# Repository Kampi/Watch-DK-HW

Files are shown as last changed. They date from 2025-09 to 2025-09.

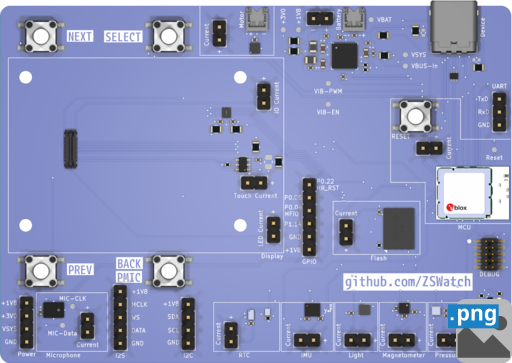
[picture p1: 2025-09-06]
production/watch-dk-RELEASED/HTML/images/cat_png_3d_viewer_top_ZSWatch-Watch-DevKit-top.png

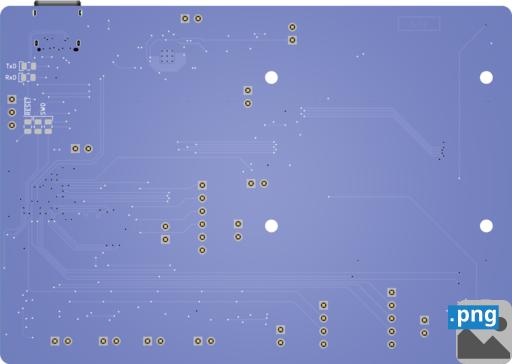
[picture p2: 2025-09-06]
production/watch-dk-RELEASED/HTML/images/cat_png_3d_viewer_bottom_ZSWatch-Watch-DevKit-bottom.png

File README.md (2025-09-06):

# ZSWatch-Watch-DevKit



## 📑 Table of Contents

- [ZSWatch-Watch-DevKit](#zswatch-watch-devkit)
  - [📑 Table of Contents](#-table-of-contents)
  - [📖 About](#-about)
  - [📂 Directory Breakdown](#-directory-breakdown)
  - [Purchasing](#purchasing)
  - [👨‍💻 Maintainer](#-maintainer)

## 📖 About

The **ZSWatch-Watch-DevKit** project provides the hardware design and production files for a smartwatch development board tailored to the ZSWatch ecosystem.
It is built with **KiCad** and integrates a full **CI/CD pipeline** using **KiBot**, ensuring reproducible outputs for documentation, manufacturing, and releases.

Key features:

- 🛠️ Open-source hardware design
- 📦 Automated generation of Gerber, BoM, and documentation via KiBot
- 🔄 Workflow stages (DRAFT → PRELIMINARY → CHECKED → RELEASED) for structured releases
- 📝 Clear documentation and changelog to track progress
- 🌍 Designed with collaboration and transparency in mind

Complete

Please check the [wiki](https://github.com/ZSWatch/ZSWatch/wiki) for more information about the project.

## 📂 Directory Breakdown

- **`.github`**: GitHub related files
- **`.gitignore`**: Ignored files list
- **`devkit`**: KiCad project for the devkit
- **`production/PCBWay`**: Manufacturing outputs (Gerbers, etc.) for PCBWay
- **`CHANGELOG.md`**: Version history
- **`LICENSE`**: Project license (GPL-3.0)
- **`README.md`**: Project overview

## Purchasing

TBD

## 👨‍💻 Maintainer

- [Daniel Kampert](mailto:danielkameprt@kampis-elektroecke.de)

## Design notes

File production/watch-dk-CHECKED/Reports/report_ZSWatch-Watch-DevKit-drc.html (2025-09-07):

Logo

| DRC report for ZSWatch-Watch-DevKit
| PCB: ZSWatch-Watch-DevKit Revision: 1.2.0+ (Unreleased) Date: 2025-09-07T20:00:18+0000 KiCad Version: 9.0.1 | Errors: 1 Warnings: 46 Total: 47

Violations

Type | Description | Details
clearance | Clearance violation (netclass 'Default' clearance 0.1250 mm; actual 0.0000 mm) | @(172.1 mm, 116.2 mm): Rectangle [] on B.Cu @(176.15 mm, 117.5 mm): PCB text '1.2.0+ (Unreleased)' on B.Cu
lib_footprint_issues | The current configuration does not include the footprint library 'Package_DFN_Kampi'. | @(253.9 mm, 171.4 mm): Footprint Q403
lib_footprint_mismatch | Footprint 'SOT-666' does not match copy in library 'Package_TO_SOT_SMD'. | @(246.8 mm, 127.7875 mm): Footprint IC602
lib_footprint_issues | The current configuration does not include the footprint library 'Wuerth'. | @(166.0 mm, 166.0 mm): Footprint S503
lib_footprint_issues | The current configuration does not include the footprint library 'Testpoints'. | @(222.2 mm, 129.2 mm): Footprint TP502
lib_footprint_issues | The current configuration does not include the footprint library 'Wuerth'. | @(166.0 mm, 120.0 mm): Footprint S504
lib_footprint_issues | The current configuration does not include the footprint library 'Samtec'. | @(253.75 mm, 162.677 mm): Footprint X601
lib_footprint_mismatch | Footprint 'QFN-32-1EP_5x5mm_P0.5mm_EP3.6x3.6mm_ThermalVias' does not match copy in library 'Package_DFN_QFN'. | @(225.38779 mm, 123.8304 mm): Footprint IC401
lib_footprint_issues | The current configuration does not include the footprint library 'Molex'. | @(208.25 mm, 116.7 mm): Footprint X509
lib_footprint_issues | The current configuration does not include the footprint library 'Broadcom'. | @(229.2925 mm, 173.55 mm): Footprint IC501
lib_footprint_issues | The current configuration does not include the footprint library 'Package_QFN'. | @(207.85 mm, 122.35 mm): Footprint IC505
lib_footprint_mismatch | Footprint 'WSON-8-1EP_8x6mm_P1.27mm_EP3.4x4.3mm' does not match copy in library 'Package_SON'. | @(235.995 mm, 157.65 mm): Footprint IC603
lib_footprint_issues | The current configuration does not include the footprint library 'Testpoints'. | @(216.4 mm, 118.7 mm): Footprint TP403
lib_footprint_issues | The current configuration does not include the footprint library 'Package_SON_Kampi'. | @(210.3 mm, 173.975 mm): Footprint IC506
lib_footprint_issues | The current configuration does not include the footprint library 'Testpoints'. | @(213.4 mm, 118.7 mm): Footprint TP404
lib_footprint_issues | The current configuration does not include the footprint library 'Knowles'. | @(168.485 mm, 173.575 mm): Footprint MK501
lib_footprint_issues | The current configuration does not include the footprint library 'Molex'. | @(227.2 mm, 116.7 mm): Footprint X402
lib_footprint_issues | The current configuration does not include the footprint library 'Micro Crystal'. | @(207.1 mm, 174.535 mm): Footprint IC507
lib_footprint_issues | The current configuration does not include the footprint library 'Package_LGA_Kampi'. | @(243.3 mm, 173.7575 mm): Footprint IC504
lib_footprint_issues | The current configuration does not include the footprint library 'Testpoints'. | @(222.2 mm, 133.3 mm): Footprint TP501
lib_footprint_mismatch | Footprint 'USB_C_Receptacle_Amphenol_12401610E4-2A' does not match copy in library 'Connector_USB'. | @(246.8 mm, 118.2 mm): Footprint X603
lib_footprint_issues | The current configuration does not include the footprint library 'Testpoints'. | @(254.7 mm, 142.2 mm): Footprint TP601
lib_footprint_issues | The current configuration does not include the footprint library 'Package_LGA_Kampi'. | @(219.1 mm, 173.55 mm): Footprint IC502
lib_footprint_issues | The current configuration does not include the footprint library 'Testpoints'. | @(172.2 mm, 172.9 mm): Footprint TP503
lib_footprint_issues | The current configuration does not include the footprint library 'Inductor_SMD_Kampi'. | @(218.73841 mm, 124.6594 mm): Footprint L401
lib_footprint_issues | The current configuration does not include the footprint library 'uBlox'. | @(251.0 mm, 150.75 mm): Footprint M601
lib_footprint_issues | The current configuration does not include the footprint library 'Package_LGA_Kampi'. | @(237.0625 mm, 173.225 mm): Footprint IC503
lib_footprint_issues | The current configuration does not include the footprint library 'Inductor_SMD_Kampi'. | @(219.24641 mm, 122.1194 mm): Footprint L402
lib_footprint_issues | The current configuration does not include the footprint library 'Wuerth'. | @(191.0 mm, 166.0 mm): Footprint S502
lib_footprint_issues | The current configuration does not include the footprint library 'Package_DFN_Kampi'. | @(252.0 mm, 177.0 mm): Footprint Q401
lib_footprint_issues | The current configuration does not include the footprint library 'Testpoints'. | @(170.2 mm, 176.6 mm): Footprint TP504
lib_footprint_issues | The current configuration does not include the footprint library 'Wuerth'. | @(191.0 mm, 120.0 mm): Footprint S501
lib_footprint_issues | The current configuration does not include the footprint library 'Testpoints'. | @(230.6 mm, 116.725 mm): Footprint TP402
lib_footprint_issues | The current configuration does not include the footprint library 'EastRising'. | @(171.7 mm, 142.1 mm): Footprint X608
lib_footprint_issues | The current configuration does not include the footprint library 'Package_QFN'. | @(202.295 mm, 134.95 mm): Footprint IC604
lib_footprint_issues | The current configuration does not include the footprint library 'Testpoints'. | @(237.3 mm, 125.8 mm): Footprint TP401
lib_footprint_issues | The current configuration does not include the footprint library 'Package_DFN_Kampi'. | @(252.0 mm, 178.2 mm): Footprint Q404
lib_footprint_issues | The current configuration does not include the footprint library 'Testpoints'. | @(237.3 mm, 123.6 mm): Footprint TP405
lib_footprint_issues | The current configuration does not include the footprint library 'Package_DFN_Kampi'. | @(253.9 mm, 174.9 mm): Footprint Q402
lib_footprint_issues | The current configuration does not include the footprint library 'Wuerth'. | @(239.3 mm, 135.7 mm): Footprint S601

Schematic parity

Type | Description | Details
duplicate_footprints | Duplicate footprints | @(163.0 mm, 157.0 mm): Footprint REF** @(205.0 mm, 157.0 mm): Footprint REF**
duplicate_footprints | Duplicate footprints | @(205.0 mm, 128.0 mm): Footprint REF** @(205.0 mm, 157.0 mm): Footprint REF**
duplicate_footprints | Duplicate footprints | @(163.0 mm, 128.0 mm): Footprint REF** @(205.0 mm, 157.0 mm): Footprint REF**
extra_footprint | Extra footprint | @(205.0 mm, 157.0 mm): Footprint REF**
extra_footprint | Extra footprint | @(163.0 mm, 157.0 mm): Footprint REF**
extra_footprint | Extra footprint | @(205.0 mm, 128.0 mm): Footprint REF**
extra_footprint | Extra footprint | @(163.0 mm, 128.0 mm): Footprint REF**

Generated by KiBot (https://github.com/INTI-CMNB/KiBot/) v1.8.4

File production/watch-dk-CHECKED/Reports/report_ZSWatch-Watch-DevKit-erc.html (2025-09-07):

Logo

| ERC report for ZSWatch-Watch-DevKit
| Schematic: ZSWatch-Watch-DevKit Revision: 1.2.0+ (Unreleased) Date: 2025-09-07T20:00:15+0000 KiCad Version: 9.0.1 | Errors: 0 Warnings: 77 Total: 77

Sheet / (ZSWatch-Watch-DevKit.kicad_sch)

Type | Description | Details
lib_symbol_issues | The current configuration does not include the symbol library 'Misc' | @(0.5207 mm, 0.3175 mm): Symbol J501 [Jumper]
footprint_link_issues | The current configuration does not include the footprint library 'Broadcom'. | @(0.3048 mm, 0.5461 mm): Symbol IC501 [APDS-9306-065]
footprint_link_issues | The current configuration does not include the footprint library 'Wuerth'. | @(0.254 mm, 1.0033 mm): Symbol S501 [SW_Push]
footprint_link_issues | The current configuration does not include the footprint library 'Wuerth'. | @(0.254 mm, 1.1176 mm): Symbol S502 [SW_Push]
footprint_link_issues | The current configuration does not include the footprint library 'Wuerth'. | @(0.254 mm, 1.2319 mm): Symbol S503 [SW_Push]
footprint_link_issues | The current configuration does not include the footprint library 'Wuerth'. | @(0.254 mm, 1.3462 mm): Symbol S504 [SW_Push]
lib_symbol_issues | The current configuration does not include the symbol library 'Misc' | @(1.0541 mm, 0.9525 mm): Symbol J502 [Jumper]
footprint_link_issues | The current configuration does not include the footprint library 'Knowles'. | @(0.8636 mm, 1.27 mm): Symbol MK501 [SPK0641HT4H-1]
lib_symbol_issues | The current configuration does not include the symbol library 'Knowles' | @(0.8636 mm, 1.27 mm): Symbol MK501 [SPK0641HT4H-1]
footprint_link_issues | The current configuration does not include the footprint library 'Testpoints'. | @(1.0541 mm, 1.2446 mm): Symbol TP503 [TestPoint]
footprint_link_issues | The current configuration does not include the footprint library 'Testpoints'. | @(1.0541 mm, 1.2954 mm): Symbol TP504 [TestPoint]
footprint_link_issues | The current configuration does not include the footprint library 'Package_LGA_Kampi'. | @(1.9558 mm, 0.7747 mm): Symbol IC502 [BMI270]
lib_symbol_issues | The current configuration does not include the symbol library 'Bosch_Kampi' | @(1.9558 mm, 0.7747 mm): Symbol IC502 [BMI270]
lib_symbol_issues | The current configuration does not include the symbol library 'Misc' | @(2.2352 mm, 0.4191 mm): Symbol J503 [Jumper]
footprint_link_issues | The current configuration does not include the footprint library 'Package_LGA_Kampi'. | @(2.7051 mm, 0.762 mm): Symbol IC504 [BMP581]
lib_symbol_issues | The current configuration does not include the symbol library 'Bosch_Kampi' | @(2.7051 mm, 0.762 mm): Symbol IC504 [BMP581]
lib_symbol_issues | The current configuration does not include the symbol library 'Misc' | @(2.9337 mm, 0.3937 mm): Symbol J505 [Jumper]
footprint_link_issues | The current configuration does not include the footprint library 'Package_LGA_Kampi'. | @(2.6162 mm, 1.5875 mm): Symbol IC503 [LIS2MDLTR]
lib_symbol_issues | The current configuration does not include the symbol library 'ST' | @(2.6162 mm, 1.5875 mm): Symbol IC503 [LIS2MDLTR]
lib_symbol_issues | The current configuration does not include the symbol library 'Misc' | @(2.9083 mm, 1.2827 mm): Symbol J504 [Jumper]
footprint_link_issues | The current configuration does not include the footprint library 'Testpoints'. | @(3.1623 mm, 0.4826 mm): Symbol TP501 [TestPoint]
footprint_link_issues | The current configuration does not include the footprint library 'Testpoints'. | @(3.1877 mm, 0.4826 mm): Symbol TP502 [TestPoint]
footprint_link_issues | The current configuration does not include the footprint library 'Package_QFN'. | @(3.3782 mm, 0.6096 mm): Symbol IC505 [DRV2603RUNT]
lib_symbol_issues | The current configuration does not include the symbol library 'Texas Instruments' | @(3.3782 mm, 0.6096 mm): Symbol IC505 [DRV2603RUNT]
lib_symbol_issues | The current configuration does not include the symbol library 'Misc' | @(3.5687 mm, 0.3429 mm): Symbol J506 [Jumper]
footprint_link_issues | The current configuration does not include the footprint library 'Molex'. | @(3.6068 mm, 0.6223 mm): Symbol X509 [Conn_01x02]
footprint_link_issues | The current configuration does not include the footprint library 'Package_SON_Kampi'. | @(3.4544 mm, 1.3081 mm): Symbol IC506 [PCA9306JK]
lib_symbol_issues | The current configuration does not include the symbol library 'NXP' | @(3.4544 mm, 1.3081 mm): Symbol IC506 [PCA9306JK]
footprint_link_issues | The current configuration does not include the footprint library 'Micro Crystal'. | @(3.81 mm, 1.3843 mm): Symbol IC507 [RV-8263-C8]
lib_symbol_issues | The current configuration does not include the symbol library 'Micro Crystal' | @(3.81 mm, 1.3843 mm): Symbol IC507 [RV-8263-C8]
lib_symbol_issues | The current configuration does not include the symbol library 'Misc' | @(4.0005 mm, 1.0668 mm): Symbol J507 [Jumper]
footprint_link_issues | The current configuration does not include the footprint library 'Testpoints'. | @(0.4191 mm, 1.1811 mm): Symbol TP601 [TestPoint]
footprint_link_issues | The current configuration does not include the footprint library 'Wuerth'. | @(0.4191 mm, 1.3081 mm): Symbol S601 [SW_Push]
footprint_link_issues | The current configuration does not include the footprint library 'uBlox'. | @(0.8636 mm, 1.1049 mm): Symbol M601 [NORA-B106]
lib_symbol_issues | The current configuration does not include the symbol library 'uBlox' | @(0.8636 mm, 1.1049 mm): Symbol M601 [NORA-B106]
footprint_link_issues | The current configuration does not include the footprint library 'uBlox'. | @(1.397 mm, 1.0287 mm): Symbol M601 [NORA-B106]
lib_symbol_issues | The current configuration does not include the symbol library 'uBlox' | @(1.397 mm, 1.0287 mm): Symbol M601 [NORA-B106]
lib_symbol_issues | The current configuration does not include the symbol library 'ON Semiconductor' | @(0.5334 mm, 1.9685 mm): Symbol IC601 [FAN5622]
footprint_link_issues | The current configuration does not include the footprint library 'uBlox'. | @(2.159 mm, 1.2319 mm): Symbol M601 [NORA-B106]
lib_symbol_issues | The current configuration does not include the symbol library 'uBlox' | @(2.159 mm, 1.2319 mm): Symbol M601 [NORA-B106]
footprint_link_issues | The current configuration does not include the footprint library 'Samtec'. | @(0.4191 mm, 2.5527 mm): Symbol X601 [Conn_ARM_JTAG_SWD_10]
lib_symbol_issues | The current configuration does not include the symbol library 'Misc' | @(2.2733 mm, 1.7145 mm): Symbol J601 [Jumper]
lib_symbol_issues | The current configuration does not include the symbol library 'Infineon' | @(2.3749 mm, 1.9939 mm): Symbol IC603 [S25FS512SAGNFI010]
lib_symbol_issues | The current configuration does not include the symbol library 'Misc' | @(3.2766 mm, 1.1684 mm): Symbol J602 [Jumper]
footprint_link_issues | The current configuration does not include the footprint library 'Package_QFN'. | @(3.5179 mm, 0.762 mm): Symbol IC604 [NTS0104GU12 (XQFN12)]
lib_symbol_issues | The current configuration does not include the symbol library 'NXP' | @(3.5179 mm, 0.762 mm): Symbol IC604 [NTS0104GU12 (XQFN12)]
footprint_link_issues | The current configuration does not include the footprint library 'EastRising'. | @(3.5433 mm, 1.4605 mm): Symbol X608 [GC9A01A_CST816S]
lib_symbol_issues | The current configuration does not include the symbol library 'Display' | @(3.5433 mm, 1.4605 mm): Symbol X608 [GC9A01A_CST816S]
lib_symbol_issues | The current configuration does not include the symbol library 'Misc' | @(3.8227 mm, 1.1684 mm): Symbol J604 [Jumper]
lib_symbol_issues | The current configuration does not include the symbol library 'Misc' | @(3.7338 mm, 1.6891 mm): Symbol J603 [Jumper]
footprint_link_issues | The current configuration does not include the footprint library 'Package_DFN_Kampi'. | @(0.2794 mm, 0.7493 mm): Symbol Q401 [PMZ550UNE]
lib_symbol_issues | The current configuration does not include the symbol library 'Nexperia' | @(0.2794 mm, 0.7493 mm): Symbol Q401 [PMZ550UNE]
footprint_link_issues | The current configuration does not include the footprint library 'Package_DFN_Kampi'. | @(0.4953 mm, 0.635 mm): Symbol Q404 [PMZB320UPE]
lib_symbol_issues | The current configuration does not include the symbol library 'Nexperia' | @(0.4953 mm, 0.635 mm): Symbol Q404 [PMZB320UPE]
footprint_link_issues | The current configuration does not include the footprint library 'Package_DFN_Kampi'. | @(0.3937 mm, 1.27 mm): Symbol Q402 [PMZ550UNE]
lib_symbol_issues | The current configuration does not include the symbol library 'Nexperia' | @(0.3937 mm, 1.27 mm): Symbol Q402 [PMZ550UNE]
footprint_link_issues | The current configuration does not include the footprint library 'Testpoints'. | @(1.4351 mm, 0.4191 mm): Symbol TP401 [TestPoint]
footprint_link_issues | The current configuration does not include the footprint library 'Package_DFN_Kampi'. | @(0.3937 mm, 1.7145 mm): Symbol Q403 [PMZ550UNE]
lib_symbol_issues | The current configuration does not include the symbol library 'Nexperia' | @(0.3937 mm, 1.7145 mm): Symbol Q403 [PMZ550UNE]
footprint_link_issues | The current configuration does not include the footprint library 'Testpoints'. | @(1.7907 mm, 0.3556 mm): Symbol TP402 [TestPoint]
lib_symbol_issues | The current configuration does not include the symbol library 'Nordic' | @(1.7018 mm, 1.0414 mm): Symbol IC401 [nPM1300-QEXX]
footprint_link_issues | The current configuration does not include the footprint library 'Molex'. | @(1.9812 mm, 0.3683 mm): Symbol X402 [Conn_01x02]
footprint_link_issues | The current configuration does not include the footprint library 'Inductor_SMD_Kampi'. | @(2.1209 mm, 1.0287 mm): Symbol L401 [L]
footprint_link_issues | The current configuration does not include the footprint library 'Inductor_SMD_Kampi'. | @(2.2098 mm, 0.8509 mm): Symbol L402 [L]
footprint_link_issues | The current configuration does not include the footprint library 'Testpoints'. | @(2.4638 mm, 0.2794 mm): Symbol TP405 [TestPoint]
footprint_link_issues | The current configuration does not include the footprint library 'Testpoints'. | @(2.5146 mm, 0.8509 mm): Symbol TP403 [TestPoint]
footprint_link_issues | The current configuration does not include the footprint library 'Testpoints'. | @(2.5146 mm, 1.0287 mm): Symbol TP404 [TestPoint]
unresolved_variable | Unresolved text variable | @(0.8636 mm, 0.3175 mm): Text Box
unresolved_variable | Unresolved text variable | @(0.889 mm, 0.3556 mm): Text Box
unresolved_variable | Unresolved text variable | @(1.524 mm, 0.3175 mm): Text Box
unresolved_variable | Unresolved text variable | @(1.5494 mm, 0.3556 mm): Text Box
unresolved_variable | Unresolved text variable | @(2.1844 mm, 0.3175 mm): Text Box
unresolved_variable | Unresolved text variable | @(2.2098 mm, 0.3556 mm): Text Box

Sheet /Project Architecture/Power Management/ (Power.kicad_sch)

Type | Description | Details
pin_to_pin | Pins of type Bidirectional and Power output are connected | @(2.032 mm, 1.2065 mm): Symbol IC401 Pin 28 [LSIN1/VINLDO1, Bidirectional, Line] @(2.032 mm, 0.7366 mm): Symbol IC401 Pin 20 [V_{SYS}, Power output, Line]
pin_to_pin | Pins of type Bidirectional and Power output are connected | @(2.032 mm, 1.2319 mm): Symbol IC401 Pin 29 [LSOUT1/VOUTLDO1, Bidirectional, Line] @(2.1463 mm, 1.2192 mm): Symbol #FLG0402 Pin 1 [Power output, Line]

Sheet /Project Architecture/Peripherals/ (Peripherals.kicad_sch)

Type | Description | Details
pin_to_pin | Pins of type Bidirectional and Power output are connected | @(1.8288 mm, 0.7239 mm): Symbol IC502 Pin 1 [SDO, Bidirectional, Line] @(2.2352 mm, 1.4351 mm): Symbol #FLG0405 Pin 1 [Power output, Line]
pin_to_pin | Pins of type Bidirectional and Power output are connected | @(2.5781 mm, 0.7366 mm): Symbol IC504 Pin 5 [SDO, Bidirectional, Line] @(2.4765 mm, 0.7747 mm): Symbol #FLG0404 Pin 1 [Power output, Line]

Generated by KiBot (https://github.com/INTI-CMNB/KiBot/) v1.8.4

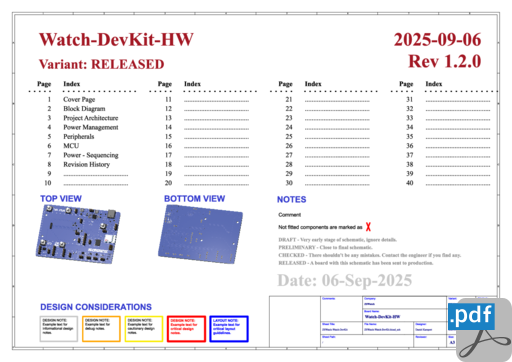
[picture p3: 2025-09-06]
production/watch-dk-RELEASED/HTML/images/cat_pdf_schematic_ZSWatch-Watch-DevKit-schematic.png

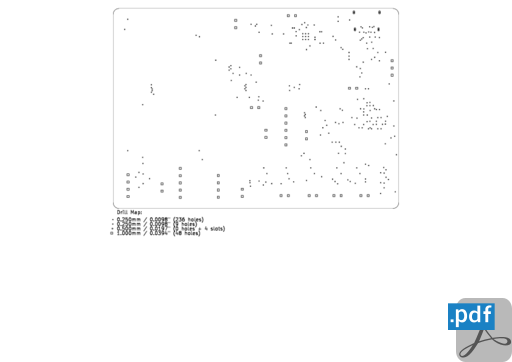
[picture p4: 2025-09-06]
production/watch-dk-RELEASED/HTML/images/cat_pdf_drill_map_ZSWatch-Watch-DevKit-PTH_drill_map.png

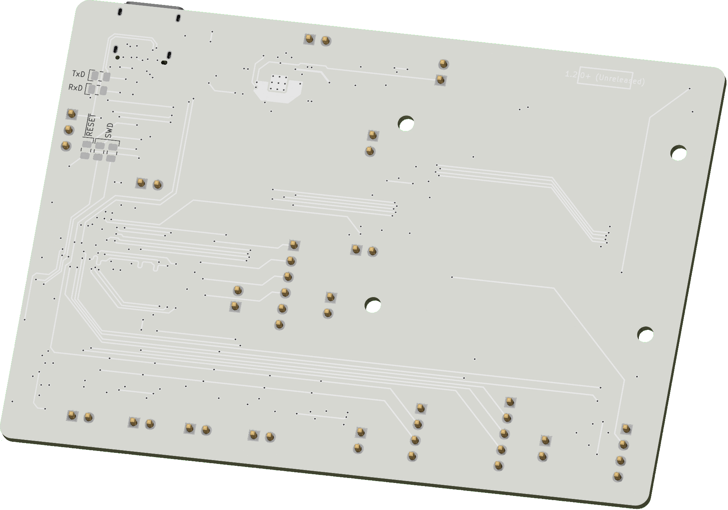
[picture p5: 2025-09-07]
production/watch-dk-CHECKED/Images/ZSWatch-Watch-DevKit-angled_bottom.png

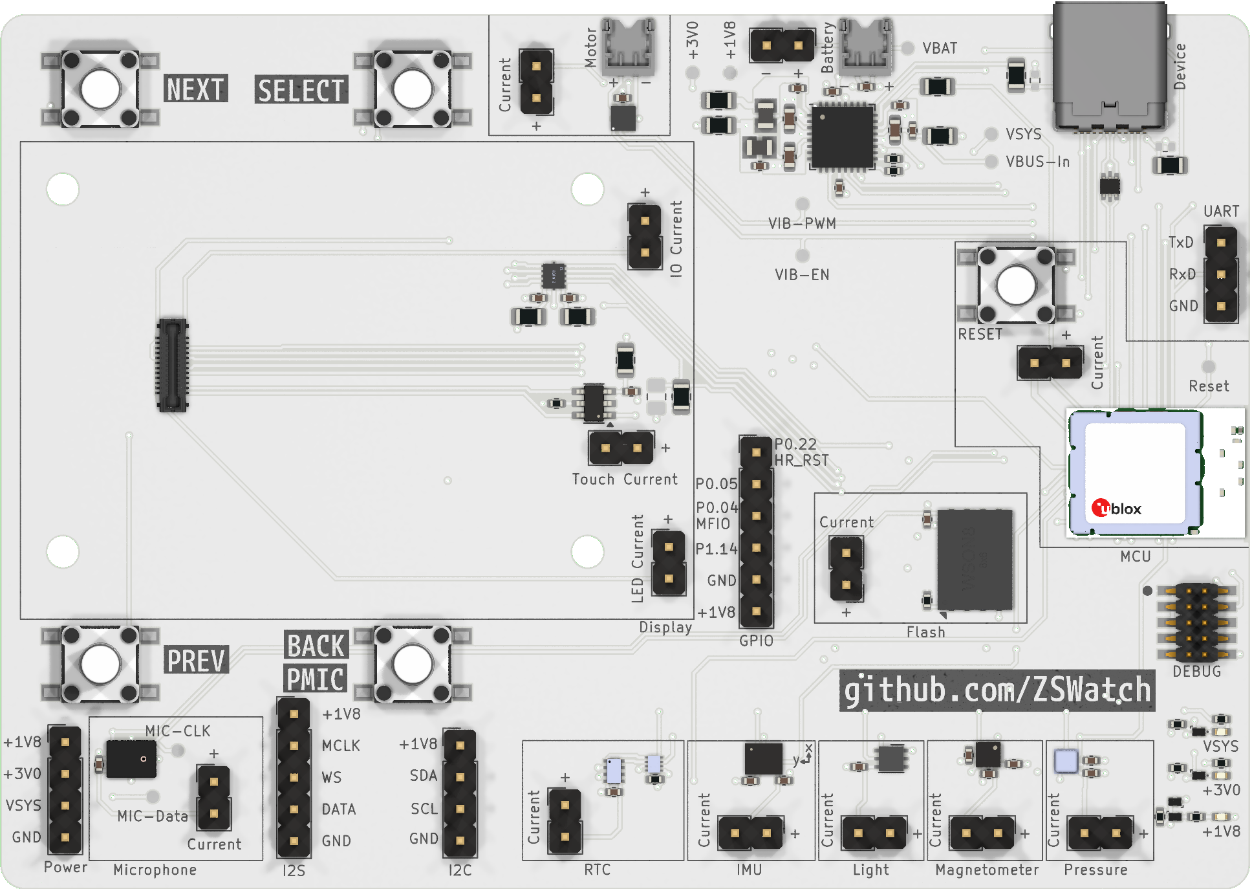
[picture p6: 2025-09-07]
production/watch-dk-CHECKED/Images/ZSWatch-Watch-DevKit-top.png

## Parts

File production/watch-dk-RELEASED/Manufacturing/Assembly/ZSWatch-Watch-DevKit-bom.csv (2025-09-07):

Row | Quantity Per PCB | References | Value | Datasheet | Footprint | Description | manf | manf# | mouser#
1 | 13 | C402 C501 C502 C503 C504 C507 C508 C509 C510 C511 C602 C603 C604 | 100n | https://datasheets.kyocera-avx.com/KGM_X7R.pdf | C_0402_1005Metric | Unpolarized capacitor, small symbol | KYOCERA AVX | 0402ZC104KAT4A | 581-0402ZC104KAT4A
2 | 1 | C505 | 220n | https://datasheets.kyocera-avx.com/KGM_X7R.pdf | C_0402_1005Metric | Unpolarized capacitor, small symbol | KYOCERA AVX | 04023C224KAT2A | 581-04023C224KAT2A
3 | 3 | C401 C404 C601 | 1u | https://datasheets.kyocera-avx.com/cx5r.pdf | C_0402_1005Metric | Unpolarized capacitor, small symbol | KYOCERA AVX | 04023D105KAT2A | 581-04023D105KAT2A
4 | 1 | C403 | 2u2 | https://datasheets.kyocera-avx.com/cx5r.pdf | C_0402_1005Metric | Unpolarized capacitor, small symbol | KYOCERA AVX | 0402ZD225MAT2A | 581-0402ZD225MAT2A
5 | 4 | C405 C407 C410 C506 | 10u | https://search.murata.co.jp/Ceramy/image/img/A01X/G101/ENG/GRJ155R60J106ME11-02A.pdf | C_0402_1005Metric | Unpolarized capacitor, small symbol | Murata Electronics | GRJ155R60J106ME11D | 81-GRJ155R60J106ME11D
6 | 3 | C406 C408 C409 | 10u | https://datasheets.kyocera-avx.com/cx5r-KGM.pdf | C_0603_1608Metric | Unpolarized capacitor, small symbol | KYOCERA AVX | KGM15CR50J106MT | 581-KGM15CR50J106MT
7 | 1 | D403 | +1V8 | https://www.mouser.de/datasheet/3/389/1/SSF-LXH100GD-RP.pdf | LED_0402_1005Metric | Light emitting diode | SML-LX0402SUGC-TR | Lumex | 696-SML-LX0402SUGCTR
8 | 1 | D401 | +3V0 | https://www.mouser.de/datasheet/3/389/1/SSF-LXH100GD-RP.pdf | LED_0402_1005Metric | Light emitting diode | SML-LX0402SUGC-TR | Lumex | 696-SML-LX0402SUGCTR
9 | 1 | D402 | VSYS | https://www.mouser.de/datasheet/3/389/1/SSF-LXH100GD-RP.pdf | LED_0402_1005Metric | Light emitting diode | SML-LX0402SUGC-TR | Lumex | 696-SML-LX0402SUGCTR
10 | 1 | IC501 | APDS-9306-065 | https://docs.broadcom.com/docs/AV02-4755EN | Broadcom_DFN-6_2x2mm_P0.65mm | Ambient Light Sensor, I2C interface, 1.7-3.6V, DFN-6 | Broadcom / Avago | APDS-9306-065 | 630-APDS-9306-065
11 | 1 | IC502 | BMI270 | https://www.bosch-sensortec.com/media/boschsensortec/downloads/datasheets/bst-bmi270-ds000.pdf | Bosch_LGA-14_3x2.5mm_P0.5mm_LayoutBorder3x4y |  | Bosch | BMI270 | 262-BMI270
12 | 1 | IC504 | BMP581 | https://www.bosch-sensortec.com/media/boschsensortec/downloads/datasheets/bst-bmp581-ds004.pdf | Bosch_LGA-10_2x2mm_P0.5mm_ClockwisePinNumbering |  | Bosch | BMP581 | 262-BMP581
13 | 1 | IC505 | DRV2603RUNT | https://www.ti.com/lit/ds/symlink/drv2603.pdf?HQS=dis-mous-null-mousermode-dsf-pf-null-wwe&ts=1692200896697 | WQFN-10_2x2mm_P0.5mm |  | Texas Instruments | DRV2603RUNT | 595-DRV2603RUNT
14 | 1 | IC601 | FAN5622SX | https://www.onsemi.com/download/data-sheet/pdf/fan5626-d.pdf | TSOT-23-6 |  | onsemi / Fairchild | FAN5622SX | 512-FAN5622SX
15 | 1 | IC503 | LIS2MDLTR | http://www.st.com/content/ccc/resource/technical/document/datasheet/group3/29/13/d1/e0/9a/4d/4f/30/DM00395193/files/DM00395193.pdf/jcr:content/translations/en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 | LGA-12_2x2mm_P0.5mm |  | STMicroelectronics | LIS2MDLTR | 511-LIS2MDLTR
16 | 1 | IC603 | MX25U51245GZ4I00 | https://www.mouser.de/datasheet/2/819/MX25U51245G_2c_1_8V_2c_512Mb_2c_v1_4-3371129.pdf | WSON-8-1EP_8x6mm_P1.27mm_EP3.4x4.3mm |  | Macronix | MX25U51245GZ4I00 | 95-25U51245GZ4I00T
17 | 1 | IC604 | NTS0104GU12 | https://www.nxp.com/docs/en/data-sheet/NTS0104.pdf | XQFN-12-1.7x2mm_P0.4mm |  | NXP Semiconductors | NTS0104GU12,115 | 771-NTS0104GU12115
18 | 1 | IC506 | PCA9306JK | https://www.nxp.com/docs/en/data-sheet/PCA9306.pdf | XSON-8_0.65x0.17mm_P0.35mm | Dual bidirectional I2C Bus and SMBus voltage level translator | NXP Semiconductors | PCA9306JKZ | 771-PCA9306JKZ
19 | 1 | IC507 | RV-8263-C8 | https://www.microcrystal.com/fileadmin/Media/Products/RTC/Datasheet/RV-8263-C8.pdf | RV-8263-C8 |  | Micro Crystal | RV-8263-C8 32.768kHz-20PPM-TA-QA | 428-204291-MC01
20 | 1 | IC602 | USBLC6-2P6 | https://www.st.com/resource/en/datasheet/usblc6-2.pdf | SOT-666 | Very low capacitance ESD protection diode, 2 data-line, SOT-666 | STMicroelectronics | USBLC6-2P6 | 511-USBLC6-2P6
21 | 1 | IC401 | nPM1300-QEXX | https://infocenter.nordicsemi.com/index.jsp?topic=%2Fstruct_pmic%2Fstruct%2Fnpm1300.html | QFN-32-1EP_5x5mm_P0.5mm_EP3.6x3.6mm_ThermalVias |  | Nordic Semiconductor | nPM1300-QEAA-R7 | 949-NPM1300-QEAA-R7
22 | 11 | J501 J502 J503 J504 J505 J506 J507 J601 J602 J603 J604 | Jumper | https://www.we-online.com/katalog/datasheet/60900213421.pdf |  | Generic jumper cap | Würth Elektronik | 60900213421 | 710-60900213421
23 | 2 | L401 L402 | 2u2 | https://www.mouser.de/datasheet/3/184/1/ASMPH-0806.pdf | L_0806_2016 | Inductor | ABRACON | ASMPH-0806-2R2M-T | 815-ASMPH-0806-2R2M-T
24 | 1 | M601 | NORA-B106 | https://www.u-blox.com/docs/UBX-20027119 | NORA-B106 |  | u-blox | NORA-B106-00B | 377-NORA-B106-00B
25 | 1 | MK501 | SPK0641HT4H-1 | https://www.knowles.com/docs/default-source/default-document-library/sph0645lm4h-1-datasheet.pdf | SPK0641HT4H-1 | Digital MEMS Microphone | Knowles | SPK0641HT4H-1 | 721-SPK0641HT4H-1
26 | 3 | Q401 Q402 Q403 | PMZ550UNEYL | https://assets.nexperia.com/documents/data-sheet/PMZ550UNE.pdf | DFN-1006-3 | 0.59A Id, 30V Vds, N-Channel MOSFET, DFN-1006-3 | Nexperia | PMZ550UNEYL | 771-PMZ550UNEYL
27 | 1 | Q404 | PMZB320UPEYL | https://assets.nexperia.com/documents/data-sheet/PMZB320UPE.pdf | DFN-1006-3 | 1A Id, 30V Vds | ROHM Semiconductor | PMZB320UPEYL | 771-PMZB320UPEYL
28 | 9 | R409 R410 R411 R412 R602 R605 R606 R615 R616 | 0R | https://www.mouser.de/datasheet/3/40/1/cr.pdf | R_0805_2012Metric | Resistor, small symbol | Bourns | CR0805-J/-000ELF | 652-CR0805-J/-000ELF
29 | 3 | R404 R405 R406 | 560R | https://www.mouser.com/catalog/specsheets/YAGEO_PYu_RC_Group_51_RoHS_L_12.pdf | R_0402_1005Metric | Resistor, small symbol | YAGEO | RC0402FR-07560RL | 603-RC0402FR-07560RL
30 | 1 | R601 | 12k | https://www.mouser.com/catalog/specsheets/YAGEO_PYu_RC_Group_51_RoHS_L_12.pdf | R_0402_1005Metric | Resistor, small symbol | YAGEO | RC0402FR-0712KL | 603-RC0402FR-0712KL
31 | 1 | R407 | 47k | https://www.mouser.com/catalog/specsheets/YAGEO_PYu_RC_Group_51_RoHS_L_12.pdf | R_0402_1005Metric | Resistor, small symbol | YAGEO | RC0402FR-0747KL | 603-RC0402FR-0747KL
32 | 6 | R401 R402 R403 R408 R502 R612 | 100k | https://www.mouser.com/catalog/specsheets/YAGEO_PYu_RC_Group_51_RoHS_L_12.pdf | R_0402_1005Metric | Resistor, small symbol | YAGEO | RC0404FR-07100KL | 603-RC0404FR-07100KL
33 | 1 | R613 | 100k | https://www.mouser.de/datasheet/3/40/1/cr.pdf | R_0805_2012Metric | Resistor, small symbol | Bourns | CR0805-J/-000ELF | 652-CR0805-J/-000ELF
34 | 1 | S601 | RESET | https://www.we-online.com/components/products/datasheet/430182050816.pdf | WS-TASV-6x6 | Push button switch, generic, two pins | Wurth Elektronik | 430182050816 | 710-430182050816
35 | 1 | S501 | SW1 | https://www.we-online.com/components/products/datasheet/430182050816.pdf | WS-TASV-6x6 | Push button switch, generic, two pins | Wurth Elektronik | 430182050816 | 710-430182050816
36 | 1 | S502 | SW2 | https://www.we-online.com/components/products/datasheet/430182050816.pdf | WS-TASV-6x6 | Push button switch, generic, two pins | Wurth Elektronik | 430182050816 | 710-430182050816
37 | 1 | S503 | SW3 | https://www.we-online.com/components/products/datasheet/430182050816.pdf | WS-TASV-6x6 | Push button switch, generic, two pins | Wurth Elektronik | 430182050816 | 710-430182050816
38 | 1 | S504 | SW4 | https://www.we-online.com/components/products/datasheet/430182050816.pdf | WS-TASV-6x6 | Push button switch, generic, two pins | Wurth Elektronik | 430182050816 | 710-430182050816
39 | 15 | X401 X403 X501 X503 X504 X505 X506 X507 X508 X510 X602 X606 X607 X609 X610 | Battery | https://cdn.amphenol-cs.com/media/wysiwyg/files/documentation/datasheet/boardwiretoboard/bwb_bergstik.pdf | PinHeader_1x02_P2.54mm_Vertical | Generic connector, single row, 01x02, script generated (kicad-library-utils/schlib/autogen/connector/) Generic connector, single row, 01x04, script generated (kicad-library-utils/schlib/autogen/connector/) | Amphenol FCI | 77311-818-02LF | 649-77311-818-02LF
40 | 2 | X402 X509 | Battery | https://www.molex.com/en-us/products/part-detail-pdf/781710002?display=pdf | 78171-0002 | Generic connector, single row, 01x02, script generated (kicad-library-utils/schlib/autogen/connector/) | Molex | 78171-0002 | 538-78171-0002
41 | 1 | X601 | DEBUG | http://infocenter.arm.com/help/topic/com.arm.doc.ddi0314h/DDI0314H_coresight_components_trm.pdf | SHF-105-01-L-D-SM-TR | Cortex Debug Connector, standard ARM Cortex-M SWD and JTAG interface | Wurth Elektronik | 62101021021 | 710-62101021021
42 | 1 | X603 | Device | https://www.usb.org/sites/default/files/documents/usb_type-c.zip | USB_C_Receptacle_Amphenol_12401610E4-2A | USB Full-Featured Type-C Receptacle connector | Amphenol Commercial Products | 12401610E4#2A | 523-12401610E4#2A
43 | 1 | X608 | Display | https://www.buydisplay.com/download/manual/ER-TFT1.28-2_Datasheet.pdf | ER-CON0.4-24P |  | EastRising | OK-24F024-04
44 | 1 | X605 | GPIO | ~https://cdn.amphenol-cs.com/media/wysiwyg/files/documentation/datasheet/boardwiretoboard/bwb_bergstik.pdf | PinHeader_1x06_P2.54mm_Vertical | Generic connector, single row, 01x06, script generated (kicad-library-utils/schlib/autogen/connector/) | Amphenol FCI | 77311-802-06LF | 649-77311-802-06LF
45 | 1 | X502 | I2S | https://cdn.amphenol-cs.com/media/wysiwyg/files/documentation/datasheet/boardwiretoboard/bwb_bergstik.pdf | PinHeader_1x05_P2.54mm_Vertical | Generic connector, single row, 01x05, script generated (kicad-library-utils/schlib/autogen/connector/) | Amphenol FCI | 77311-818-05LF | 649-77311-818-05LF
46 | 1 | X604 | UART | https://cdn.amphenol-cs.com/media/wysiwyg/files/documentation/datasheet/boardwiretoboard/bwb_bergstik.pdf | PinHeader_1x03_P2.54mm_Vertical | Generic connector, single row, 01x03, script generated (kicad-library-utils/schlib/autogen/connector/) | Amphenol FCI | 77311-818-03LF | 649-77311-818-03LF

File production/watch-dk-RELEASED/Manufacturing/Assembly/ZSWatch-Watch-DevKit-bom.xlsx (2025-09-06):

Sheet: BoM
Bill of Materials
Schematic: | ZSWatch-Watch-DevKit | Component Groups: | 47
Variant: | RELEASED | Component Count: | 108 (79 SMD/ 18 THT)
Revision: |  | Fitted Components: | 108 (79 SMD/ 18 THT)
Date: | 2025-07-13 | Number of PCBs: | 1
KiCad Version: | 9.0.1+1 | Total Components: | 108
Row | Quantity Per PCB | References | Value | Datasheet | Footprint | Description | manf | manf#
1 | 13 | C402 C501 C502 C503 C504 C507 C508 C509 C510 C511 C602 C603 C604 | 100n | https://datasheets.kyocera-avx.com/KGM_X7R.pdf | C_0402_1005Metric | Unpolarized capacitor, small symbol | KYOCERA AVX | 0402ZC104KAT4A
2 | 1 | C505 | 220n | https://datasheets.kyocera-avx.com/KGM_X7R.pdf | C_0402_1005Metric | Unpolarized capacitor, small symbol | KYOCERA AVX | 04023C224KAT2A
3 | 3 | C401 C404 C601 | 1u | https://datasheets.kyocera-avx.com/cx5r.pdf | C_0402_1005Metric | Unpolarized capacitor, small symbol | KYOCERA AVX | 04023D105KAT2A
4 | 1 | C403 | 2u2 | https://datasheets.kyocera-avx.com/cx5r.pdf | C_0402_1005Metric | Unpolarized capacitor, small symbol | KYOCERA AVX | 0402ZD225MAT2A
5 | 4 | C405 C407 C410 C506 | 10u | https://search.murata.co.jp/Ceramy/image/img/A01X/G101/ENG/GRJ155R60J106ME11-02A.pdf | C_0402_1005Metric | Unpolarized capacitor, small symbol | Murata Electronics | GRJ155R60J106ME11D
6 | 3 | C406 C408 C409 | 10u | https://datasheets.kyocera-avx.com/cx5r-KGM.pdf | C_0603_1608Metric | Unpolarized capacitor, small symbol | KYOCERA AVX | KGM15CR50J106MT
7 | 1 | D403 | +1V8 | https://www.mouser.de/datasheet/3/389/1/SSF-LXH100GD-RP.pdf | LED_0402_1005Metric | Light emitting diode | SML-LX0402SUGC-TR | Lumex
8 | 1 | D401 | +3V0 | https://www.mouser.de/datasheet/3/389/1/SSF-LXH100GD-RP.pdf | LED_0402_1005Metric | Light emitting diode | SML-LX0402SUGC-TR | Lumex
9 | 1 | D402 | VSYS | https://www.mouser.de/datasheet/3/389/1/SSF-LXH100GD-RP.pdf | LED_0402_1005Metric | Light emitting diode | SML-LX0402SUGC-TR | Lumex
10 | 1 | IC501 | APDS-9306-065 | https://docs.broadcom.com/docs/AV02-4755EN | Broadcom_DFN-6_2x2mm_P0.65mm | Ambient Light Sensor, I2C interface, 1.7-3.6V, DFN-6 | Broadcom / Avago | APDS-9306-065
11 | 1 | IC502 | BMI270 | https://www.bosch-sensortec.com/media/boschsensortec/downloads/datasheets/bst-bmi270-ds000.pdf | Bosch_LGA-14_3x2.5mm_P0.5mm_LayoutBorder3x4y |  | Bosch | BMI270
12 | 1 | IC504 | BMP581 | https://www.bosch-sensortec.com/media/boschsensortec/downloads/datasheets/bst-bmp581-ds004.pdf | Bosch_LGA-10_2x2mm_P0.5mm_ClockwisePinNumbering |  | Bosch | BMP581
13 | 1 | IC505 | DRV2603RUNT | https://www.ti.com/lit/ds/symlink/drv2603.pdf?HQS=dis-mous-null-mousermode-dsf-pf-null-wwe&ts=1692200896697 | WQFN-10_2x2mm_P0.5mm |  | Texas Instruments | DRV2603RUNT
14 | 1 | IC601 | FAN5622SX | https://www.onsemi.com/download/data-sheet/pdf/fan5626-d.pdf | TSOT-23-6 |  | onsemi / Fairchild | FAN5622SX
15 | 1 | IC503 | LIS2MDLTR | http://www.st.com/content/ccc/resource/technical/document/datasheet/group3/29/13/d1/e0/9a/4d/4f/30/DM00395193/files/DM00395193.pdf/jcr:content/translations/en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 | LGA-12_2x2mm_P0.5mm |  | STMicroelectronics | LIS2MDLTR
16 | 1 | IC603 | MX25U51245GZ4I00 | https://www.mouser.de/datasheet/2/819/MX25U51245G_2c_1_8V_2c_512Mb_2c_v1_4-3371129.pdf | WSON-8-1EP_8x6mm_P1.27mm_EP3.4x4.3mm |  | Macronix | MX25U51245GZ4I00
17 | 1 | IC604 | NTS0104GU12 | https://www.nxp.com/docs/en/data-sheet/NTS0104.pdf | XQFN-12-1.7x2mm_P0.4mm |  | NXP Semiconductors | NTS0104GU12,115
18 | 1 | IC506 | PCA9306JK | https://www.nxp.com/docs/en/data-sheet/PCA9306.pdf | XSON-8_0.65x0.17mm_P0.35mm | Dual bidirectional I2C Bus and SMBus voltage level translator | NXP Semiconductors | PCA9306JKZ
19 | 1 | IC507 | RV-8263-C8 | https://www.microcrystal.com/fileadmin/Media/Products/RTC/Datasheet/RV-8263-C8.pdf | RV-8263-C8 |  | Micro Crystal | RV-8263-C8 32.768kHz-20PPM-TA-QA
20 | 1 | IC602 | USBLC6-2P6 | https://www.st.com/resource/en/datasheet/usblc6-2.pdf | SOT-666 | Very low capacitance ESD protection diode, 2 data-line, SOT-666 | STMicroelectronics | USBLC6-2P6
21 | 1 | IC401 | nPM1300-QEXX | https://infocenter.nordicsemi.com/index.jsp?topic=%2Fstruct_pmic%2Fstruct%2Fnpm1300.html | QFN-32-1EP_5x5mm_P0.5mm_EP3.6x3.6mm_ThermalVias |  | Nordic Semiconductor | nPM1300-QEAA-R7
22 | 11 | J501 J502 J503 J504 J505 J506 J507 J601 J602 J603 J604 | Jumper | https://www.we-online.com/katalog/datasheet/60900213421.pdf |  | Generic jumper cap | Würth Elektronik | 60900213421
23 | 2 | L401 L402 | 2u2 | https://www.mouser.de/datasheet/3/184/1/ASMPH-0806.pdf | L_0806_2016 | Inductor | ABRACON | ASMPH-0806-2R2M-T
24 | 1 | M601 | NORA-B106 | https://www.u-blox.com/docs/UBX-20027119 | NORA-B106 |  | u-blox | NORA-B106-00B
25 | 1 | MK501 | SPK0641HT4H-1 | https://www.knowles.com/docs/default-source/default-document-library/sph0645lm4h-1-datasheet.pdf | SPK0641HT4H-1 | Digital MEMS Microphone | Knowles | SPK0641HT4H-1
26 | 3 | Q401 Q402 Q403 | PMZ550UNEYL | https://assets.nexperia.com/documents/data-sheet/PMZ550UNE.pdf | DFN-1006-3 | 0.59A Id, 30V Vds, N-Channel MOSFET, DFN-1006-3 | Nexperia | PMZ550UNEYL
27 | 1 | Q404 | PMZB320UPEYL | https://assets.nexperia.com/documents/data-sheet/PMZB320UPE.pdf | DFN-1006-3 | 1A Id, 30V Vds | ROHM Semiconductor | PMZB320UPEYL
28 | 9 | R409 R410 R411 R412 R602 R605 R606 R615 R616 | 0R | https://www.mouser.de/datasheet/3/40/1/cr.pdf | R_0805_2012Metric | Resistor, small symbol | Bourns | CR0805-J/-000ELF
29 | 3 | R404 R405 R406 | 560R | https://www.mouser.com/catalog/specsheets/YAGEO_PYu_RC_Group_51_RoHS_L_12.pdf | R_0402_1005Metric | Resistor, small symbol | YAGEO | RC0402FR-07560RL
30 | 1 | R601 | 12k | https://www.mouser.com/catalog/specsheets/YAGEO_PYu_RC_Group_51_RoHS_L_12.pdf | R_0402_1005Metric | Resistor, small symbol | YAGEO | RC0402FR-0712KL
31 | 1 | R407 | 47k | https://www.mouser.com/catalog/specsheets/YAGEO_PYu_RC_Group_51_RoHS_L_12.pdf | R_0402_1005Metric | Resistor, small symbol | YAGEO | RC0402FR-0747KL
32 | 6 | R401 R402 R403 R408 R502 R612 | 100k | https://www.mouser.com/catalog/specsheets/YAGEO_PYu_RC_Group_51_RoHS_L_12.pdf | R_0402_1005Metric | Resistor, small symbol | YAGEO | RC0404FR-07100KL
33 | 1 | R613 | 100k | https://www.mouser.de/datasheet/3/40/1/cr.pdf | R_0805_2012Metric | Resistor, small symbol | Bourns | CR0805-J/-000ELF
34 | 1 | S601 | RESET | https://www.we-online.com/components/products/datasheet/430182050816.pdf | WS-TASV-6x6 | Push button switch, generic, two pins | Wurth Elektronik | 430182050816
35 | 1 | S501 | SW1 | https://www.we-online.com/components/products/datasheet/430182050816.pdf | WS-TASV-6x6 | Push button switch, generic, two pins | Wurth Elektronik | 430182050816
36 | 1 | S502 | SW2 | https://www.we-online.com/components/products/datasheet/430182050816.pdf | WS-TASV-6x6 | Push button switch, generic, two pins | Wurth Elektronik | 430182050816
37 | 1 | S503 | SW3 | https://www.we-online.com/components/products/datasheet/430182050816.pdf | WS-TASV-6x6 | Push button switch, generic, two pins | Wurth Elektronik | 430182050816
38 | 1 | S504 | SW4 | https://www.we-online.com/components/products/datasheet/430182050816.pdf | WS-TASV-6x6 | Push button switch, generic, two pins | Wurth Elektronik | 430182050816
39 | 13 | X401 X501 X503 X505 X506 X507 X508 X510 X602 X606 X607 X609 X610 | Battery | https://cdn.amphenol-cs.com/media/wysiwyg/files/documentation/datasheet/boardwiretoboard/bwb_bergstik.pdf | PinHeader_1x02_P2.54mm_Vertical | Generic connector, single row, 01x02, script generated (kicad-library-utils/schlib/autogen/connector/) | Amphenol FCI | 77311-818-02LF
40 | 2 | X402 X509 | Battery | https://www.molex.com/en-us/products/part-detail-pdf/781710002?display=pdf | 78171-0002 | Generic connector, single row, 01x02, script generated (kicad-library-utils/schlib/autogen/connector/) | Molex | 78171-0002
41 | 1 | X601 | DEBUG | http://infocenter.arm.com/help/topic/com.arm.doc.ddi0314h/DDI0314H_coresight_components_trm.pdf | SHF-105-01-L-D-SM-TR | Cortex Debug Connector, standard ARM Cortex-M SWD and JTAG interface | Wurth Elektronik | 62101021021
42 | 1 | X603 | Device | https://www.usb.org/sites/default/files/documents/usb_type-c.zip | USB_C_Receptacle_Amphenol_12401610E4-2A | USB Full-Featured Type-C Receptacle connector | Amphenol Commercial Products | 12401610E4#2A
43 | 1 | X608 | Display | https://www.buydisplay.com/download/manual/ER-TFT1.28-2_Datasheet.pdf | ER-CON0.4-24P |  | EastRising | OK-24F024-04
44 | 1 | X605 | GPIO | ~https://cdn.amphenol-cs.com/media/wysiwyg/files/documentation/datasheet/boardwiretoboard/bwb_bergstik.pdf | PinHeader_1x06_P2.54mm_Vertical | Generic connector, single row, 01x06, script generated (kicad-library-utils/schlib/autogen/connector/) | Amphenol FCI | 77311-802-06LF
45 | 1 | X502 | I2S | https://cdn.amphenol-cs.com/media/wysiwyg/files/documentation/datasheet/boardwiretoboard/bwb_bergstik.pdf | PinHeader_1x05_P2.54mm_Vertical | Generic connector, single row, 01x05, script generated (kicad-library-utils/schlib/autogen/connector/) | Amphenol FCI | 77311-818-05LF
46 | 2 | X403 X504 | Power | https://cdn.amphenol-cs.com/media/wysiwyg/files/documentation/datasheet/boardwiretoboard/bwb_bergstik.pdf | PinHeader_1x04_P2.54mm_Vertical | Generic connector, single row, 01x04, script generated (kicad-library-utils/schlib/autogen/connector/) | Amphenol FCI | 77311-818-02LF
47 | 1 | X604 | UART | https://cdn.amphenol-cs.com/media/wysiwyg/files/documentation/datasheet/boardwiretoboard/bwb_bergstik.pdf | PinHeader_1x03_P2.54mm_Vertical | Generic connector, single row, 01x03, script generated (kicad-library-utils/schlib/autogen/connector/) | Amphenol FCI | 77311-818-03LF

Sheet: Costs
Bill of Materials
Schematic: | ZSWatch-Watch-DevKit |  |  |  |  | Board Qty: | 1
Variant: | RELEASED |  |  |  |  | Unit Cost: | $41.61
Revision: |  |  |  |  |  | Total Cost: | $41.61 |  |  |  |  | $41.61 | 31 of 47 parts found
Date: | 2025-07-13
KiCad Version: | 9.0.1+1
Global Part Info |  |  |  |  |  |  |  | Mouser
References | Value | Footprint | Manf | Manf# | Build Quantity | Unit$ | Ext$ | Avail | Purch | Unit$ | MOQ | Ext$ | Cat#
C402 C501 C502 C503 C504 C507 C508 C509 C510 C511 C602 C603 C604 | 100n | C_0402_1005Metric | KYOCERA AVX | 0402ZC104KAT4A (https://datasheets.kyocera-avx.com/KGM_X7R.pdf) | 13 | $0.033 | $0.43 | 40920 |  | $0.033 | 1 | $0.43 | 581-0402ZC104KAT4A (https://www.mouser.de/ProductDetail/KYOCERA-AVX/0402ZC104KAT4A?qs=U0WCSYU1dIfUbdc9rwYMdg%3D%3D)
C505 | 220n | C_0402_1005Metric | KYOCERA AVX | 04023C224KAT2A (https://datasheets.kyocera-avx.com/KGM_X7R.pdf) | 1 | $0.372 | $0.37 | 14780 |  | $0.372 | 1 | $0.37 | 581-04023C224KAT2A (https://www.mouser.de/ProductDetail/KYOCERA-AVX/04023C224KAT2A?qs=5aG0NVq1C4xPiFAUpyWZQQ%3D%3D)
C401 C404 C601 | 1u | C_0402_1005Metric | KYOCERA AVX | 04023D105KAT2A (https://datasheets.kyocera-avx.com/cx5r.pdf) | 3 | $0.111 | $0.33 | 174880 |  | $0.111 | 1 | $0.33 | 581-04023D105KAT2A (https://www.mouser.de/ProductDetail/KYOCERA-AVX/04023D105KAT2A?qs=%252BdQmOuGyFcETexelcKkD5g%3D%3D)
C403 | 2u2 | C_0402_1005Metric | KYOCERA AVX | 0402ZD225MAT2A (https://datasheets.kyocera-avx.com/cx5r.pdf) | 1 | $0.120 | $0.12 | 8352 |  | $0.120 | 1 | $0.12 | 581-0402ZD225MAT2A (https://www.mouser.de/ProductDetail/KYOCERA-AVX/0402ZD225MAT2A?qs=ZBeOGGPQgEESIGO3bvTmzg%3D%3D)
C405 C407 C410 C506 | 10u | C_0402_1005Metric | Murata Electronics | GRJ155R60J106ME11D (https://search.murata.co.jp/Ceramy/image/img/A01X/G101/ENG/GRJ155R60J106ME11-02A.pdf) | 4
C406 C408 C409 | 10u | C_0603_1608Metric | KYOCERA AVX | KGM15CR50J106MT (https://datasheets.kyocera-avx.com/cx5r-KGM.pdf) | 3 | $0.191 | $0.57 | 5230 |  | $0.191 | 1 | $0.57 | 581-KGM15CR50J106MT (https://www.mouser.de/ProductDetail/KYOCERA-AVX/KGM15CR50J106MT?qs=Jm2GQyTW%2Fbif%2Fz3WIqU0uQ%3D%3D)
D403 | +1V8 | LED_0402_1005Metric | SML-LX0402SUGC-TR | Lumex (https://www.mouser.de/datasheet/3/389/1/SSF-LXH100GD-RP.pdf) | 1 | $0.523 | $0.52 | 24493 |  | $0.523 | 1 | $0.52 | 696-SML-LX0402SUGCTR (https://www.mouser.de/ProductDetail/Lumex/SML-LX0402SUGC-TR?qs=CpNDN%2FcFIdcI%252BZNfbfZN3g%3D%3D)
D401 | +3V0 | LED_0402_1005Metric | SML-LX0402SUGC-TR | Lumex (https://www.mouser.de/datasheet/3/389/1/SSF-LXH100GD-RP.pdf) | 1 | $0.523 | $0.52 | 24493 |  | $0.523 | 1 | $0.52 | 696-SML-LX0402SUGCTR (https://www.mouser.de/ProductDetail/Lumex/SML-LX0402SUGC-TR?qs=CpNDN%2FcFIdcI%252BZNfbfZN3g%3D%3D)
D402 | VSYS | LED_0402_1005Metric | SML-LX0402SUGC-TR | Lumex (https://www.mouser.de/datasheet/3/389/1/SSF-LXH100GD-RP.pdf) | 1 | $0.523 | $0.52 | 24493 |  | $0.523 | 1 | $0.52 | 696-SML-LX0402SUGCTR (https://www.mouser.de/ProductDetail/Lumex/SML-LX0402SUGC-TR?qs=CpNDN%2FcFIdcI%252BZNfbfZN3g%3D%3D)
IC501 | APDS-9306-065 | Broadcom_DFN-6_2x2mm_P0.65mm | Broadcom / Avago | APDS-9306-065 (https://docs.broadcom.com/docs/AV02-4755EN) | 1 | $0.986 | $0.99 | 15026 |  | $0.986 | 1 | $0.99 | 630-APDS-9306-065 (https://www.mouser.de/ProductDetail/Broadcom-Avago/APDS-9306-065?qs=JUmsgfbaopRTut8Cx4p19A%3D%3D)
IC502 | BMI270 | Bosch_LGA-14_3x2.5mm_P0.5mm_LayoutBorder3x4y | Bosch | BMI270 (https://www.bosch-sensortec.com/media/boschsensortec/downloads/datasheets/bst-bmi270-ds000.pdf) | 1 | $3.766 | $3.77 | 18213 |  | $3.766 | 1 | $3.77 | 262-BMI270 (https://www.mouser.de/ProductDetail/Bosch-Sensortec/BMI270?qs=u16ybLDytRYIj%252BjQEee88A%3D%3D)
IC504 | BMP581 | Bosch_LGA-10_2x2mm_P0.5mm_ClockwisePinNumbering | Bosch | BMP581 (https://www.bosch-sensortec.com/media/boschsensortec/downloads/datasheets/bst-bmp581-ds004.pdf) | 1 | $2.994 | $2.99 | 19739 |  | $2.994 | 1 | $2.99 | 262-BMP581 (https://www.mouser.de/ProductDetail/Bosch-Sensortec/BMP581?qs=Li%252BoUPsLEntPL9tlFmcgXg%3D%3D)
IC505 | DRV2603RUNT | WQFN-10_2x2mm_P0.5mm | Texas Instruments | DRV2603RUNT (https://www.ti.com/lit/ds/symlink/drv2603.pdf?HQS=dis-mous-null-mousermode-dsf-pf-null-wwe&ts=1692200896697) | 1 | $1.626 | $1.63 | 1042 |  | $1.626 | 1 | $1.63 | 595-DRV2603RUNT (https://www.mouser.de/ProductDetail/Texas-Instruments/DRV2603RUNT?qs=y0LsnOHuQQ66fXxKAgGo4A%3D%3D)
IC601 | FAN5622SX | TSOT-23-6 | onsemi / Fairchild | FAN5622SX (https://www.onsemi.com/download/data-sheet/pdf/fan5626-d.pdf) | 1 | $1.193 | $1.19 | 13658 |  | $1.193 | 1 | $1.19 | 512-FAN5622SX (https://www.mouser.de/ProductDetail/onsemi-Fairchild/FAN5622SX?qs=kDD%2FdQe9TTcQ2FOj0Q0xJA%3D%3D)
IC503 | LIS2MDLTR | LGA-12_2x2mm_P0.5mm | STMicroelectronics | LIS2MDLTR (http://www.st.com/content/ccc/resource/technical/document/datasheet/group3/29/13/d1/e0/9a/4d/4f/30/DM00395193/files/DM00395193.pdf/jcr:content/translations/en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) | 1 | $2.152 | $2.15 | 6317 |  | $2.152 | 1 | $2.15 | 511-LIS2MDLTR (https://www.mouser.de/ProductDetail/STMicroelectronics/LIS2MDLTR?qs=5aG0NVq1C4wS0n6b5NiBNQ%3D%3D)
IC603 | MX25U51245GZ4I00 | WSON-8-1EP_8x6mm_P1.27mm_EP3.4x4.3mm | Macronix | MX25U51245GZ4I00 (https://www.mouser.de/datasheet/2/819/MX25U51245G_2c_1_8V_2c_512Mb_2c_v1_4-3371129.pdf) | 1 |  |  | NonStk |  |  | 4800 |  | 95-25U51245GZ4I00T (https://www.mouser.de/ProductDetail/Macronix/MX25U51245GZ4I00-T?qs=mELouGlnn3eDhn5HUfyQFw%3D%3D)
IC604 | NTS0104GU12 | XQFN-12-1.7x2mm_P0.4mm | NXP Semiconductors | NTS0104GU12,115 (https://www.nxp.com/docs/en/data-sheet/NTS0104.pdf) | 1 | $1.036 | $1.04 | 11301 |  | $1.036 | 1 | $1.04 | 771-NTS0104GU12115 (https://www.mouser.de/ProductDetail/NXP-Semiconductors/NTS0104GU12115?qs=A1cBxND5mHLxKBBpk2Em8w%3D%3D)
IC506 | PCA9306JK | XSON-8_0.65x0.17mm_P0.35mm | NXP Semiconductors | PCA9306JKZ (https://www.nxp.com/docs/en/data-sheet/PCA9306.pdf) | 1 | $0.664 | $0.66 | 8349 |  | $0.664 | 1 | $0.66 | 771-PCA9306JKZ (https://www.mouser.de/ProductDetail/NXP-Semiconductors/PCA9306JKZ?qs=2SLPxufLcgDRMLW40GZIdg%3D%3D)
IC507 | RV-8263-C8 | RV-8263-C8 | Micro Crystal | RV-8263-C8 32.768kHz-20PPM-TA-QA (https://www.microcrystal.com/fileadmin/Media/Products/RTC/Datasheet/RV-8263-C8.pdf) | 1 | $2.105 | $2.11 | 1693 |  | $2.105 | 1 | $2.11 | 428-204291-MC01 (https://www.mouser.de/ProductDetail/Micro-Crystal/RV-8263-C8-32.768kHz-20PPM-TA-QA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)
IC602 | USBLC6-2P6 | SOT-666 | STMicroelectronics | USBLC6-2P6 (https://www.st.com/resource/en/datasheet/usblc6-2.pdf) | 1 | $0.442 | $0.44 | NonStk |  | $0.442 | 1 | $0.44 | 511-USBLC6-2P6 (https://www.mouser.de/ProductDetail/STMicroelectronics/USBLC6-2P6?qs=6ARB0lp6jlViGcbUSvj1Mw%3D%3D)
IC401 | nPM1300-QEXX | QFN-32-1EP_5x5mm_P0.5mm_EP3.6x3.6mm_ThermalVias | Nordic Semiconductor | nPM1300-QEAA-R7 (https://infocenter.nordicsemi.com/index.jsp?topic=%2Fstruct_pmic%2Fstruct%2Fnpm1300.html) | 1 | $4.152 | $4.15 | 2511 |  | $4.152 | 1 | $4.15 | 949-NPM1300-QEAA-R7 (https://www.mouser.de/ProductDetail/Nordic-Semiconductor/nPM1300-QEAA-R7?qs=3pZoU%2F6IRTj0hxAp51B2zA%3D%3D)
J501 J502 J503 J504 J505 J506 J507 J601 J602 J603 J604 | Jumper |  | Würth Elektronik | 60900213421 (https://www.we-online.com/katalog/datasheet/60900213421.pdf) | 11 | $0.281 | $3.09 | 58985 |  | $0.281 | 1 | $3.09 | 710-60900213421 (https://www.mouser.de/ProductDetail/Wurth-Elektronik/60900213421?qs=W%252B2sBeLta1bsO5t19%2FBN7Q%3D%3D)
L401 L402 | 2u2 | L_0806_2016 | ABRACON | ASMPH-0806-2R2M-T (https://www.mouser.de/datasheet/3/184/1/ASMPH-0806.pdf) | 2 | $0.302 | $0.60 | 4740 |  | $0.302 | 1 | $0.60 | 815-ASMPH-0806-2R2MT (https://www.mouser.de/ProductDetail/ABRACON/ASMPH-0806-2R2M-T?qs=73bO73rho2gUhCeImyNTuw%3D%3D)
M601 | NORA-B106 | NORA-B106 | u-blox | NORA-B106-00B (https://www.u-blox.com/docs/UBX-20027119) | 1 | $9.159 | $9.16 | 115 |  | $9.159 | 1 | $9.16 | 377-NORA-B106-00B (https://www.mouser.de/ProductDetail/u-blox/NORA-B106-00B?qs=T94vaHKWudSCPE72v3os%252Bg%3D%3D)
MK501 | SPK0641HT4H-1 | SPK0641HT4H-1 | Knowles | SPK0641HT4H-1 (https://www.knowles.com/docs/default-source/default-document-library/sph0645lm4h-1-datasheet.pdf) | 1 | $1.404 | $1.40 | 26681 |  | $1.404 | 1 | $1.40 | 721-SPK0641HT4H-1 (https://www.mouser.de/ProductDetail/Syntiant/SPK0641HT4H-1?qs=fAHHVMwC%252BbgQkuKPcedJGQ%3D%3D)
Q401 Q402 Q403 | PMZ550UNEYL | DFN-1006-3 | Nexperia | PMZ550UNEYL (https://assets.nexperia.com/documents/data-sheet/PMZ550UNE.pdf) | 3 | $0.342 | $1.02 | 162826 |  | $0.342 | 1 | $1.02 | 771-PMZ550UNEYL (https://www.mouser.de/ProductDetail/Nexperia/PMZ550UNEYL?qs=d7b8vw%252BBfo0cI9ZzM5Blzg%3D%3D)
Q404 | PMZB320UPEYL | DFN-1006-3 | ROHM Semiconductor | PMZB320UPEYL (https://assets.nexperia.com/documents/data-sheet/PMZB320UPE.pdf) | 1 | $0.312 | $0.31 | 32837 |  | $0.312 | 1 | $0.31 | 771-PMZB320UPEYL (https://www.mouser.de/ProductDetail/Nexperia/PMZB320UPEYL?qs=d7b8vw%252BBfo3qFKLhpfjnHw%3D%3D)
R409 R410 R411 R412 R602 R605 R606 R615 R616 | 0R | R_0805_2012Metric | Bourns | CR0805-J/-000ELF (https://www.mouser.de/datasheet/3/40/1/cr.pdf) | 9 | $0.101 | $0.91 | 129804 |  | $0.101 | 1 | $0.91 | 652-CR0805-J/-000ELF (https://www.mouser.de/ProductDetail/Bourns/CR0805-J-000ELF?qs=wKk%252BLl0qPROQEEzWY8Q13A%3D%3D)
R404 R405 R406 | 560R | R_0402_1005Metric | YAGEO | RC0402FR-07560RL (https://www.mouser.com/catalog/specsheets/YAGEO_PYu_RC_Group_51_RoHS_L_12.pdf) | 3 | $0.101 | $0.30 | NonStk |  | $0.101 | 1 | $0.30 | 603-RC0402FR-07560RL (https://www.mouser.de/ProductDetail/YAGEO/RC0402FR-07560RL?qs=Is6ZsIPfHkaar5c8drXNXg%3D%3D)
R601 | 12k | R_0402_1005Metric | YAGEO | RC0402FR-0712KL (https://www.mouser.com/catalog/specsheets/YAGEO_PYu_RC_Group_51_RoHS_L_12.pdf) | 1 | $0.101 | $0.10 | 137945 |  | $0.101 | 1 | $0.10 | 603-RC0402FR-0712KL (https://www.mouser.de/ProductDetail/YAGEO/RC0402FR-0712KL?qs=sxZXDnvRBEiY5XbuK7n6Dw%3D%3D)
R407 | 47k | R_0402_1005Metric | YAGEO | RC0402FR-0747KL (https://www.mouser.com/catalog/specsheets/YAGEO_PYu_RC_Group_51_RoHS_L_12.pdf) | 1 | $0.101 | $0.10 | 205238 |  | $0.101 | 1 | $0.10 | 603-RC0402FR-0747KL (https://www.mouser.de/ProductDetail/YAGEO/RC0402FR-0747KL?qs=V1yeUXFNrklslMUO6Zhx5g%3D%3D)
R401 R402 R403 R408 R502 R612 | 100k | R_0402_1005Metric | YAGEO | RC0404FR-07100KL (https://www.mouser.com/catalog/specsheets/YAGEO_PYu_RC_Group_51_RoHS_L_12.pdf) | 6
R613 | 100k | R_0805_2012Metric | Bourns | CR0805-J/-000ELF (https://www.mouser.de/datasheet/3/40/1/cr.pdf) | 1 | $0.101 | $0.10 | 129804 |  | $0.101 | 1 | $0.10 | 652-CR0805-J/-000ELF (https://www.mouser.de/ProductDetail/Bourns/CR0805-J-000ELF?qs=wKk%252BLl0qPROQEEzWY8Q13A%3D%3D)
S601 | RESET | WS-TASV-6x6 | Wurth Elektronik | 430182050816 (https://www.we-online.com/components/products/datasheet/430182050816.pdf) | 1
S501 | SW1 | WS-TASV-6x6 | Wurth Elektronik | 430182050816 (https://www.we-online.com/components/products/datasheet/430182050816.pdf) | 1
S502 | SW2 | WS-TASV-6x6 | Wurth Elektronik | 430182050816 (https://www.we-online.com/components/products/datasheet/430182050816.pdf) | 1
S503 | SW3 | WS-TASV-6x6 | Wurth Elektronik | 430182050816 (https://www.we-online.com/components/products/datasheet/430182050816.pdf) | 1
S504 | SW4 | WS-TASV-6x6 | Wurth Elektronik | 430182050816 (https://www.we-online.com/components/products/datasheet/430182050816.pdf) | 1
X401 X501 X503 X505 X506 X507 X508 X510 X602 X606 X607 X609 X610 | Battery | PinHeader_1x02_P2.54mm_Vertical | Amphenol FCI | 77311-818-02LF (https://cdn.amphenol-cs.com/media/wysiwyg/files/documentation/datasheet/boardwiretoboard/bwb_bergstik.pdf) | 13
X402 X509 | Battery | 78171-0002 | Molex | 78171-0002 (https://www.molex.com/en-us/products/part-detail-pdf/781710002?display=pdf) | 2
X601 | DEBUG | SHF-105-01-L-D-SM-TR | Wurth Elektronik | 62101021021 (http://infocenter.arm.com/help/topic/com.arm.doc.ddi0314h/DDI0314H_coresight_components_trm.pdf) | 1
X603 | Device | USB_C_Receptacle_Amphenol_12401610E4-2A | Amphenol Commercial Products | 12401610E4#2A (https://www.usb.org/sites/default/files/documents/usb_type-c.zip) | 1
X608 | Display | ER-CON0.4-24P | EastRising | OK-24F024-04 (https://www.buydisplay.com/download/manual/ER-TFT1.28-2_Datasheet.pdf) | 1
X605 | GPIO | PinHeader_1x06_P2.54mm_Vertical | Amphenol FCI | 77311-802-06LF | 1
X502 | I2S | PinHeader_1x05_P2.54mm_Vertical | Amphenol FCI | 77311-818-05LF (https://cdn.amphenol-cs.com/media/wysiwyg/files/documentation/datasheet/boardwiretoboard/bwb_bergstik.pdf) | 1
X403 X504 | Power | PinHeader_1x04_P2.54mm_Vertical | Amphenol FCI | 77311-818-02LF (https://cdn.amphenol-cs.com/media/wysiwyg/files/documentation/datasheet/boardwiretoboard/bwb_bergstik.pdf) | 2
X604 | UART | PinHeader_1x03_P2.54mm_Vertical | Amphenol FCI | 77311-818-03LF (https://cdn.amphenol-cs.com/media/wysiwyg/files/documentation/datasheet/boardwiretoboard/bwb_bergstik.pdf) | 1
 | USD($)/EUR(€): | 1.1697 |  |  |  | Total Purchase: | $0.00 | Buy here (https://mouser.com/bom/) |  |  |  | $0.00
 |  |  |  |  |  | Purchase description:
Created: | 2025-09-06 19:19:56
KiCost® v1.1.20 + KiBot v1.8.4

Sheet: Colors
Columns colors
KiCad Fields (default)
Generated Fields
User Fields
Empty Fields
Costs sheet colors
Best price
No manufacturer or distributor code
Not available
Purchase quantity is more than what is available
Minimum order quantity not respected
Total available part quantity is less than needed
Total purchased part quantity is less than needed
This part is obsolete
This part is listed but is not normally stocked

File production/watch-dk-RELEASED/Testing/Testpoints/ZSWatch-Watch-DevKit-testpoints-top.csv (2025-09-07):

Ref. | Net | X [mm] | Y [mm]
TP401 | VBUS-In | 237.30 | -125.80
TP402 | VBAT | 230.60 | -116.72
TP403 | +1V8 | 216.40 | -118.70
TP404 | +3V0 | 213.40 | -118.70
TP405 | VSYS | 237.30 | -123.60
TP501 | VIB-EN | 222.20 | -133.30
TP502 | VIB-PWM | 222.20 | -129.20
TP503 | MIC-CLK | 172.20 | -172.90
TP504 | MIC-DATA | 170.20 | -176.60
TP601 | RESETn | 254.70 | -142.20

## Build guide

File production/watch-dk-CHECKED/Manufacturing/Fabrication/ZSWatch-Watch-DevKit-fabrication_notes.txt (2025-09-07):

FABRICATION NOTES (UNLESS OTHERWISE SPECIFIED)

1)	FABRICATE PER IPC-6012A CLASS 2.

2)	OUTLINE DEFINED IN SEPARATE GERBER FILE WITH
	"Edge_Cuts.GBR" SUFFIX.

	DIMENSIONS OF CIRCUMSIZED RECTANGLE SHOWN ON THIS
	DRAWING FOR REFERENCE ONLY.

3)	SEE SEPARATE DRILL FILES WITH ".DRL" SUFFIX 
	FOR HOLE LOCATIONS.

	SELECTED HOLE LOCATIONS SHOWN ON THIS DRAWING 
	FOR REFERENCE ONLY.

4)	SURFACE FINISH: HAL SNPB

5)	SOLDERMASK ON BOTH SIDES OF THE BOARD SHALL 
	BE LPI, COLOR WHITE.

6)	SILK SCREEN LEGEND TO BE APPLIED PER LAYER 
	STACKUP USING BLACK NON-CONDUCTIVE EPOXY INK.

7)	ALL VIAS ARE TENTED ON BOTH SIDES UNLESS 
	SOLDERMASK OPENED IN GERBER.

8)	VENDOR SHOULD FOLLOW ROHS COMPLIANT PROCESS 
	AND Pb FREE FOR MANUFACTURING

9)	PCB MATERIAL REQUIREMENTS:

	A.	FLAMMABILITY RATING MUST MEET OR EXCEED 
		UL94V-0 REQUIREMENTS.
	B.	Tg 150 C OR EQUIVALENT.
	C.	EQUIVALENT MATERIAL SHALL BE RoHS COMPLIANT, 
		HALOGEN FREE AND APPROVED BY ZSWATCH.

10)	DESIGN GEOMETRY MINIMUM FEATURE SIZES:

	BOARD SIZE				100.000 × 70.000 mm
	BOARD THICKNESS		1.561 mm
	TRACE WIDTH			0.127 mm
	TRACE TO TRACE		0.125 mm
	MIN. HOLE (PTH)			0.250 mm
	MIN. HOLE (NPTH)		0.650 mm
	ANNULAR RING			0.100 mm
	COPPER TO HOLE		0.125 mm
	COPPER TO EDGE		0.125 mm
	HOLE TO HOLE			0.250 mm

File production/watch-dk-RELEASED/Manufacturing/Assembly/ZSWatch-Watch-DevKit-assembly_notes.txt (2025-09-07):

ASSEMBLY NOTES (UNLESS OTHERWISE SPECIFIED)

1)	DO NOT POPULATE PARTS ARE MARKED WITH A RED CROSS.

2)	DO NOT POPULATE PARTS ARE NOT PRESENT IN THE BOM.

3)	IF CONFLICTING INFORMATION IS FOUND BETWEEN THE ASSEMBLY
	FILE AND BOM, BOM SHOULD BE USED AS THE MAIN SOURCE.

4)	CONFORMAL COATING IS NOT REQUIRED.

5)	DOT IDENTIFIES PIN #1 LOCATION AND DEVICE ORIENTATION
	WHEN VIEWED FROM THE TOP.

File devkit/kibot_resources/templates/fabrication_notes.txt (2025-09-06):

FABRICATION NOTES (UNLESS OTHERWISE SPECIFIED)

1)	FABRICATE PER IPC-6012A CLASS 2.

2)	OUTLINE DEFINED IN SEPARATE GERBER FILE WITH
	"Edge_Cuts.GBR" SUFFIX.

	DIMENSIONS OF CIRCUMSIZED RECTANGLE SHOWN ON THIS
	DRAWING FOR REFERENCE ONLY.

3)	SEE SEPARATE DRILL FILES WITH ".DRL" SUFFIX 
	FOR HOLE LOCATIONS.

	SELECTED HOLE LOCATIONS SHOWN ON THIS DRAWING 
	FOR REFERENCE ONLY.

4)	SURFACE FINISH: ${pcb_finish_cap}

5)	SOLDERMASK ON BOTH SIDES OF THE BOARD SHALL 
	BE LPI, COLOR ${solder_mask_color_text_cap}.

6)	SILK SCREEN LEGEND TO BE APPLIED PER LAYER 
	STACKUP USING ${silk_screen_color_text_cap} NON-CONDUCTIVE EPOXY INK.

7)	ALL VIAS ARE TENTED ON BOTH SIDES UNLESS 
	SOLDERMASK OPENED IN GERBER.

8)	VENDOR SHOULD FOLLOW ROHS COMPLIANT PROCESS 
	AND Pb FREE FOR MANUFACTURING

9)	PCB MATERIAL REQUIREMENTS:

	A.	FLAMMABILITY RATING MUST MEET OR EXCEED 
		UL94V-0 REQUIREMENTS.
	B.	Tg 150 C OR EQUIVALENT.
	C.	EQUIVALENT MATERIAL SHALL BE RoHS COMPLIANT, 
		HALOGEN FREE AND APPROVED BY ${COMPANY_cap}.

10)	DESIGN GEOMETRY MINIMUM FEATURE SIZES:

	BOARD SIZE				${bb_w_mm} × ${bb_h_mm} mm
	BOARD THICKNESS		${thickness_mm} mm
	TRACE WIDTH			${track_mm} mm
	TRACE TO TRACE		${clearance_mm} mm
	MIN. HOLE (PTH)			${drill_pth_real_mm} mm
	MIN. HOLE (NPTH)		${drill_npth_real_mm} mm
	ANNULAR RING			${oar_mm} mm
	COPPER TO HOLE		${c2h_mm} mm
	COPPER TO EDGE		${c2e_mm} mm
	HOLE TO HOLE			${h2h_mm} mm
#?stackup and impedance_controlled

#?stackup and impedance_controlled
11)	REFER TO IMPEDANCE TABLE FOR IMPEDANCE CONTROL REQUIREMENTS.
#?stackup and impedance_controlled

#?stackup and impedance_controlled
12)	CONFIRM SPACE WIDTHS AND SPACINGS.

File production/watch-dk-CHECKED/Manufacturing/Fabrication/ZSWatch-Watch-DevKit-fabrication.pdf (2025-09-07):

# Top Fabrication (Scale 1:1)

# Watch-DevKit-HW Fabrication Document

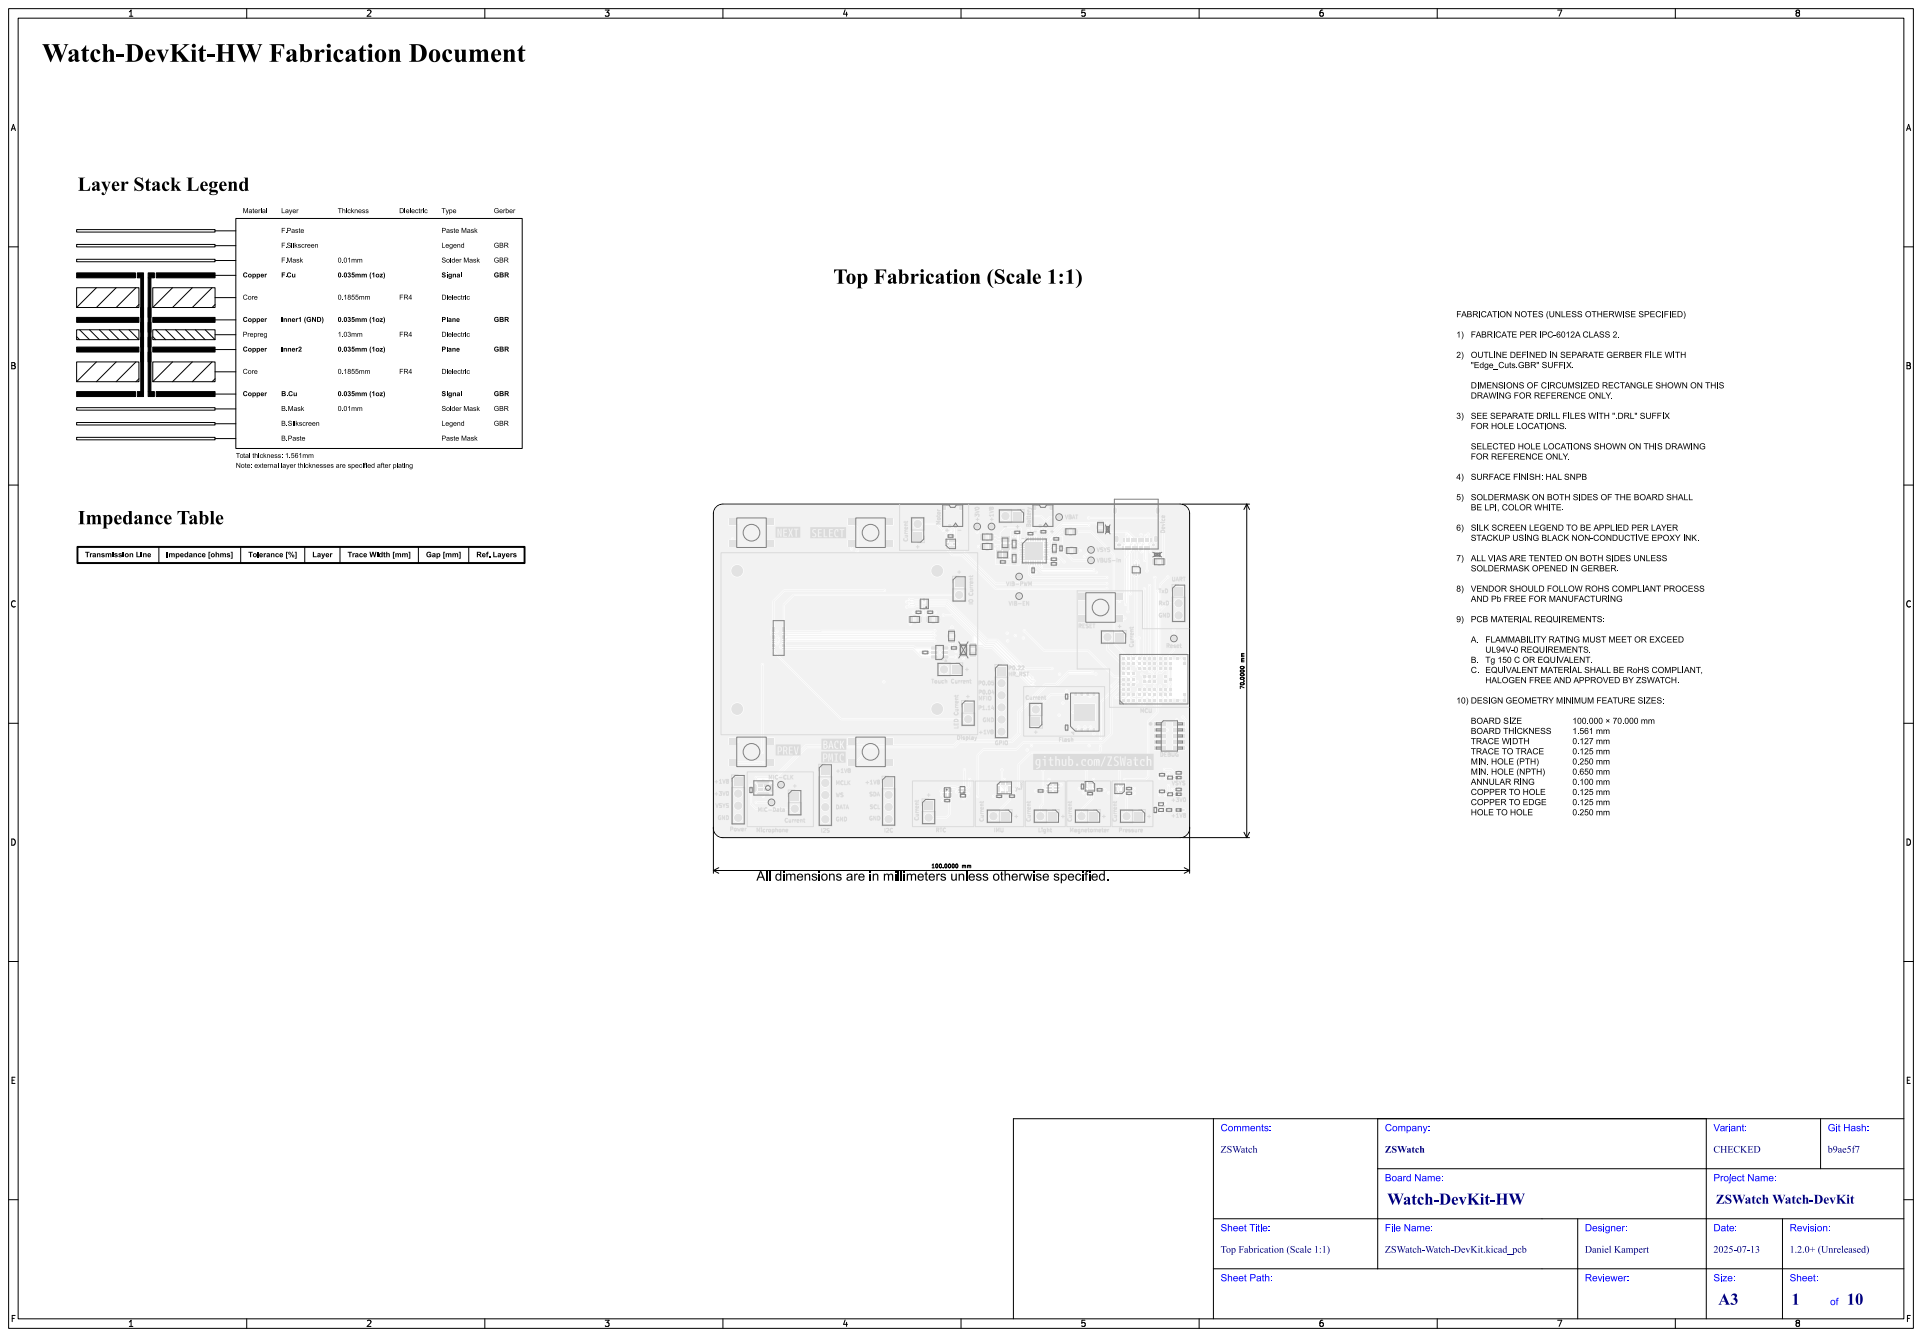
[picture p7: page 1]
Git Hash:; ZSWatch; Comments:; Sheet Path:; Sheet Title:; File Name:; Watch-DevKit-HW; ZSWatch Watch-DevKit; Company:; CHECKED; Variant:; Board Name:; ZSWatch-Watch-DevKit.kicad_pcb; Daniel Kampert; Designer:; Reviewer:; Project Name:; Date:; 1.2.0+ (Unreleased); Revision:; Size:; Sheet:; Current; RESET; VSYS; VBUS-In; VBAT; GPIO; MIC-Data; Touch Current; MIC-CLK; Reset; Device; VIB-EN; Battery; UART; IO Current; Power; LED Current; Motor; DEBUG; VIB-PWM; HR_RST; DATA; Pressure; GND; Flash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

Top Fabrication (Scale 1:1)

# Bottom Fabrication (Scale 1:1)

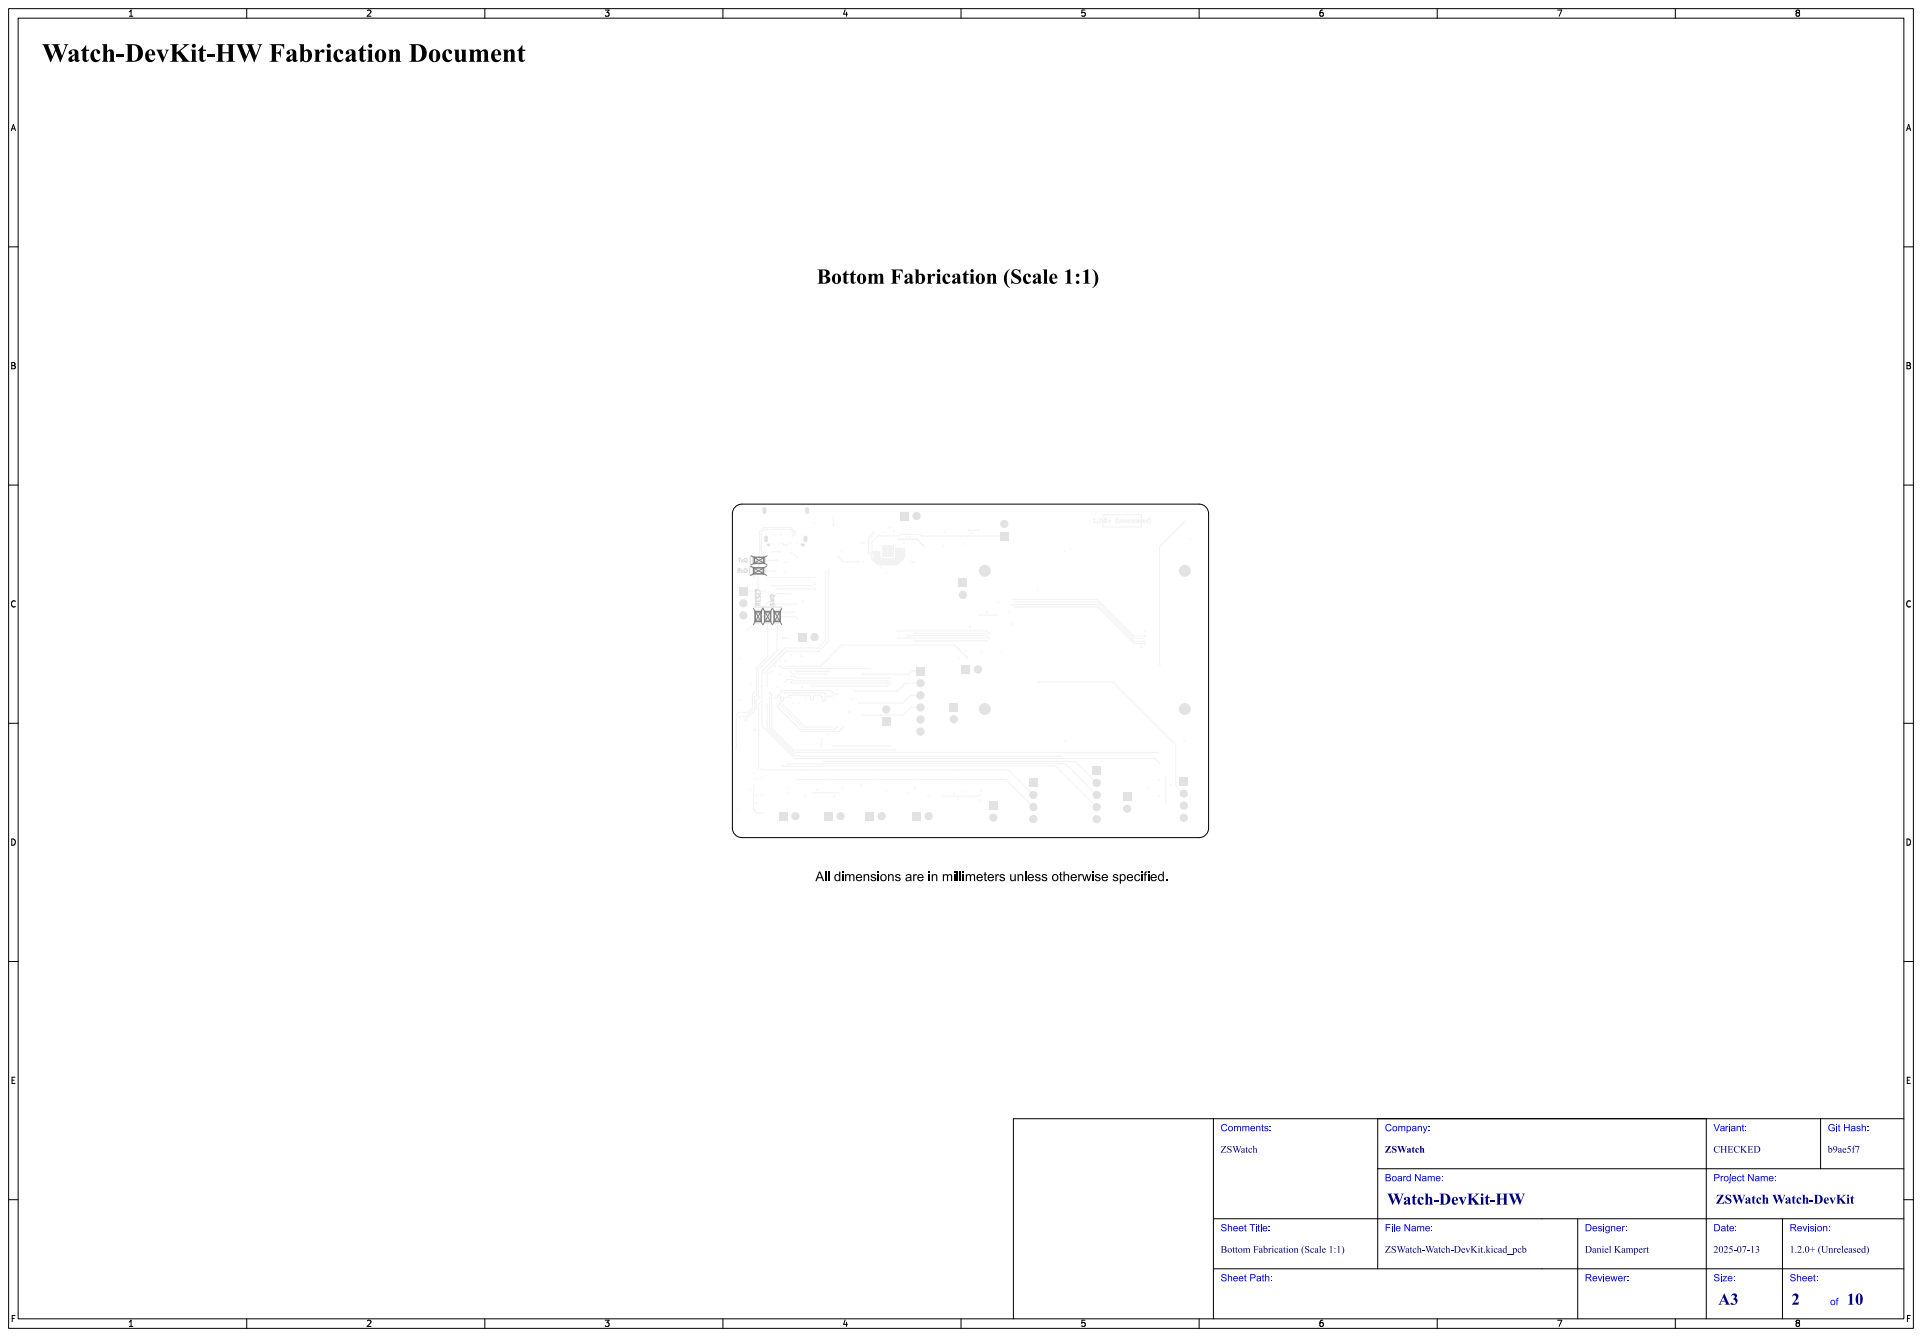
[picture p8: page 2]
Git; Hash:; ZSWatch; Comments:; Sheet Title:; File Name:; Watch-DevKit-HW; ZSWatch Watch-DevKit; Company:; CHECKED; Variant:; Board Name:; ZSWatch-Watch-DevKit.kicad_pcb; Daniel Kampert; Designer:; Project Name:; Date:; 1.2.0+ (Unreleased); Revision:; RxD; TxD; ~{RESET}; SWD

Bottom Fabrication (Scale 1:1)

# Drill Drawing L1 - L4 (Scale 1:1)

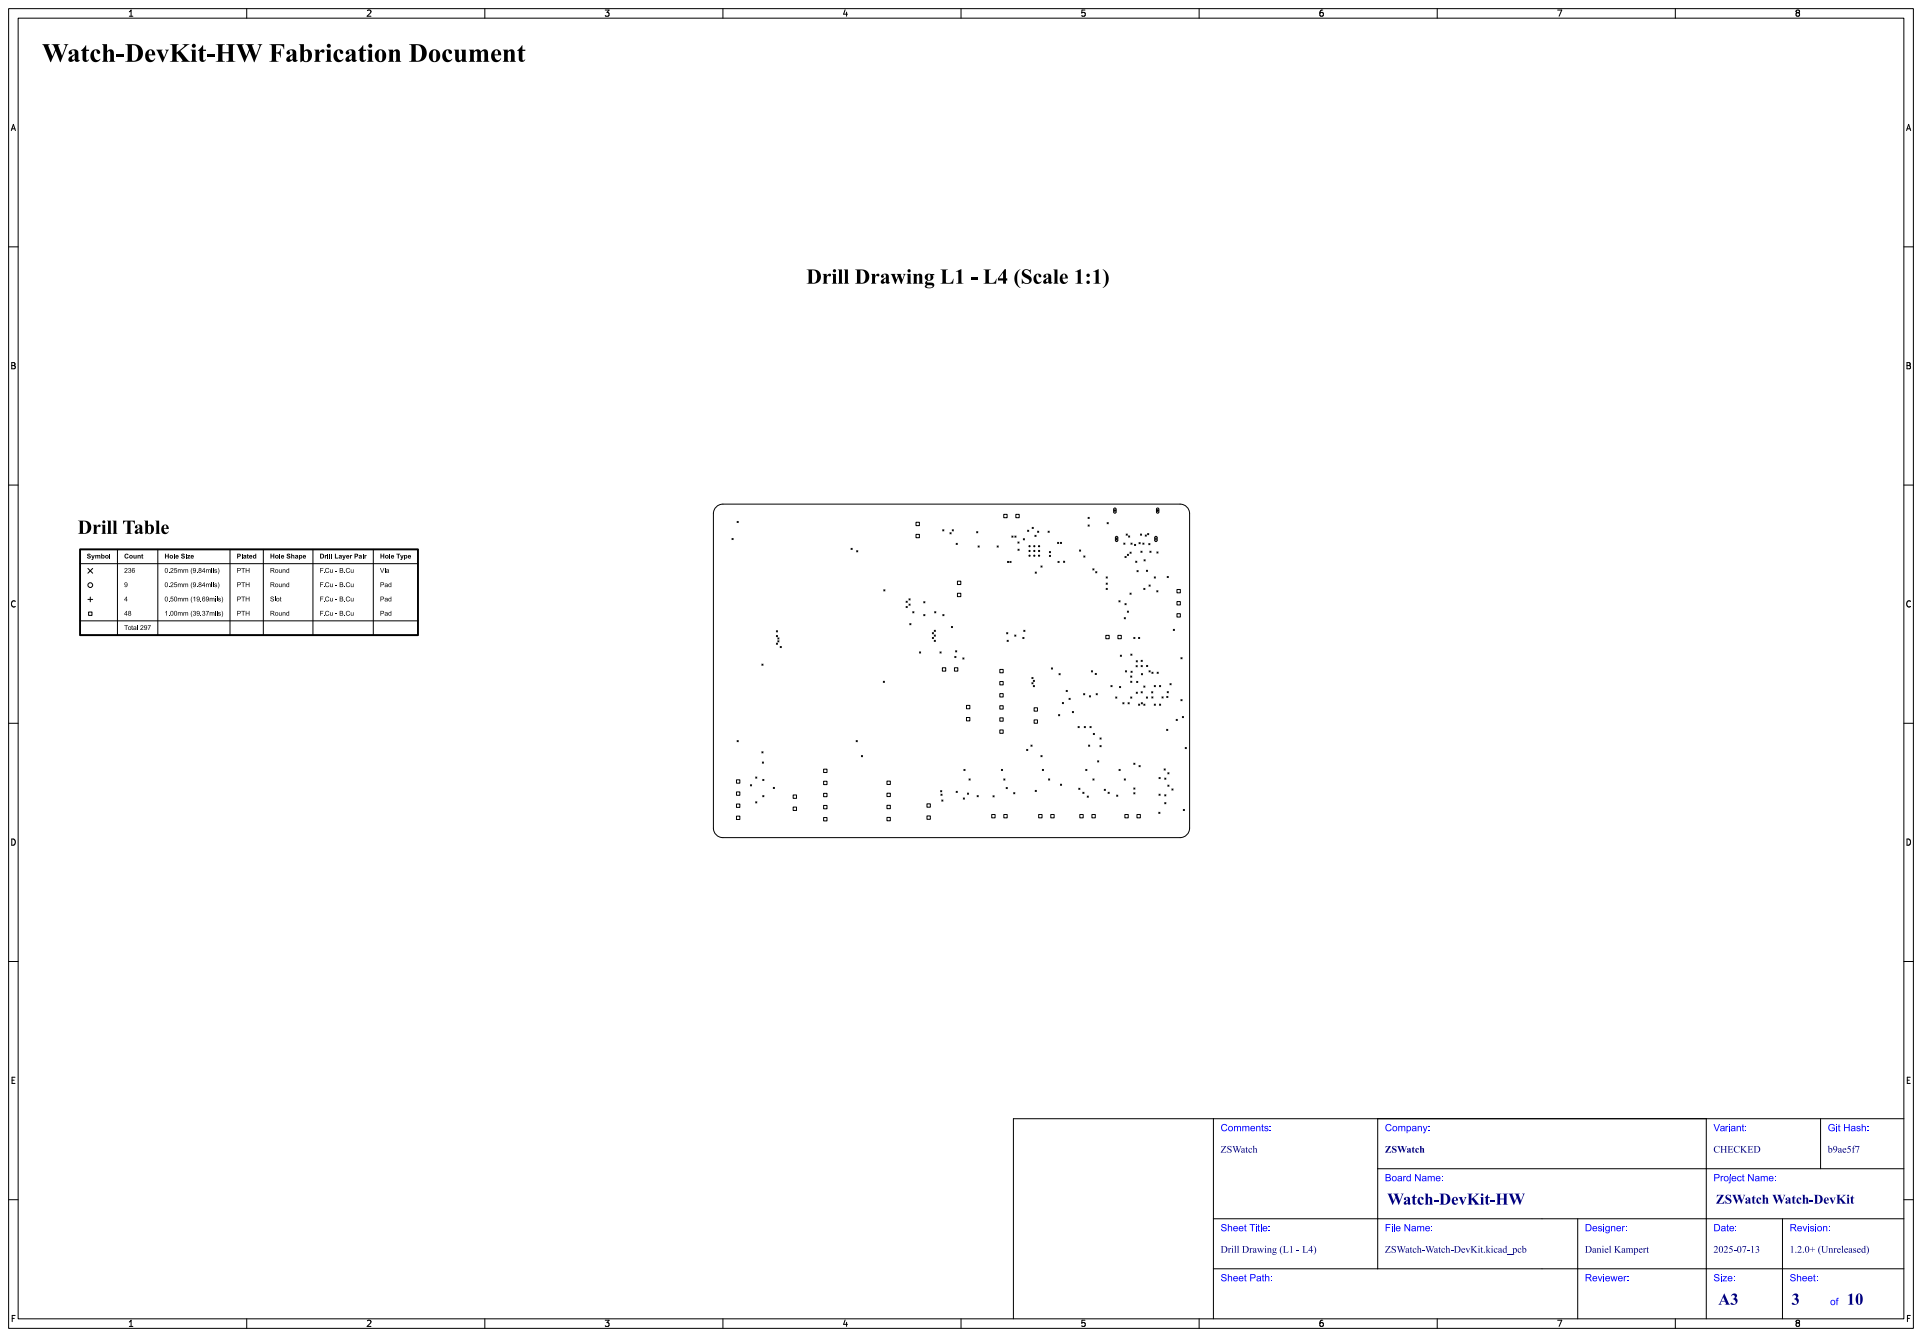
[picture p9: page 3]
Git; Hash:; ZSWatch; Comments:; Drill Drawing (L1 - L4); Sheet Title:; File Name:; Watch-DevKit-HW; ZSWatch Watch-DevKit; Company:; CHECKED; Variant:; Board Name:; ZSWatch-Watch-DevKit.kicad_pcb; Daniel Kampert; Designer:; Project Name:; Date:; 1.2.0+ (Unreleased); Revision:

# Drill Drawing L1 - L4 (Scale 1:1)

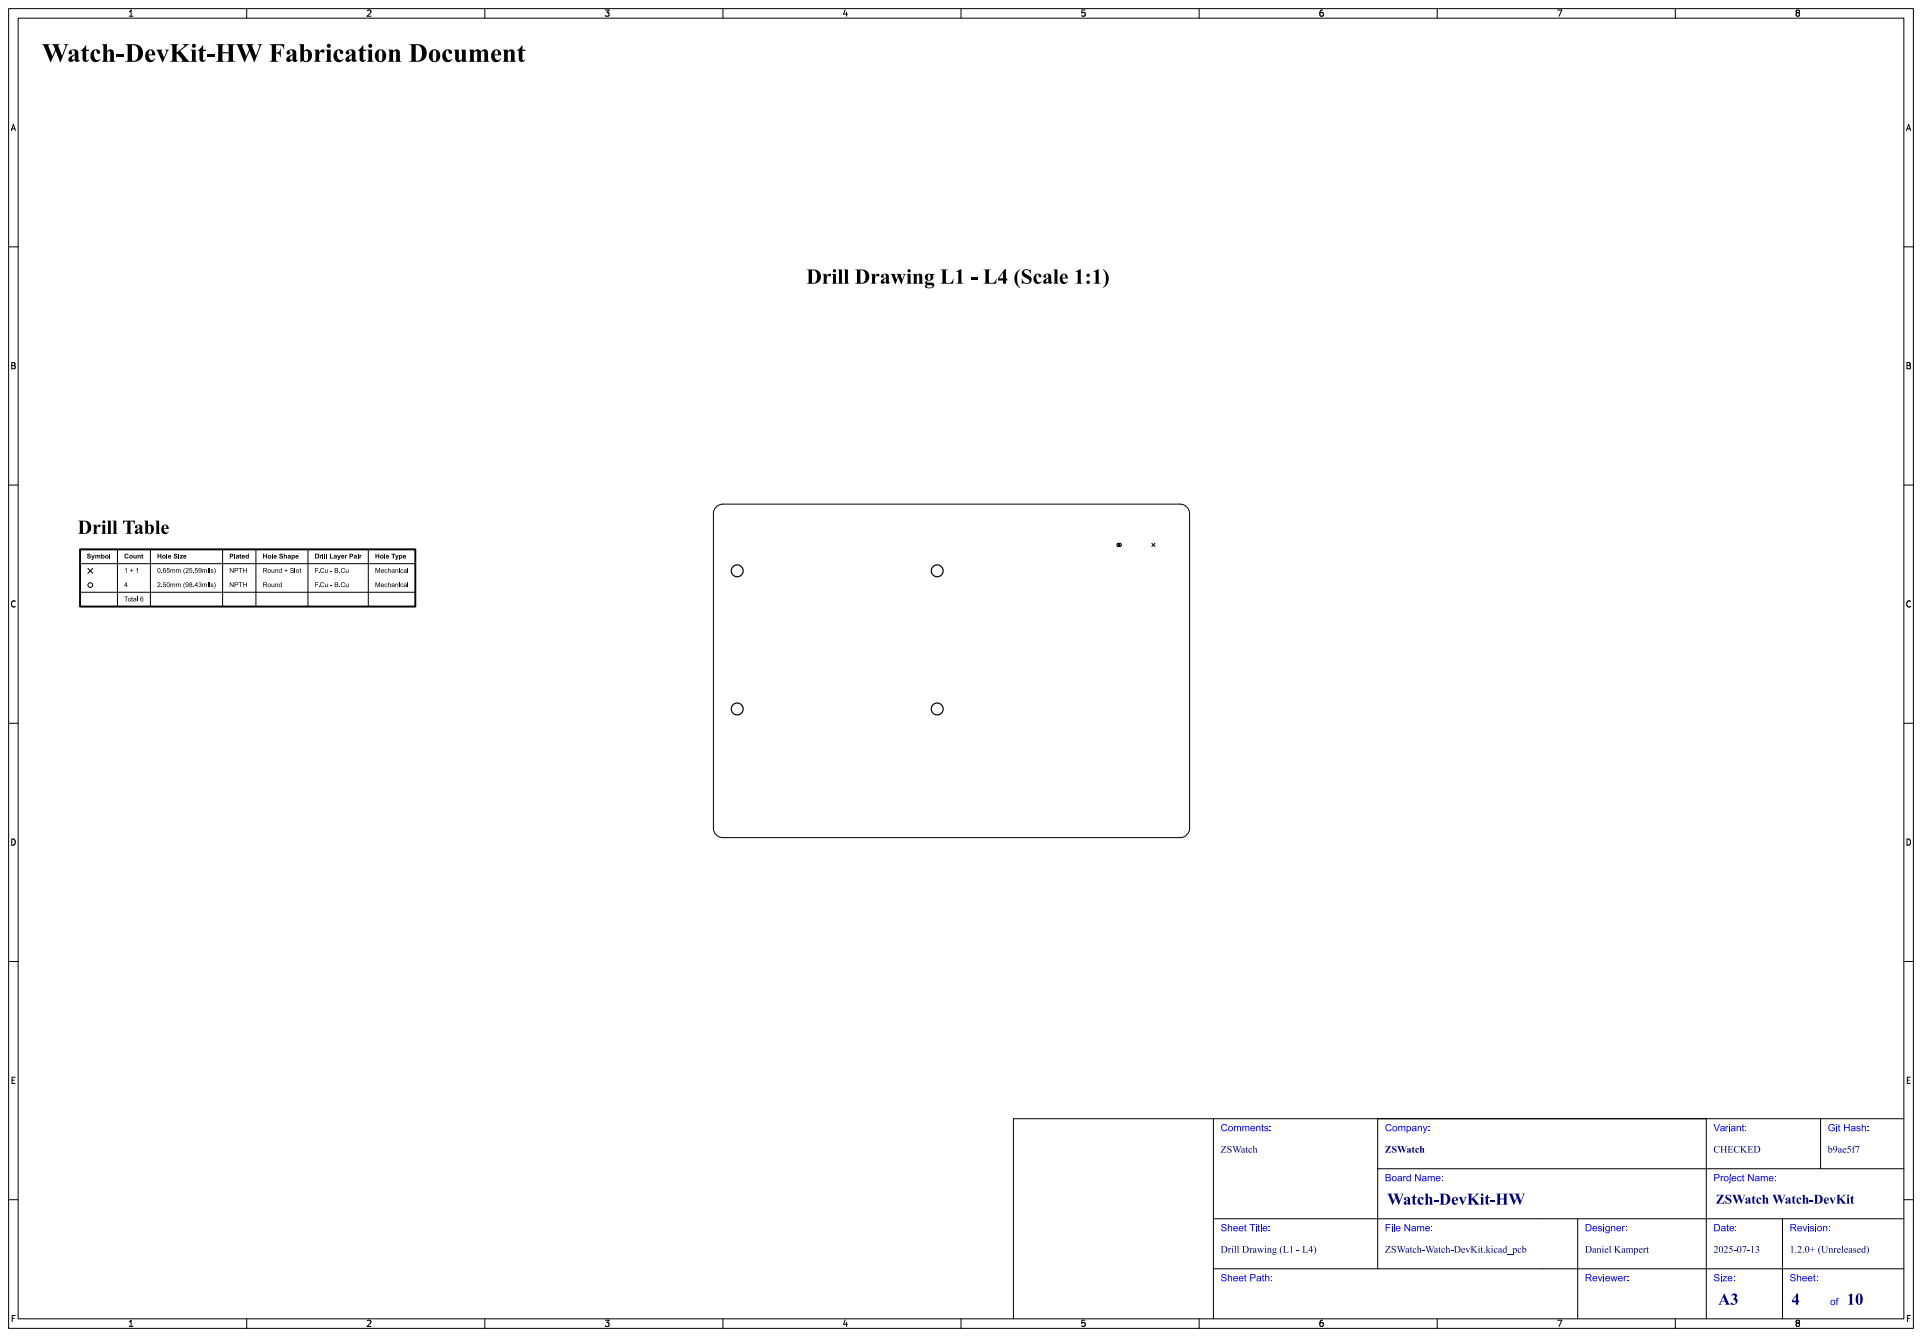
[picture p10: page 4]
Git; Hash:; ZSWatch; Comments:; Drill Drawing (L1 - L4); Sheet Title:; File Name:; Watch-DevKit-HW; ZSWatch Watch-DevKit; Company:; CHECKED; Variant:; Board Name:; ZSWatch-Watch-DevKit.kicad_pcb; Daniel Kampert; Designer:; Project Name:; Date:; 1.2.0+ (Unreleased); Revision:

# Top Test Points (Scale 1:1)

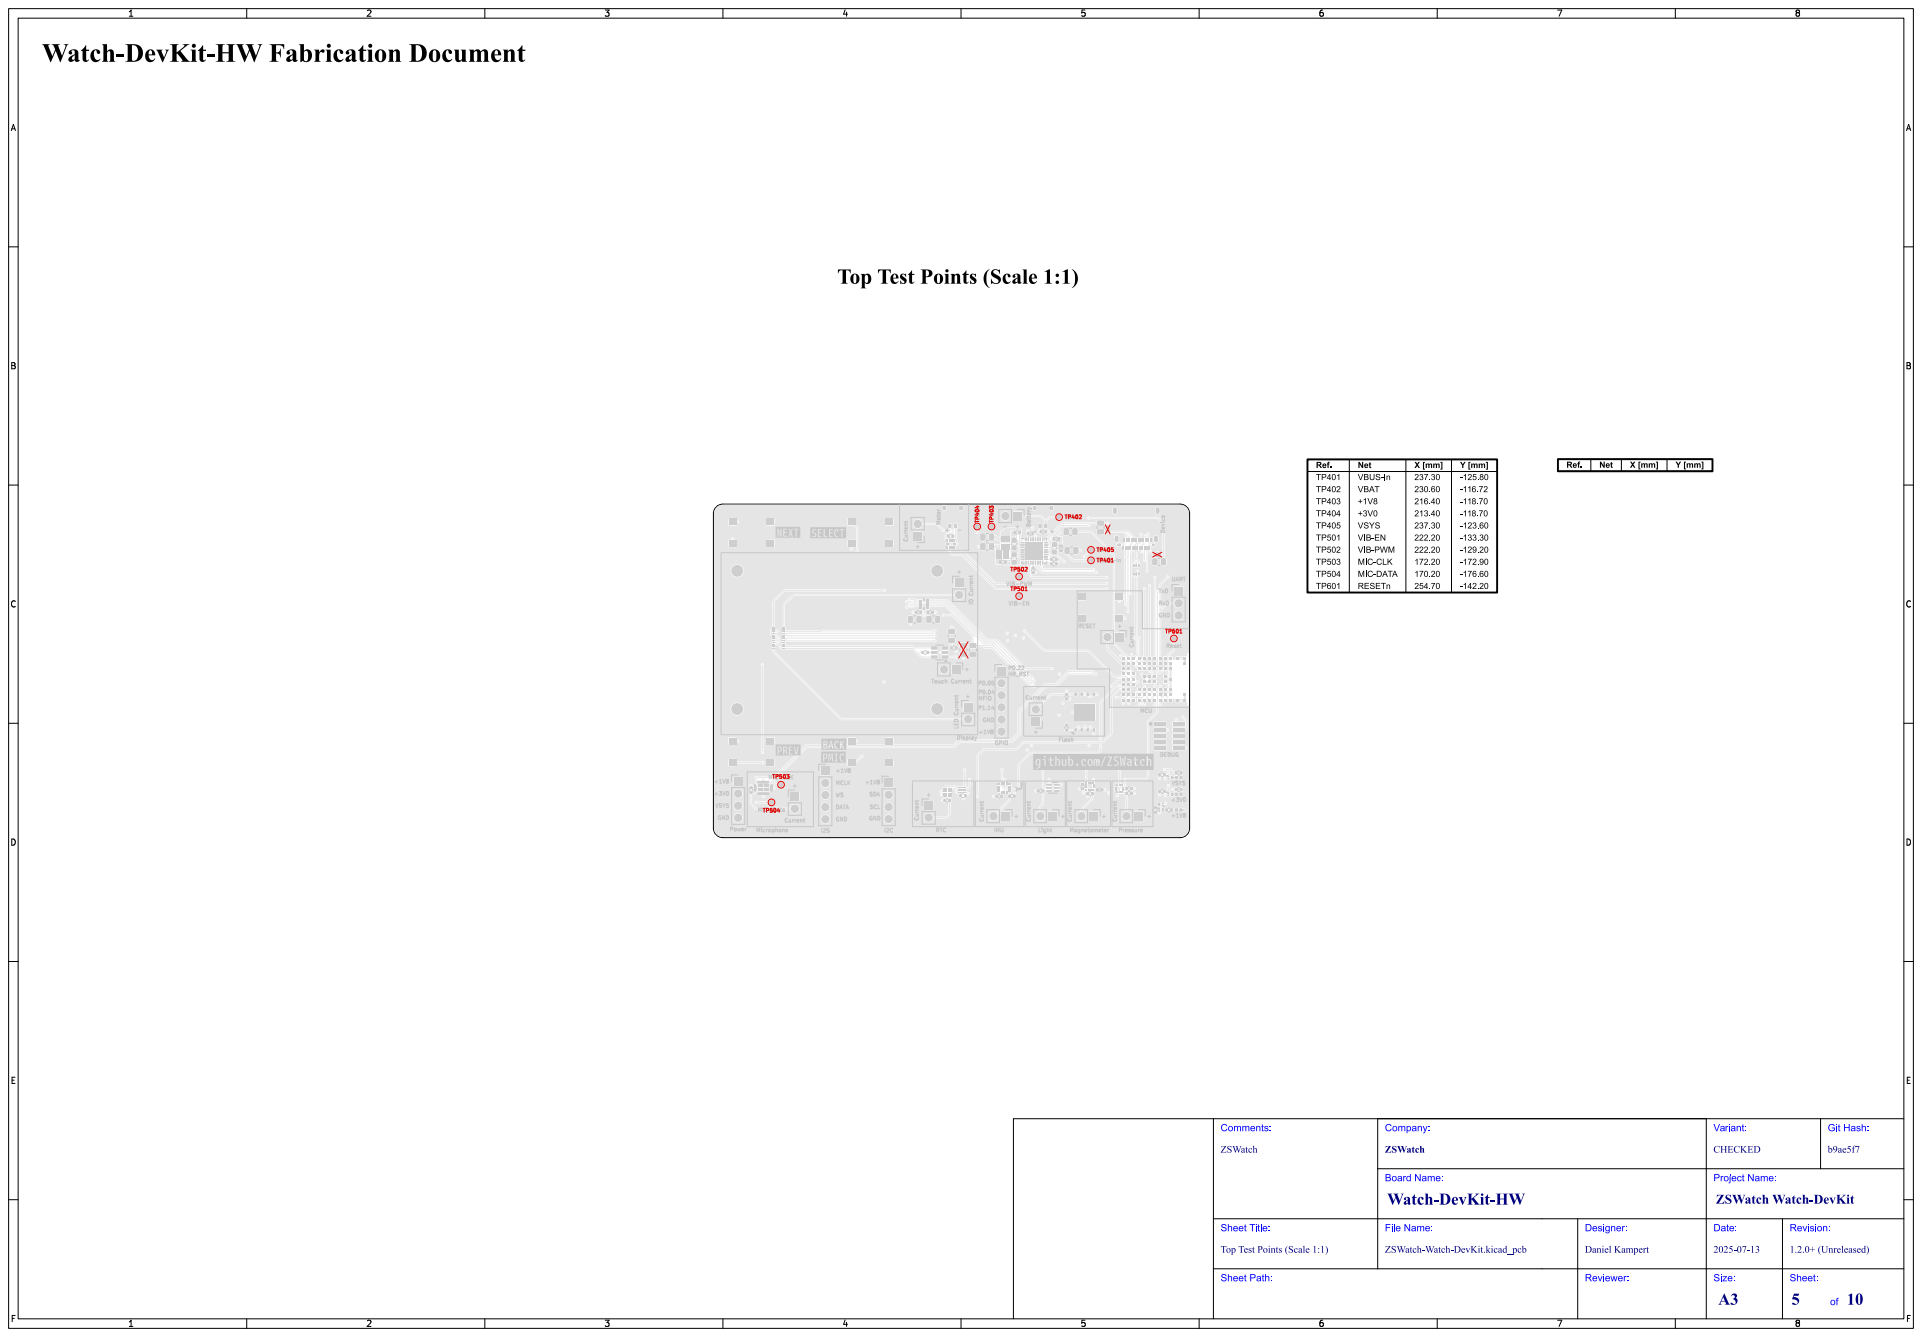
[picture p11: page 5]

Top Test Points (Scale 1:1)

# Bottom Test Points (Scale 1:1)

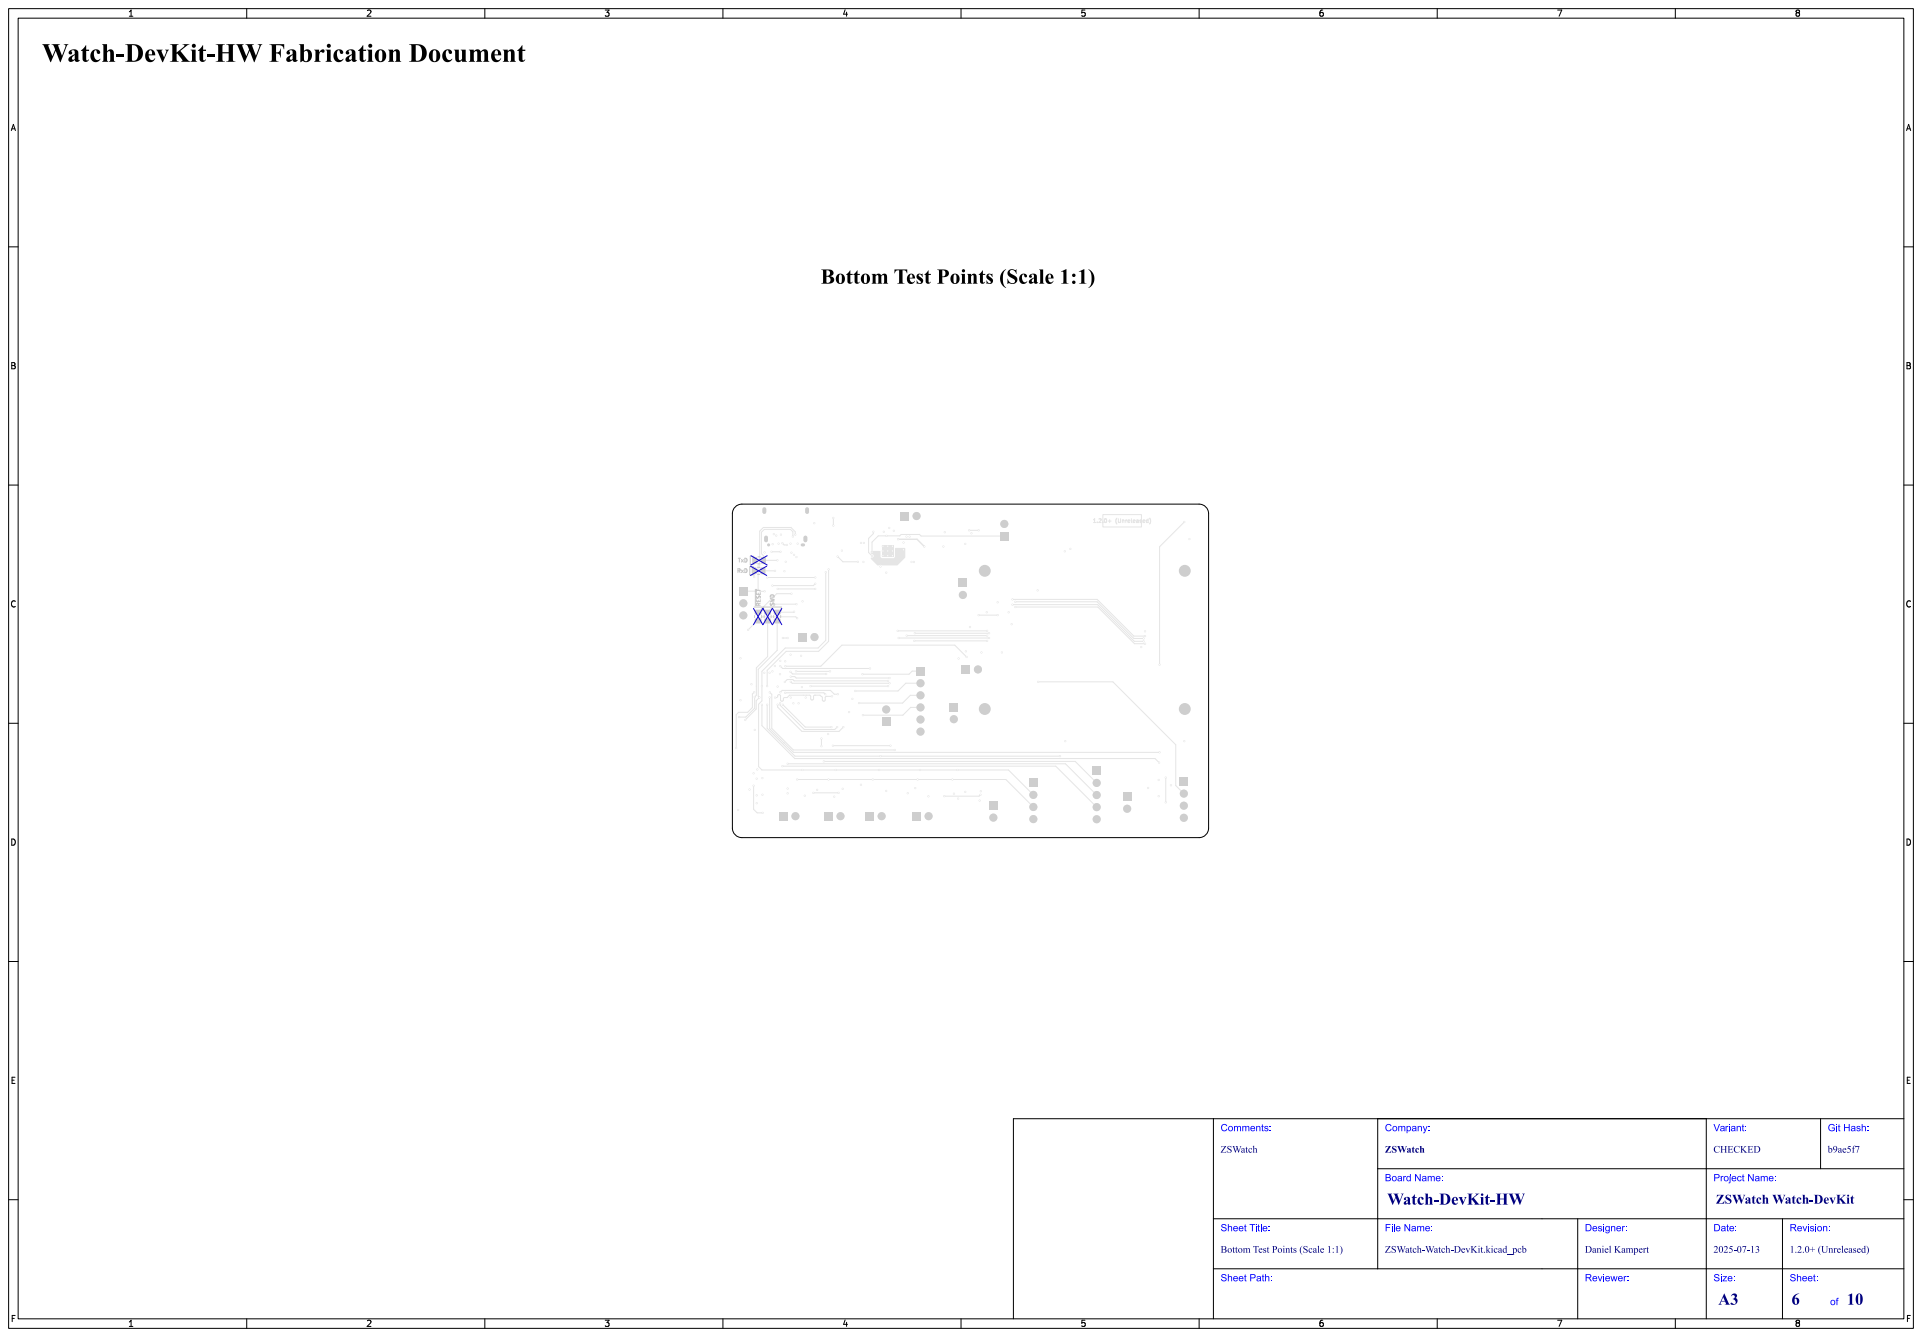
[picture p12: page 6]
Git; Hash:; ZSWatch; Comments:; Sheet Title:; File Name:; Watch-DevKit-HW; ZSWatch Watch-DevKit; Company:; CHECKED; Variant:; Board Name:; ZSWatch-Watch-DevKit.kicad_pcb; Daniel Kampert; Designer:; Project Name:; Date:; 1.2.0+ (Unreleased); Revision:; RxD; TxD; ~{RESET}; SWD

Bottom Test Points (Scale 1:1)

# F.Cu (Scale 1:1)

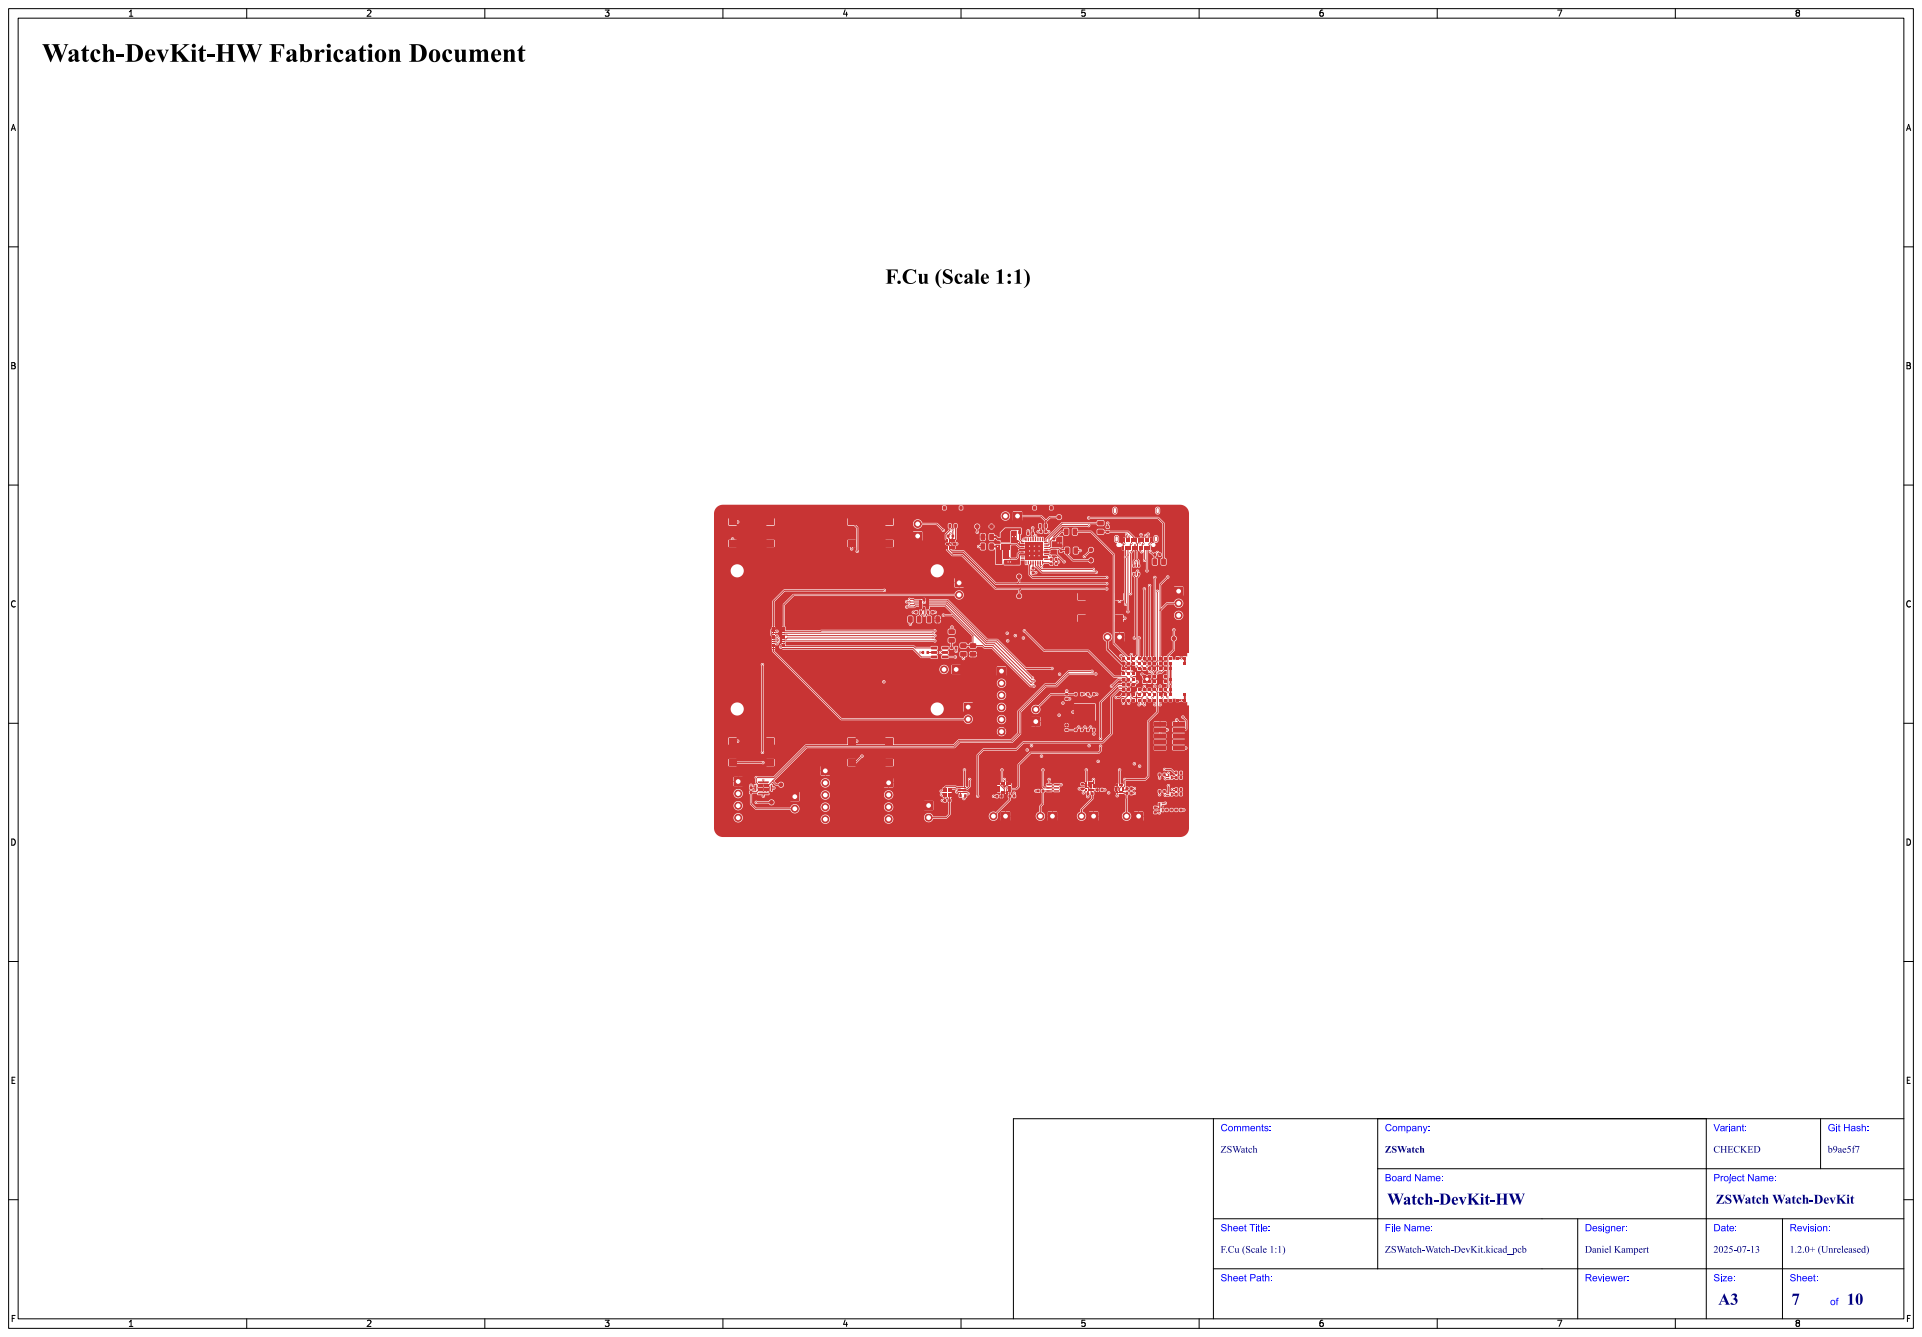
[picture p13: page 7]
Git; Hash:; ZSWatch; Comments:; F.Cu (Scale 1:1); Sheet Title:; File Name:; Watch-DevKit-HW; ZSWatch Watch-DevKit; Company:; CHECKED; Variant:; Board Name:; ZSWatch-Watch-DevKit.kicad_pcb; Daniel Kampert; Designer:; Project Name:; Date:; 1.2.0+ (Unreleased); Revision:

# Inner1 (GND) (Scale 1:1)

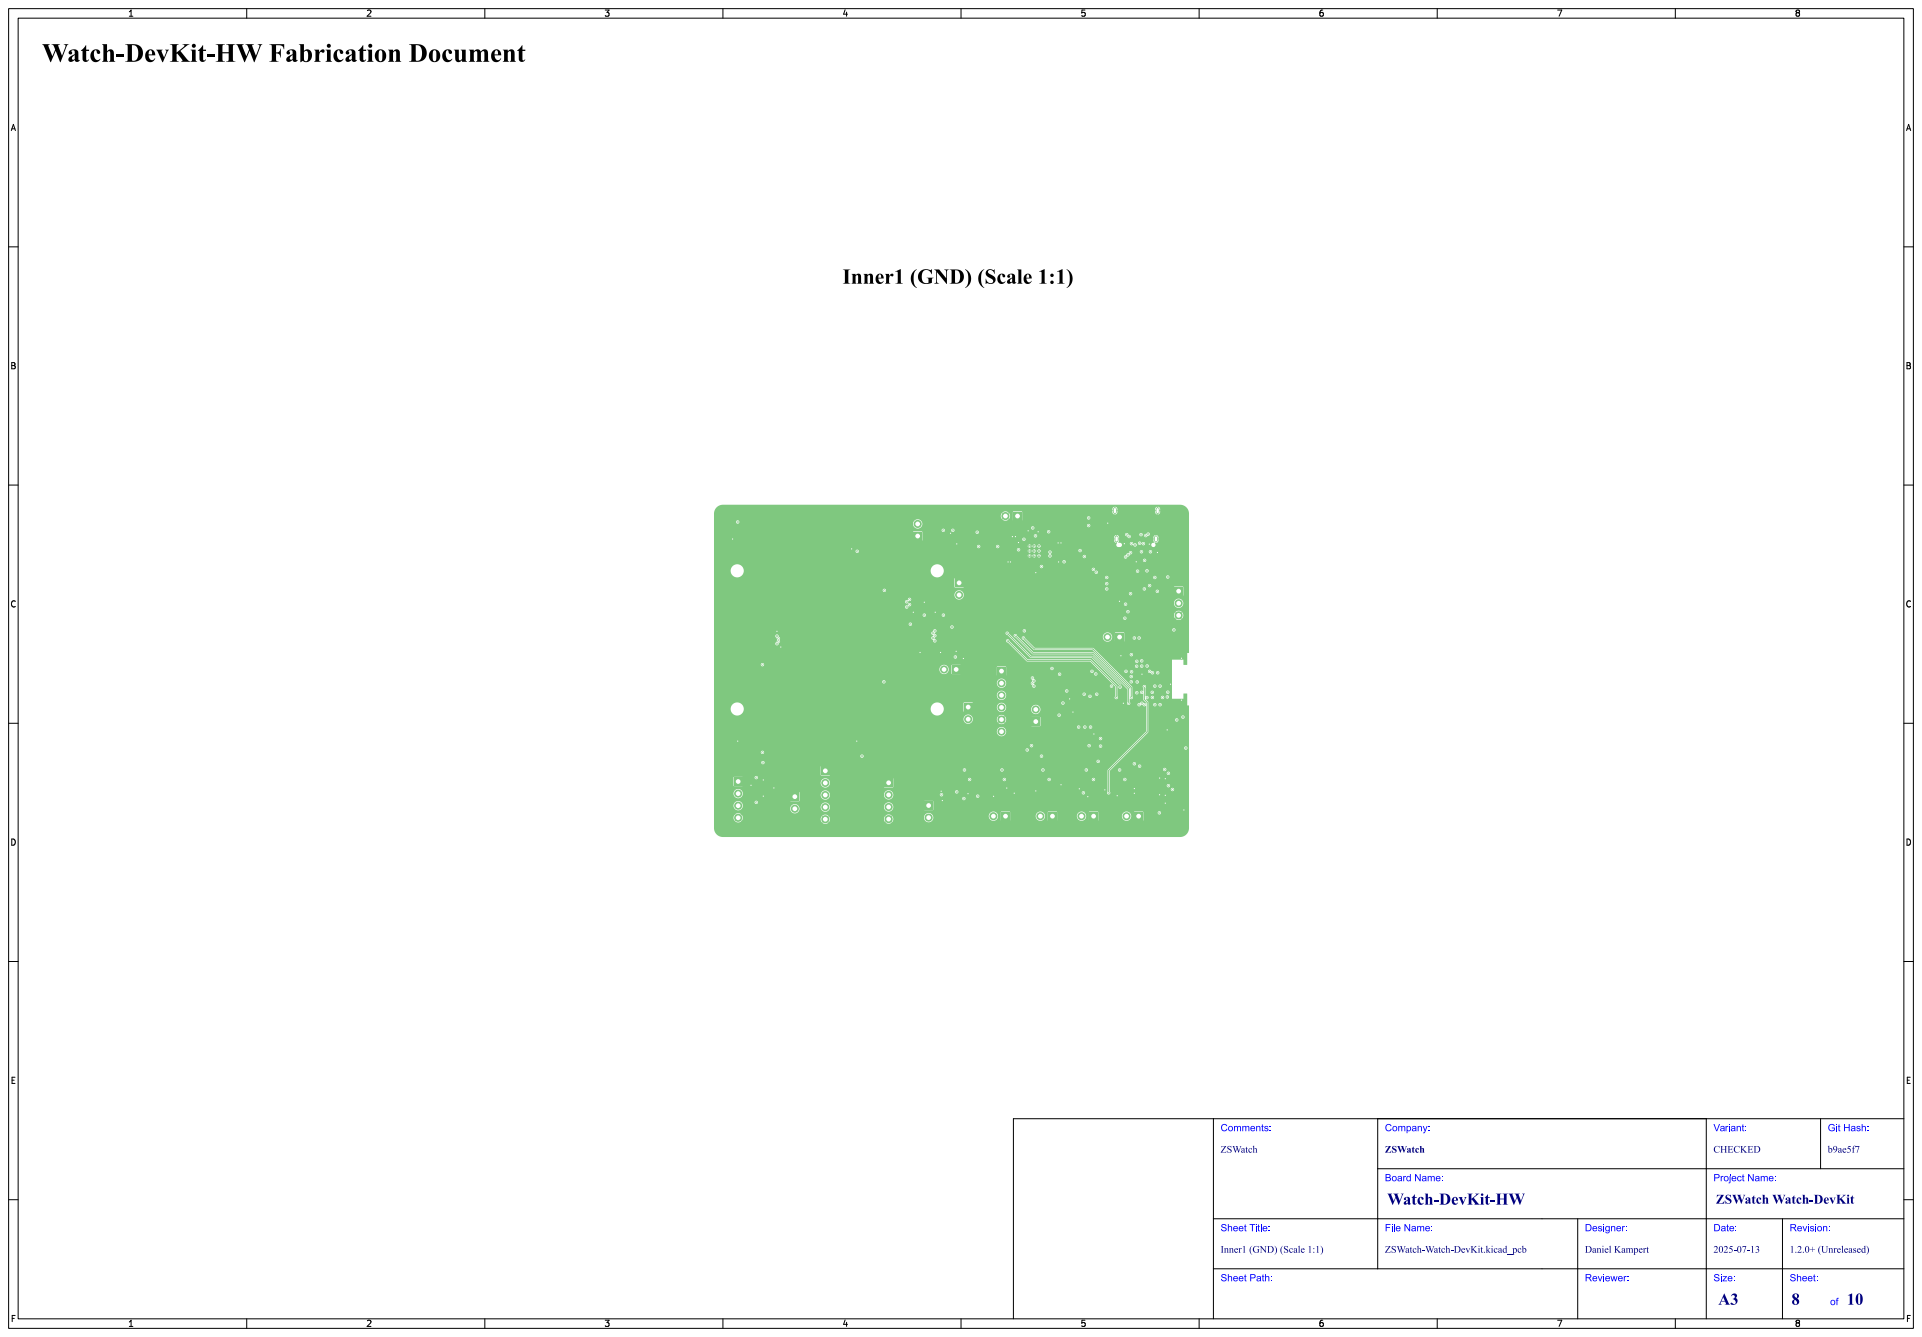
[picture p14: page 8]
Git; Hash:; ZSWatch; Comments:; Inner1 (GND) (Scale 1:1); Sheet Title:; File Name:; Watch-DevKit-HW; ZSWatch Watch-DevKit; Company:; CHECKED; Variant:; Board Name:; ZSWatch-Watch-DevKit.kicad_pcb; Daniel Kampert; Designer:; Project Name:; Date:; 1.2.0+ (Unreleased); Revision:

# Inner2 (Scale 1:1)

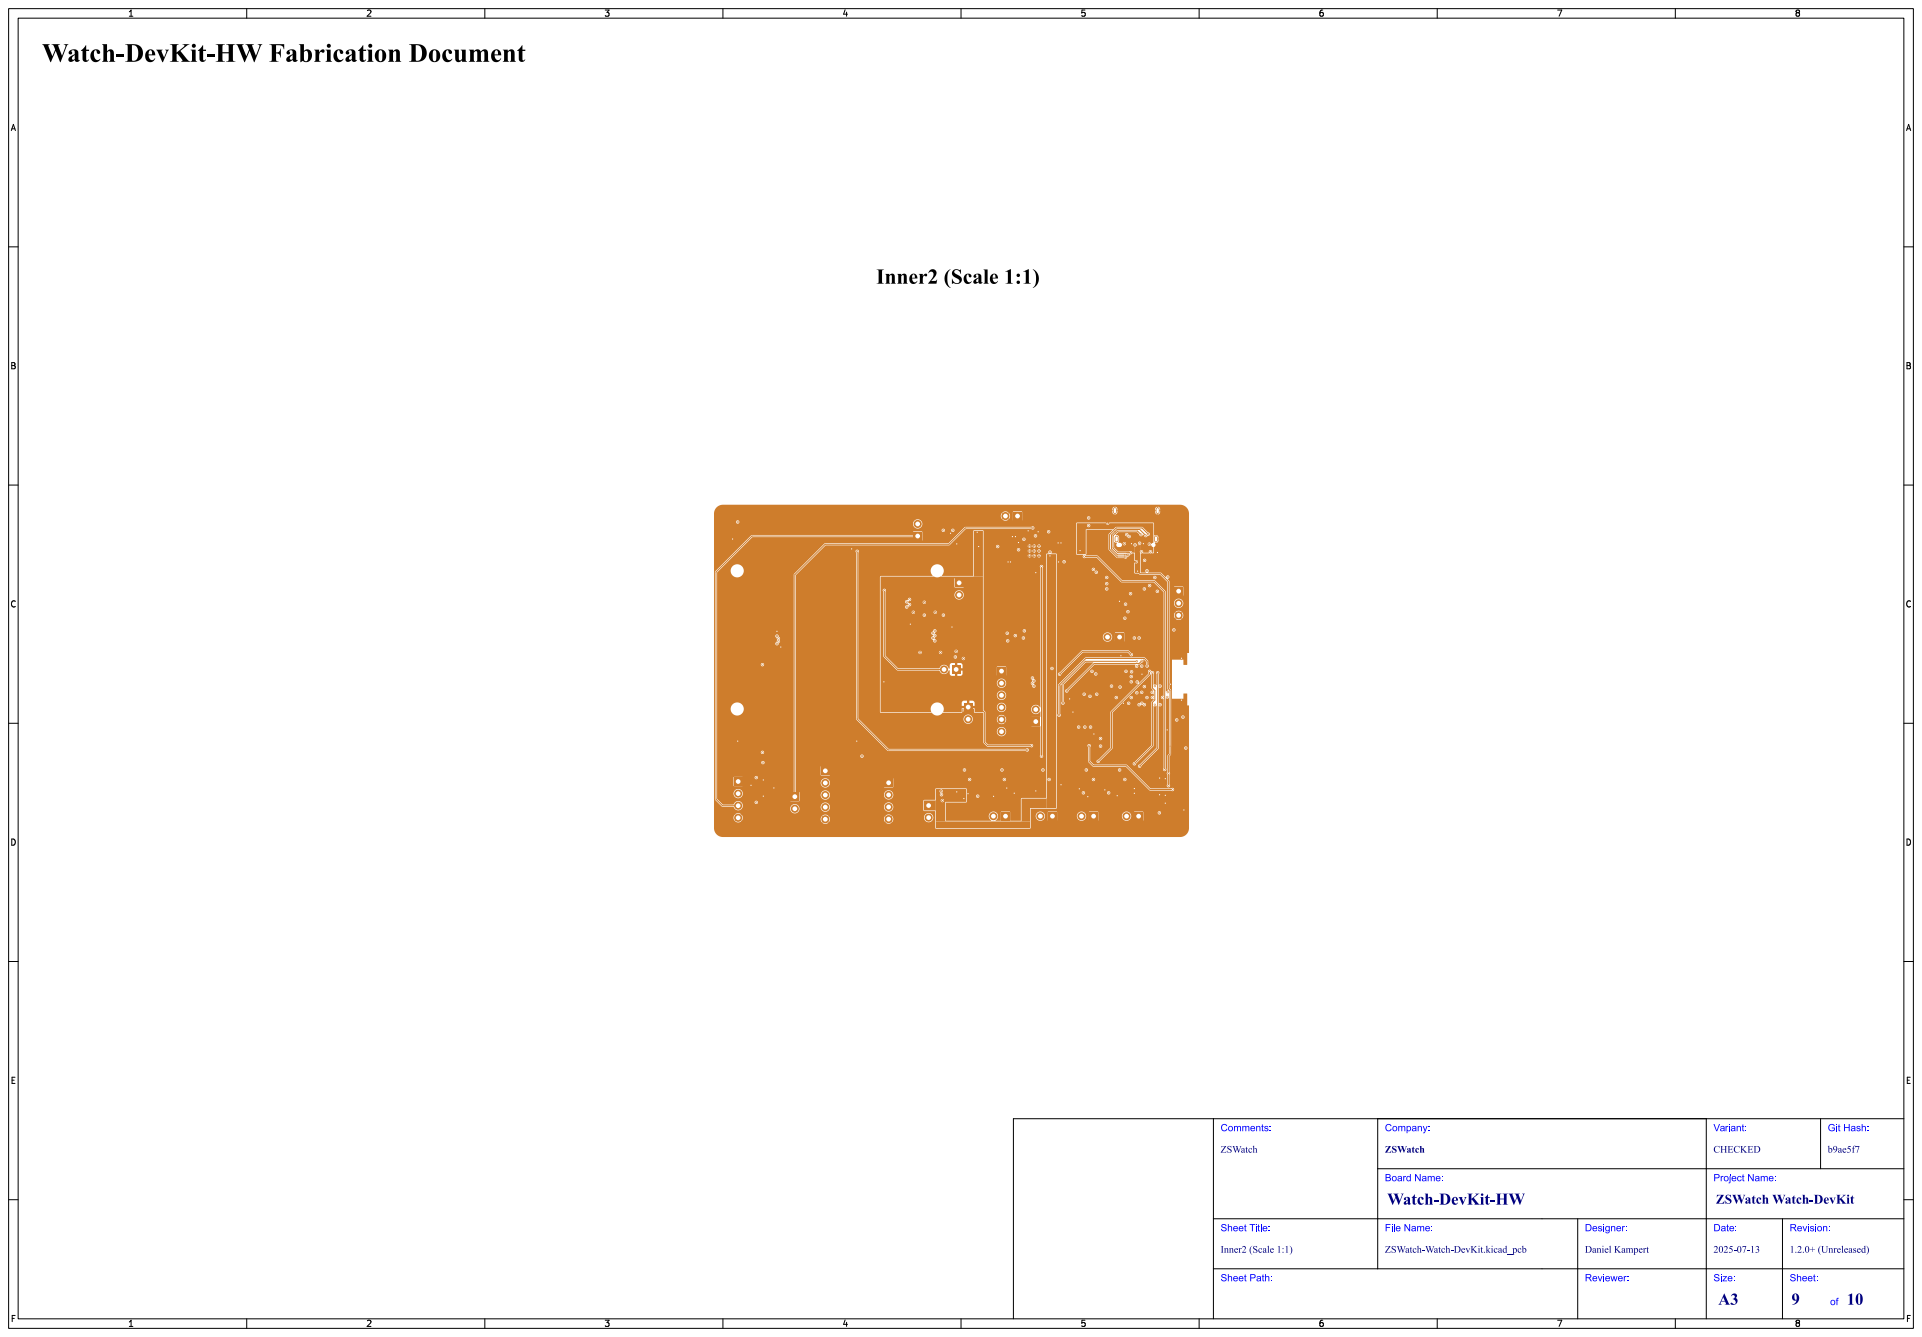
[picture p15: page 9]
Git; Hash:; ZSWatch; Comments:; Inner2 (Scale 1:1); Sheet Title:; File Name:; Watch-DevKit-HW; ZSWatch Watch-DevKit; Company:; CHECKED; Variant:; Board Name:; ZSWatch-Watch-DevKit.kicad_pcb; Daniel Kampert; Designer:; Project Name:; Date:; 1.2.0+ (Unreleased); Revision:

# B.Cu (Scale 1:1)

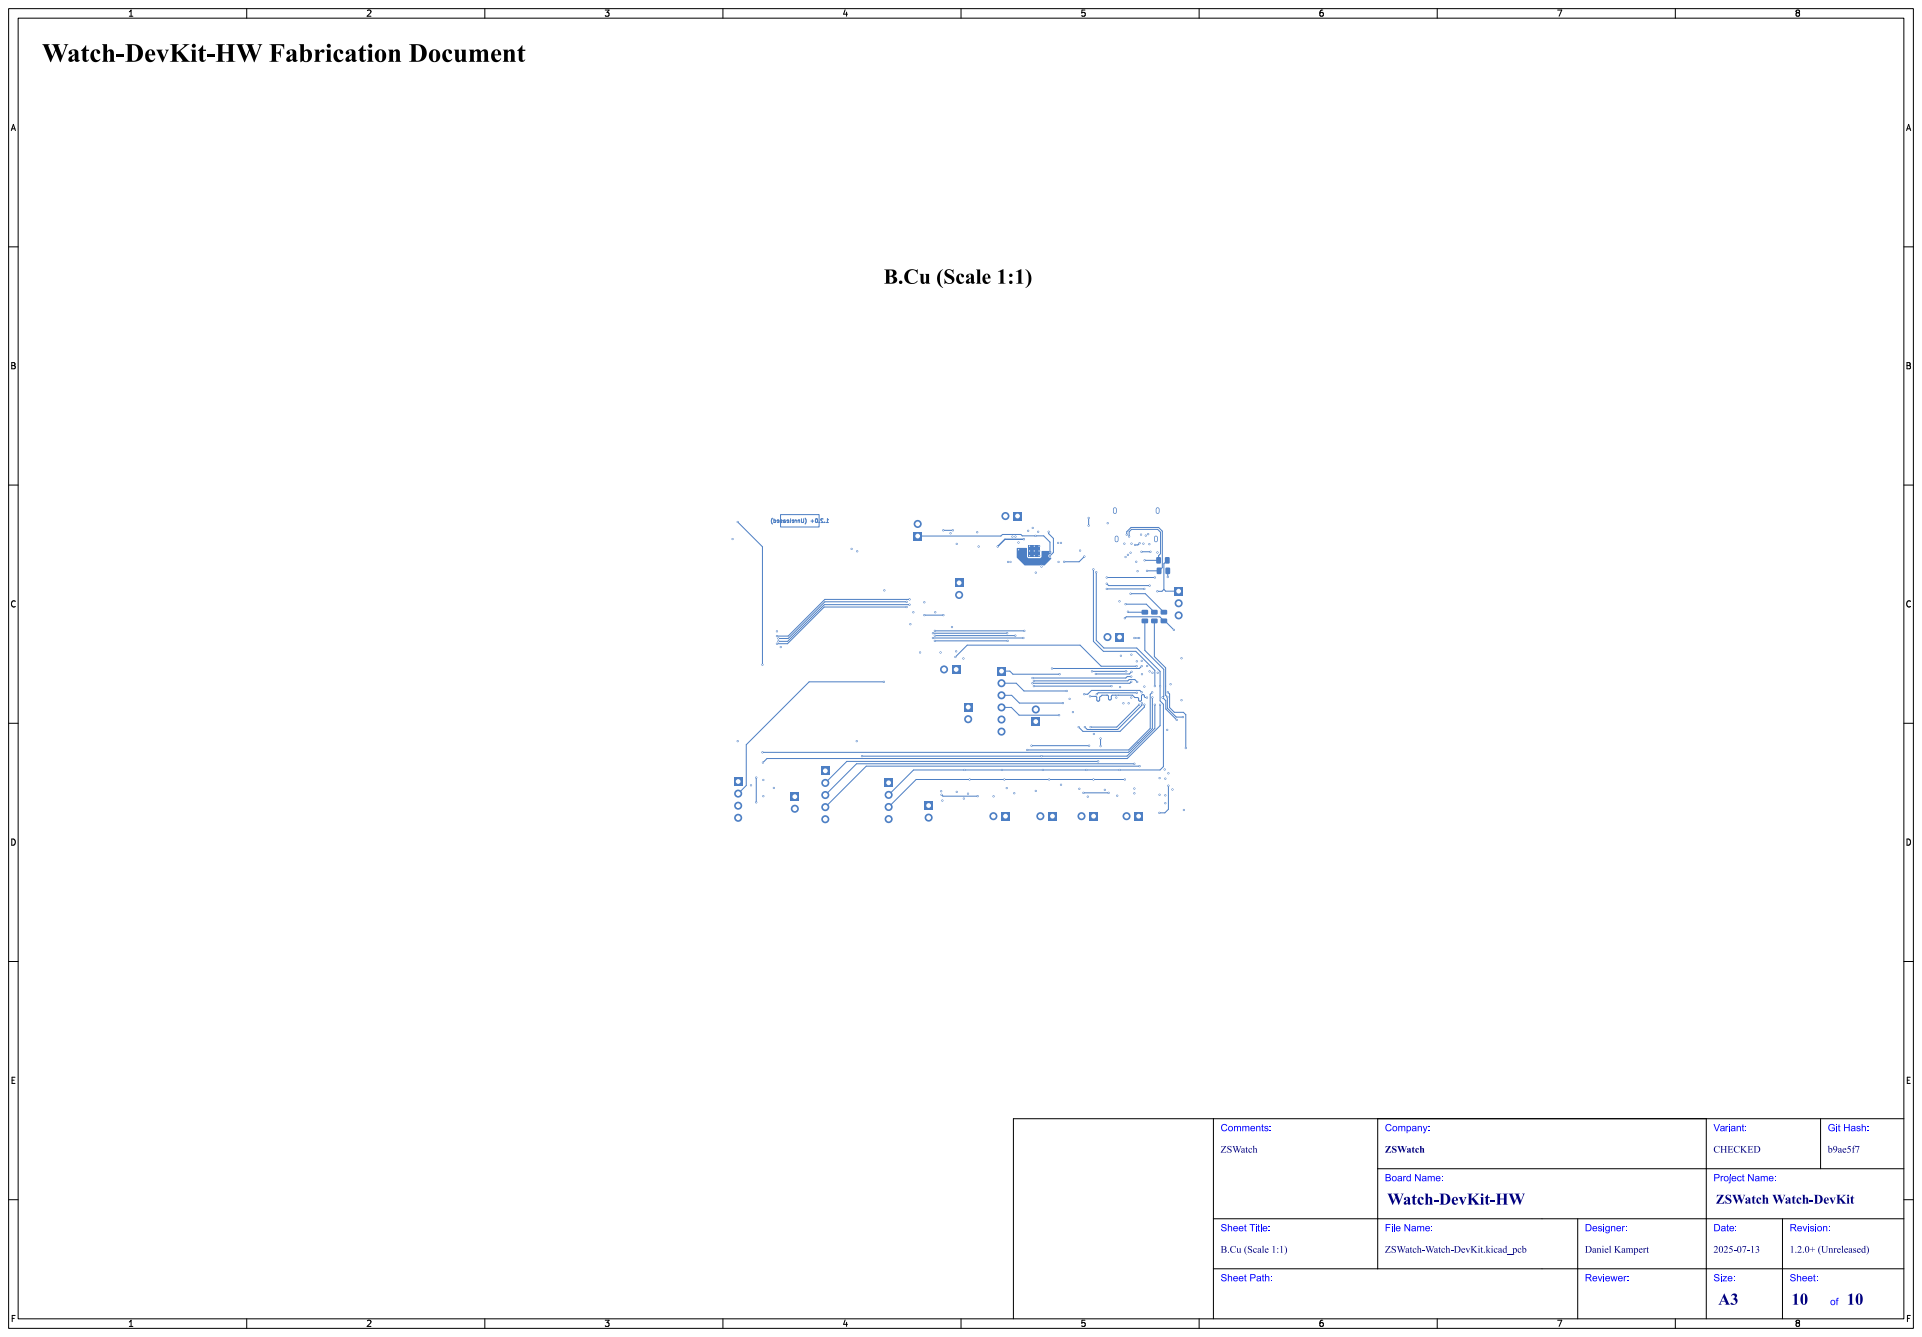
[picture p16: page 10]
Git; Hash:; ZSWatch; Comments:; B.Cu (Scale 1:1); Sheet Title:; File Name:; Watch-DevKit-HW; ZSWatch Watch-DevKit; Company:; CHECKED; Variant:; Board Name:; ZSWatch-Watch-DevKit.kicad_pcb; Daniel Kampert; Designer:; Project Name:; Date:; 1.2.0+ (Unreleased); Revision:

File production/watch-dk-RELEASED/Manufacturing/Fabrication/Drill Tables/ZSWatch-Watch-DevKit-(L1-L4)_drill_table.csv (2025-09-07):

Count | Hole Size | Plated | Hole Shape | Drill Layer Pair | Hole Type
236 | 0.25mm (9.84mils) | PTH | Round | F.Cu - B.Cu | Via
9 | 0.25mm (9.84mils) | PTH | Round | F.Cu - B.Cu | Pad
4 | 0.50mm (19.69mils) | PTH | Slot | F.Cu - B.Cu | Pad
48 | 1.00mm (39.37mils) | PTH | Round | F.Cu - B.Cu | Pad
Total 297

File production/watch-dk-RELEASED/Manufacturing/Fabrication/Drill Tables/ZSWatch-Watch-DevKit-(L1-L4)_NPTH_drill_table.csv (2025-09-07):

Count | Hole Size | Plated | Hole Shape | Drill Layer Pair | Hole Type
1 + 1 | 0.65mm (25.59mils) | NPTH | Round + Slot | F.Cu - B.Cu | Mechanical
4 | 2.50mm (98.43mils) | NPTH | Round | F.Cu - B.Cu | Mechanical
Total 6

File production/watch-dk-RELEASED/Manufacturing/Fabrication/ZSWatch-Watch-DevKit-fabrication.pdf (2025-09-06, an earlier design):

# Top Fabrication (Scale 1:1)

# Watch-DevKit-HW Fabrication Document

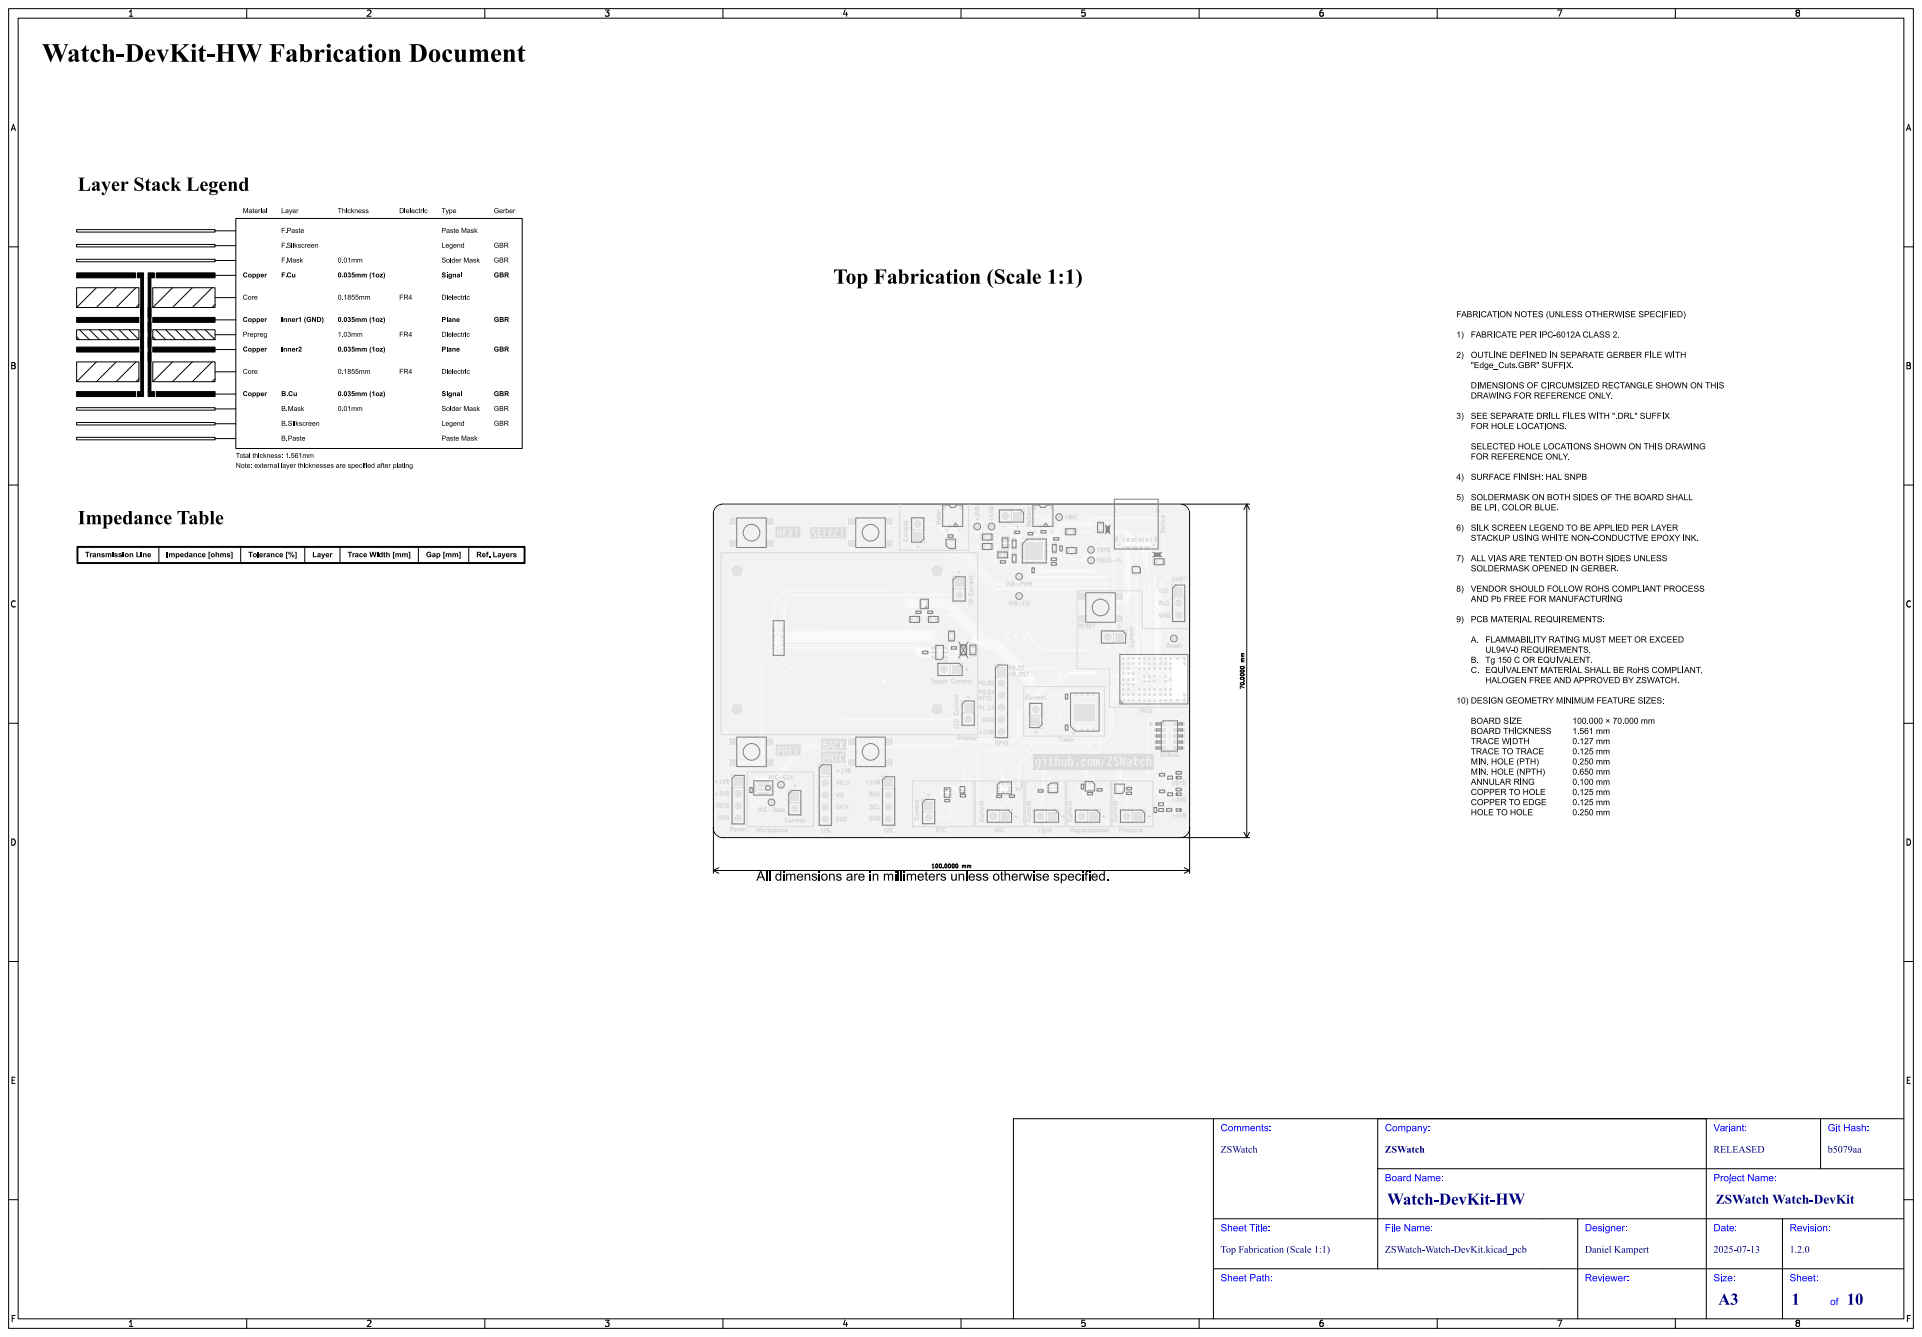
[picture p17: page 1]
Git Hash:; ZSWatch; Comments:; Sheet Path:; Sheet Title:; File Name:; Watch-DevKit-HW; ZSWatch Watch-DevKit; Company:; RELEASED; Variant:; Board Name:; ZSWatch-Watch-DevKit.kicad_pcb; Daniel Kampert; Designer:; Reviewer:; Project Name:; Date:; Revision:; Size:; Sheet:; Current; RESET; VSYS; VBUS-In; VBAT; GPIO; MIC-Data; Touch Current; MIC-CLK; Reset; Device; VIB-EN; Battery; UART; IO Current; Power; LED Current; Motor; DEBUG; VIB-PWM; HR_RST; DATA; Pressure; GND; Flash; RxD; Light; Microphone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

Top Fabrication (Scale 1:1)

# Bottom Fabrication (Scale 1:1)

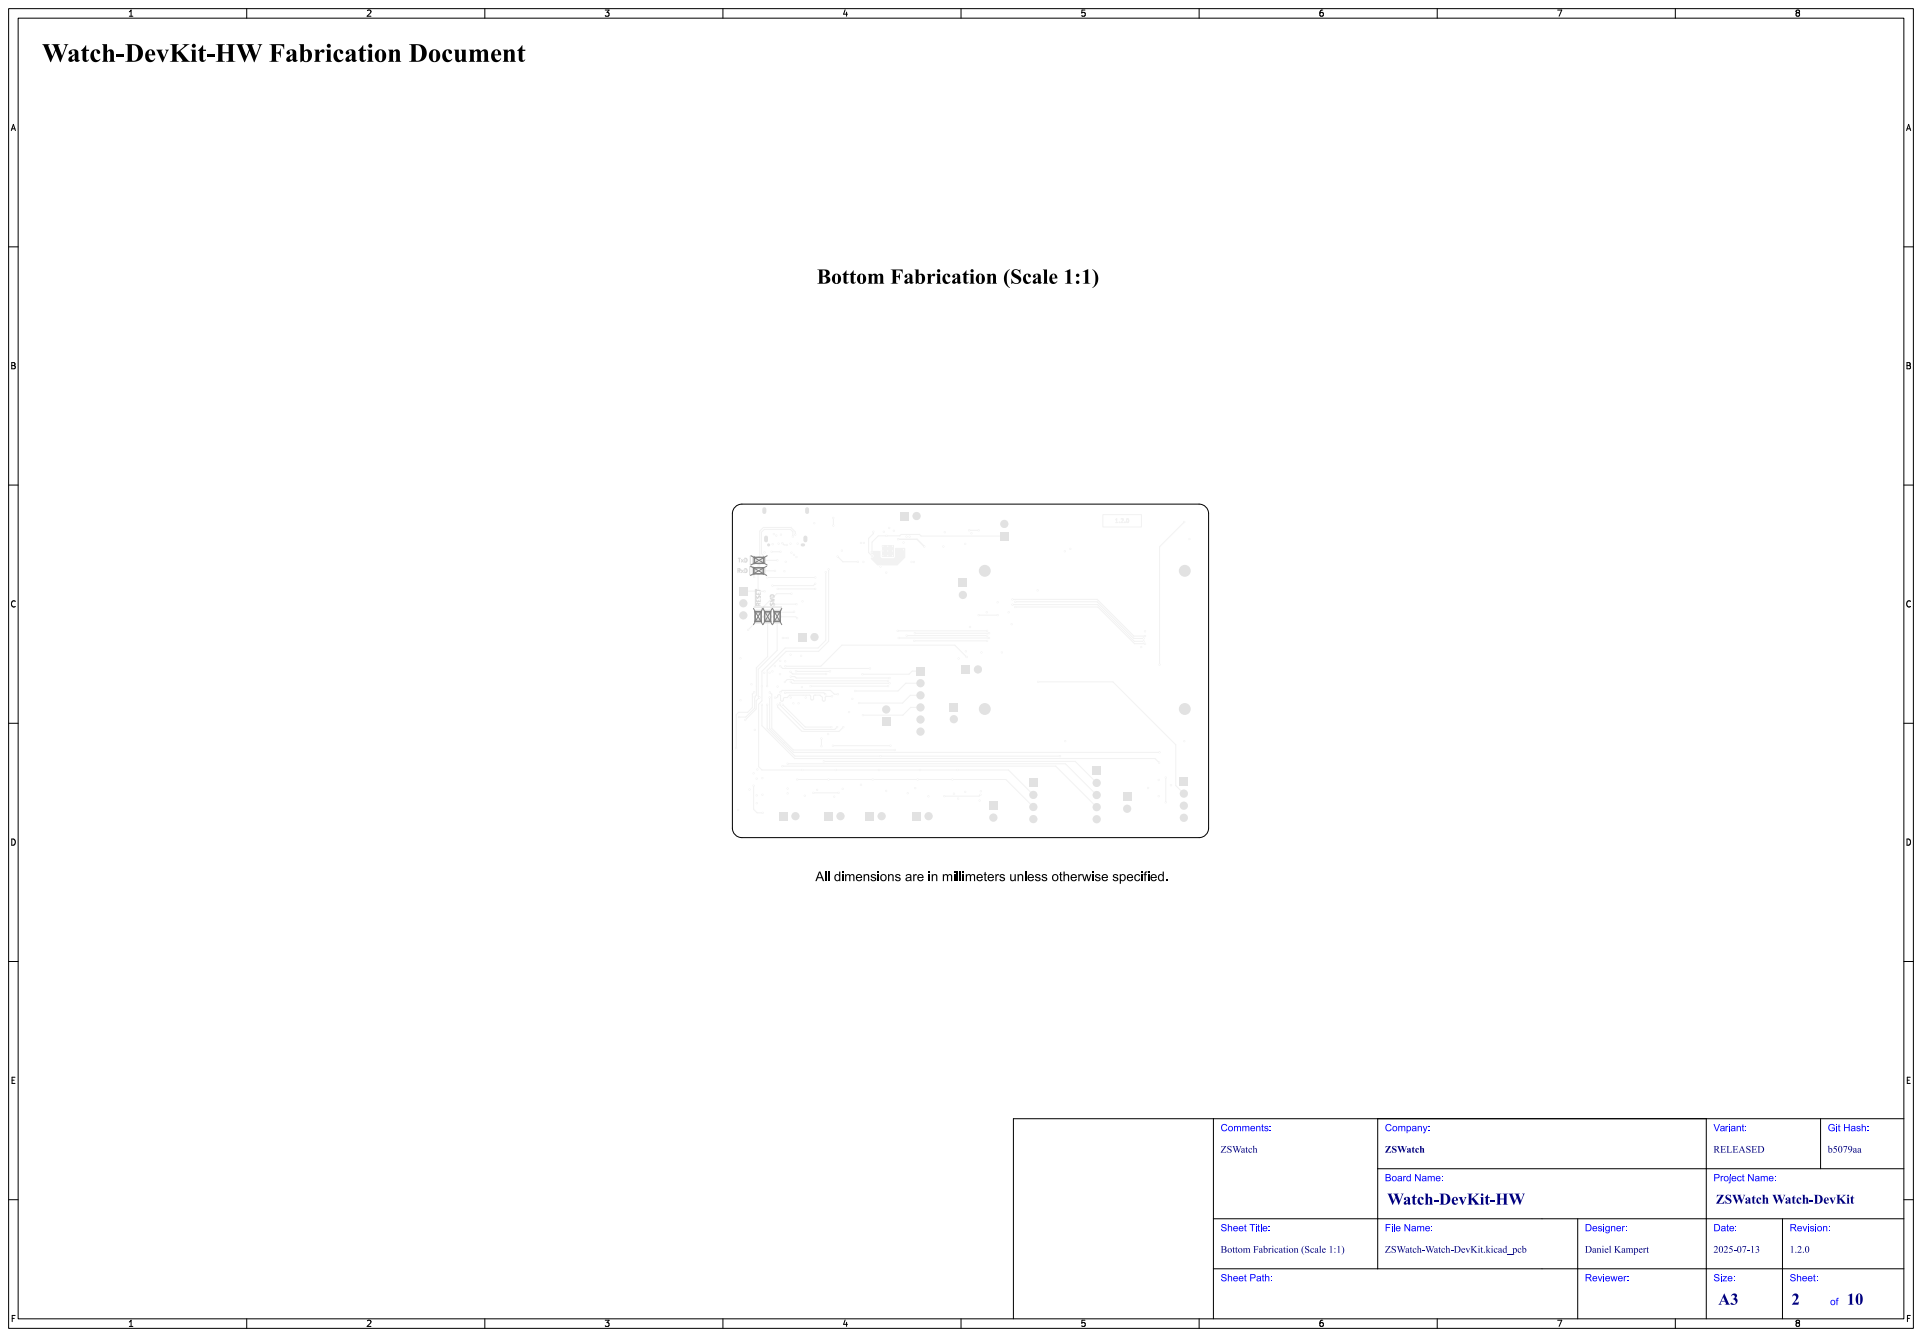
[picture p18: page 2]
Git; Hash:; ZSWatch; Comments:; Sheet Title:; File Name:; Watch-DevKit-HW; ZSWatch Watch-DevKit; Company:; RELEASED; Variant:; Board Name:; ZSWatch-Watch-DevKit.kicad_pcb; Daniel Kampert; Designer:; Project Name:; Date:; Revision:; RxD; TxD; ~{RESET}; SWD

Bottom Fabrication (Scale 1:1)

# Drill Drawing L1 - L4 (Scale 1:1)

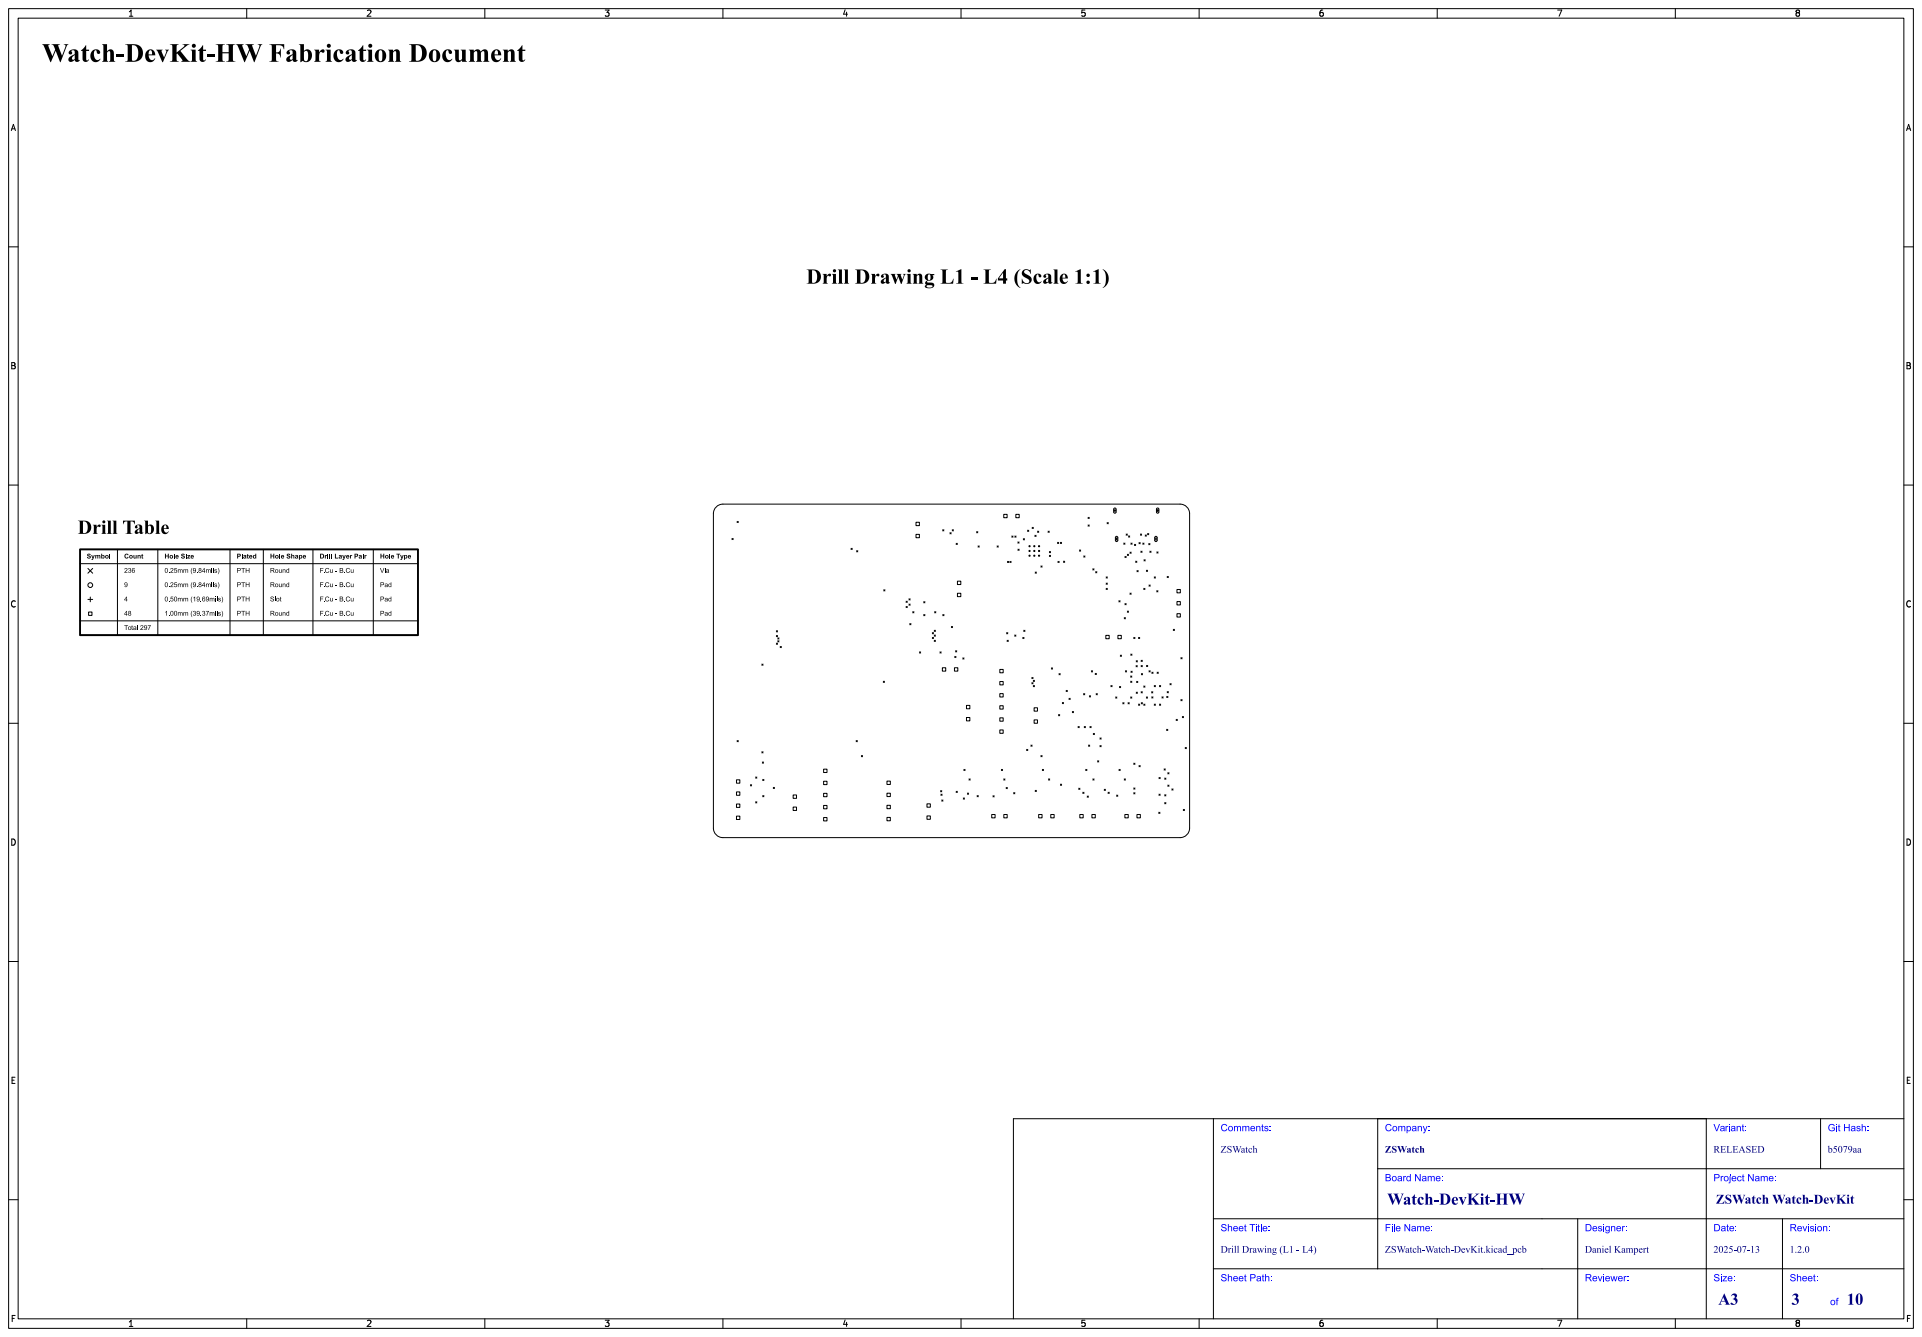
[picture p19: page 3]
Git; Hash:; ZSWatch; Comments:; Drill Drawing (L1 - L4); Sheet Title:; File Name:; Watch-DevKit-HW; ZSWatch Watch-DevKit; Company:; RELEASED; Variant:; Board Name:; ZSWatch-Watch-DevKit.kicad_pcb; Daniel Kampert; Designer:; Project Name:; Date:; Revision:

# Drill Drawing L1 - L4 (Scale 1:1)

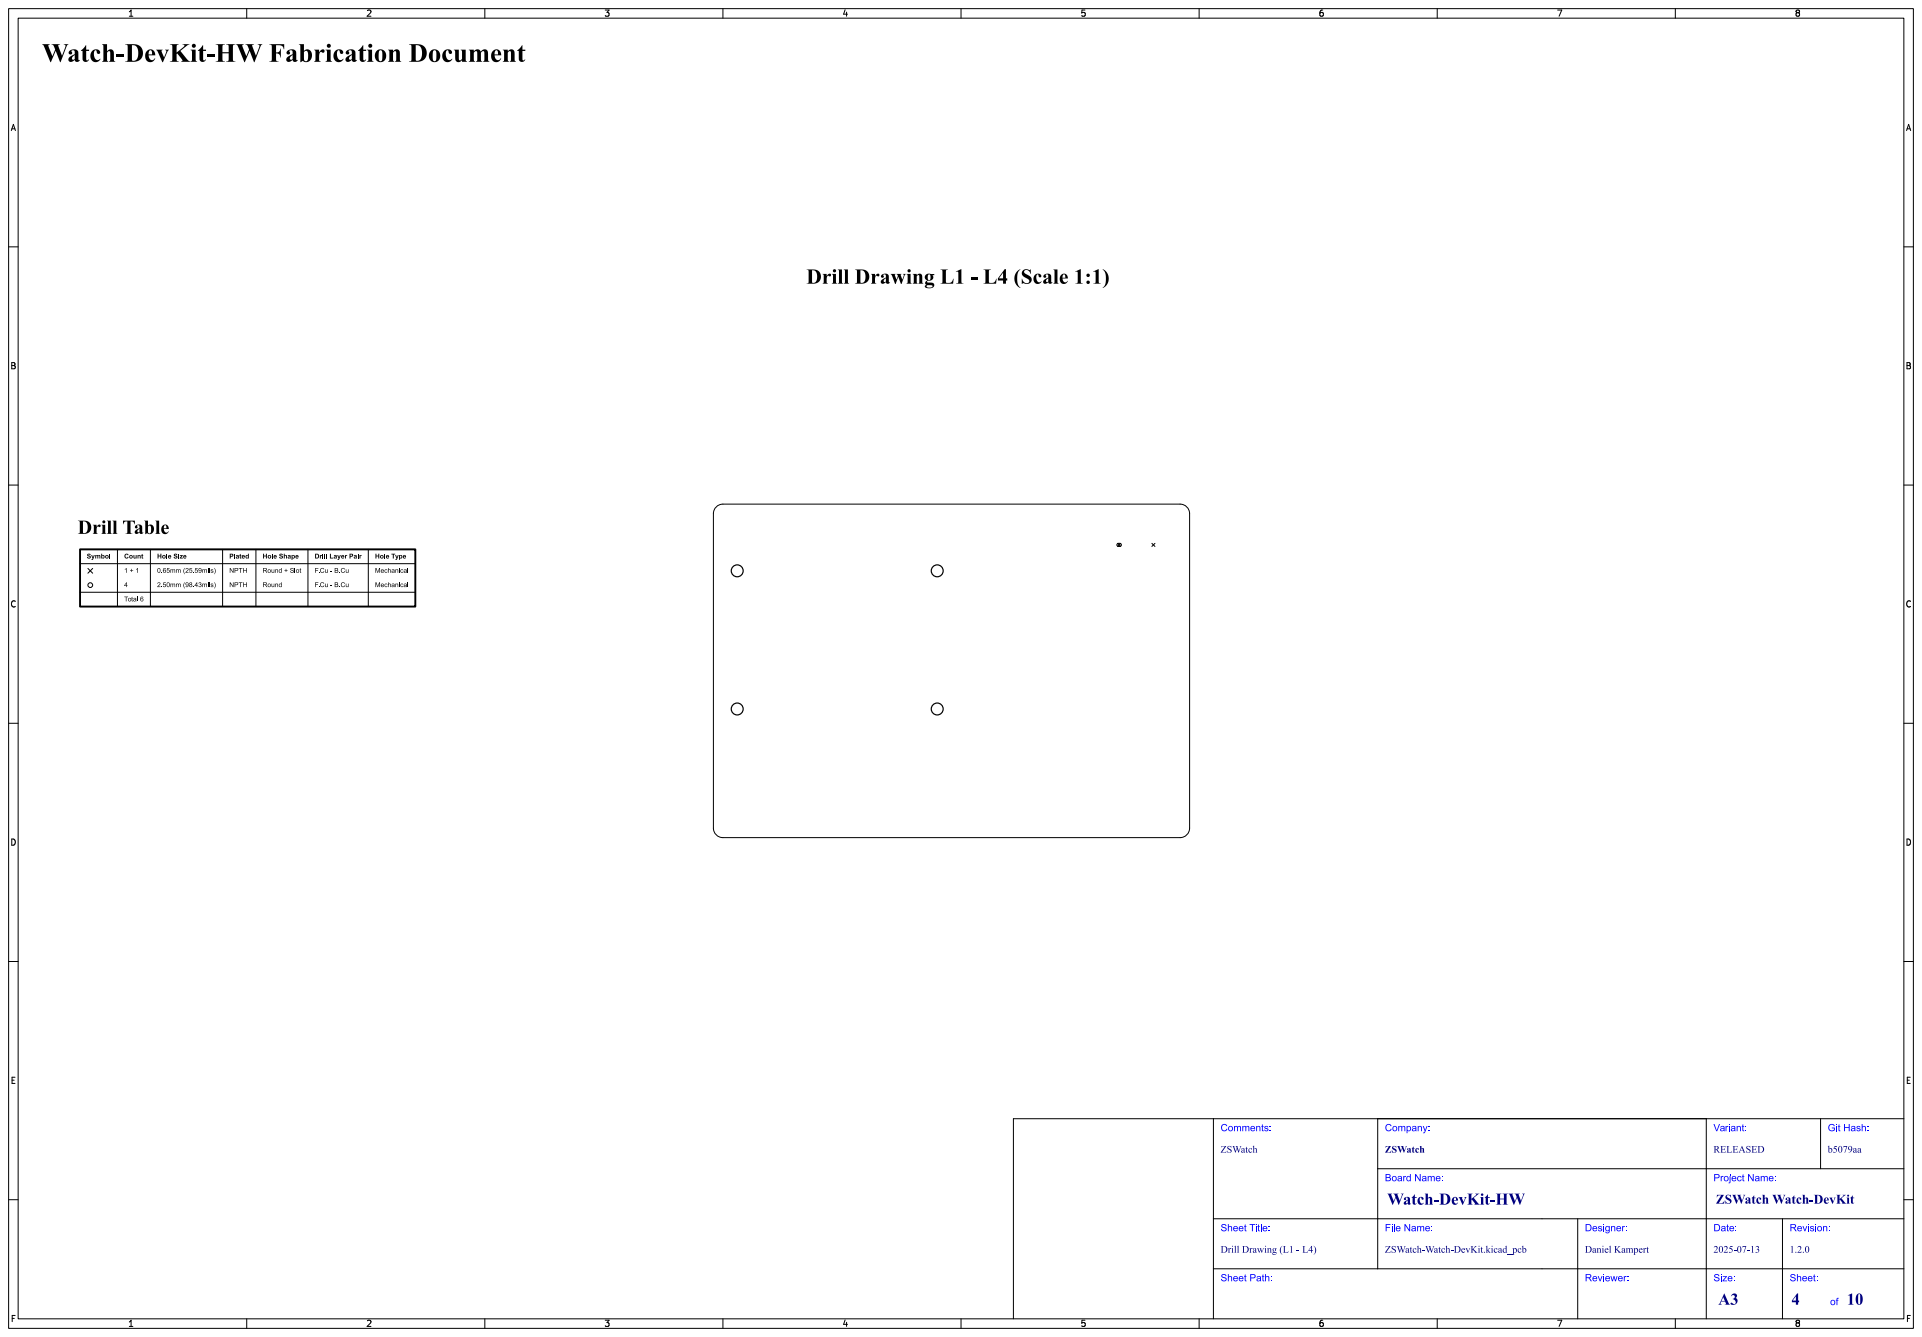
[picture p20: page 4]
Git; Hash:; ZSWatch; Comments:; Drill Drawing (L1 - L4); Sheet Title:; File Name:; Watch-DevKit-HW; ZSWatch Watch-DevKit; Company:; RELEASED; Variant:; Board Name:; ZSWatch-Watch-DevKit.kicad_pcb; Daniel Kampert; Designer:; Project Name:; Date:; Revision:

# Top Test Points (Scale 1:1)

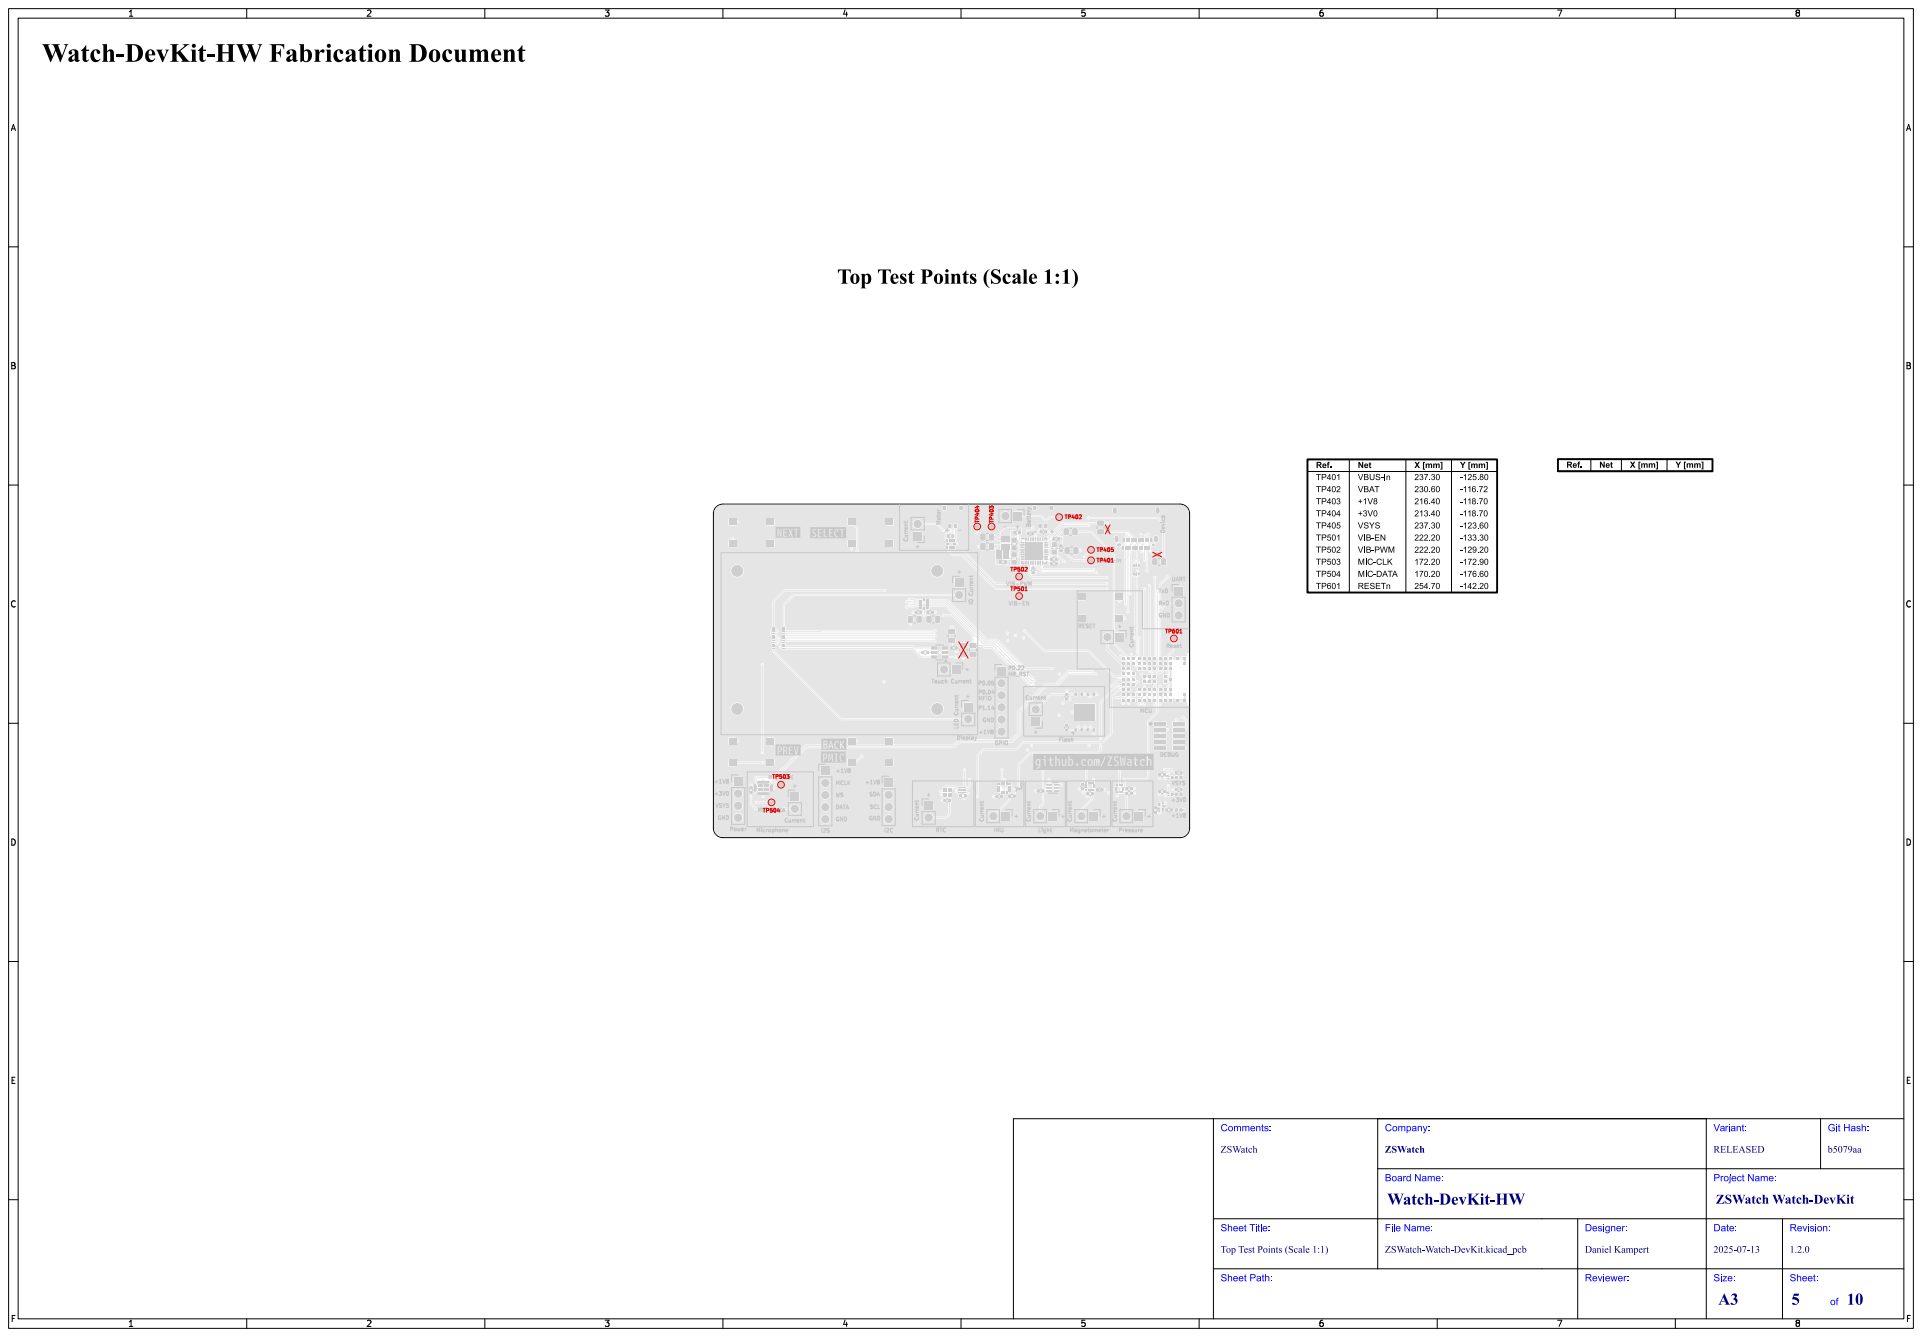
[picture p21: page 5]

Top Test Points (Scale 1:1)

# Bottom Test Points (Scale 1:1)

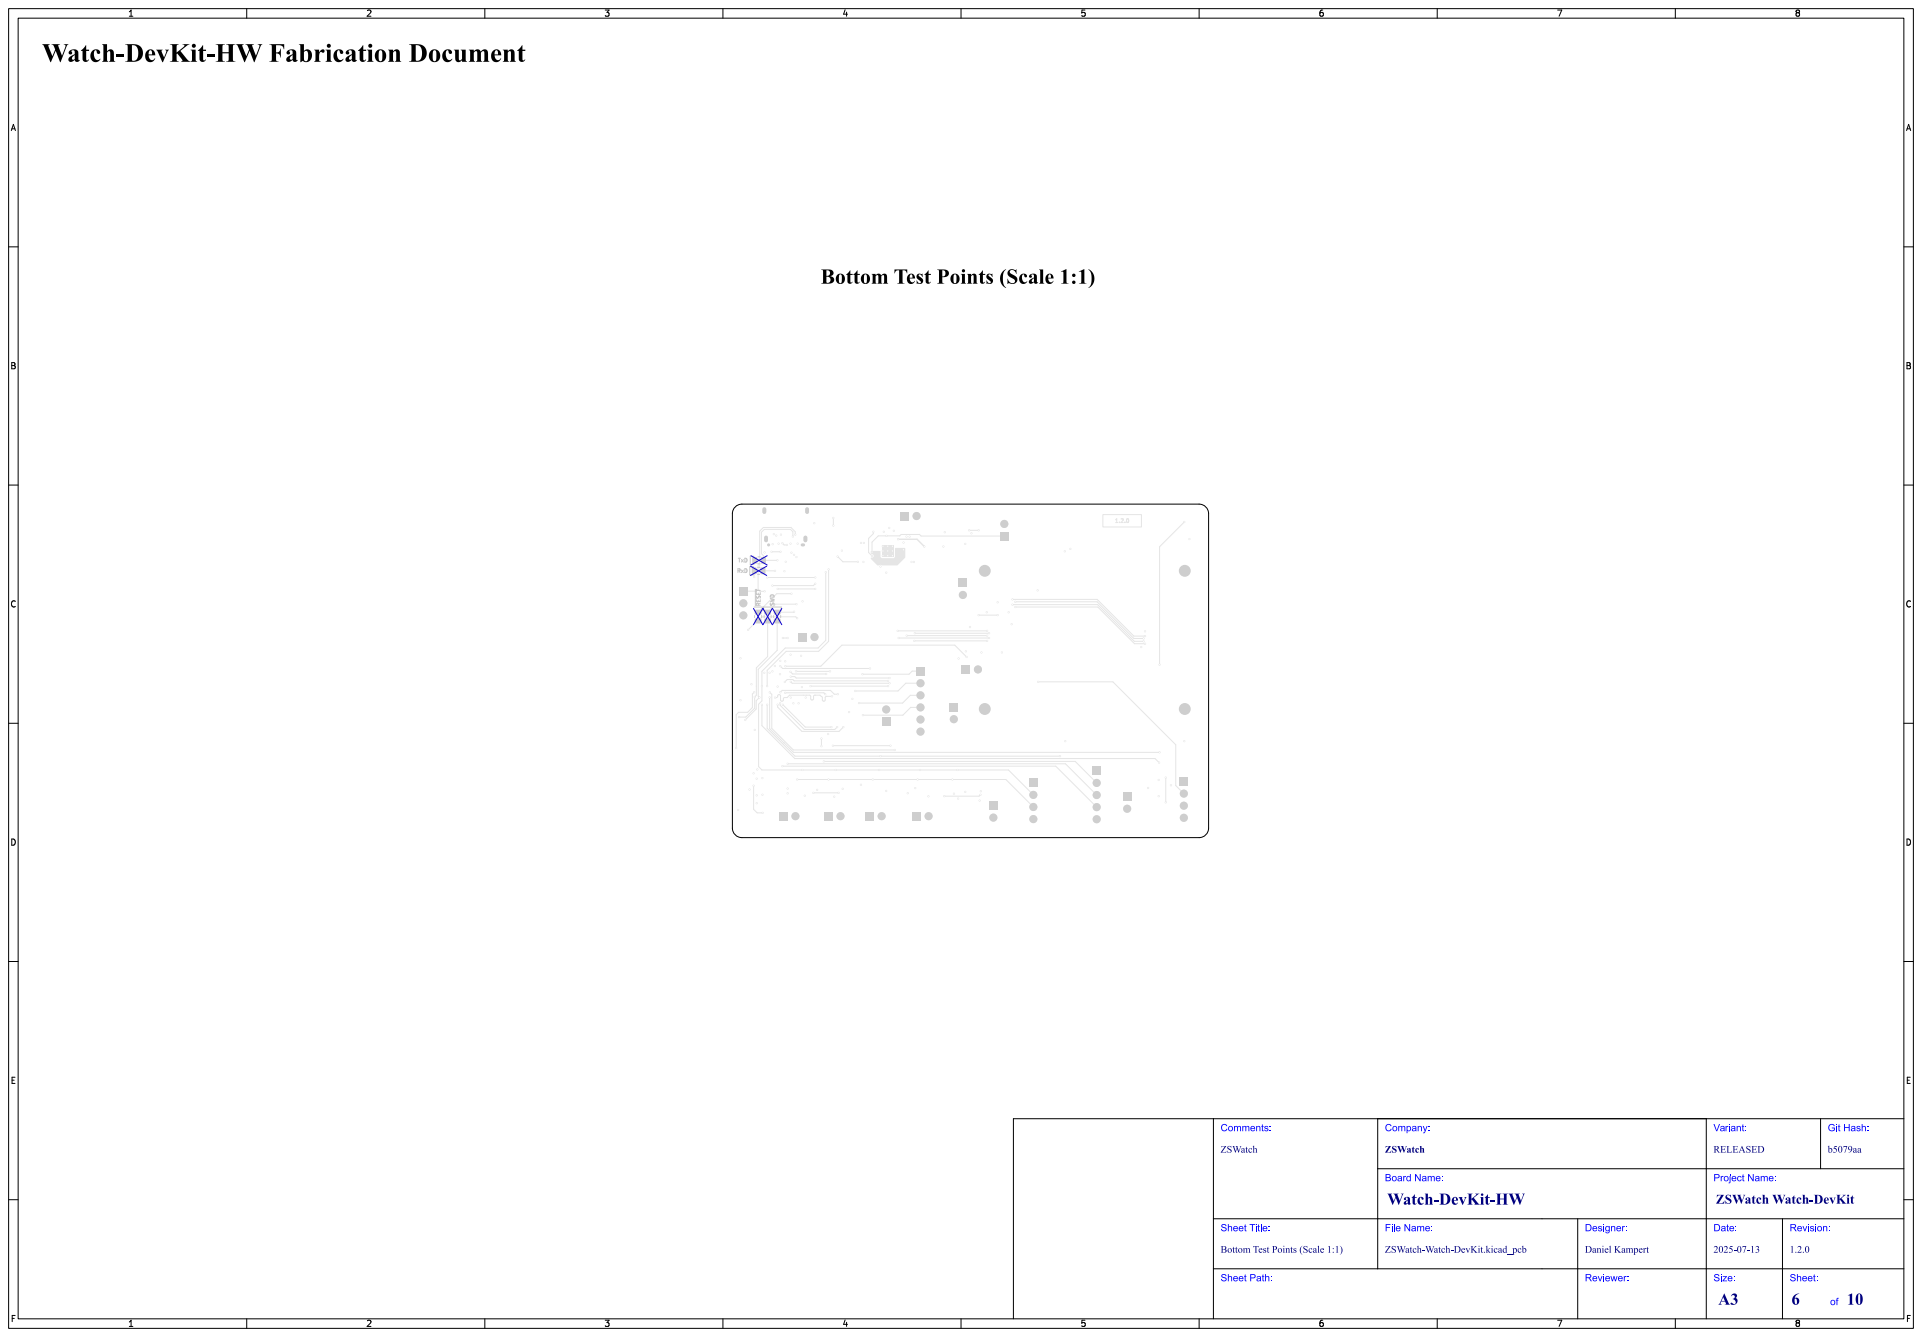
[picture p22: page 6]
Git; Hash:; ZSWatch; Comments:; Sheet Title:; File Name:; Watch-DevKit-HW; ZSWatch Watch-DevKit; Company:; RELEASED; Variant:; Board Name:; ZSWatch-Watch-DevKit.kicad_pcb; Daniel Kampert; Designer:; Project Name:; Date:; Revision:; RxD; TxD; ~{RESET}; SWD

Bottom Test Points (Scale 1:1)

# F.Cu (Scale 1:1)

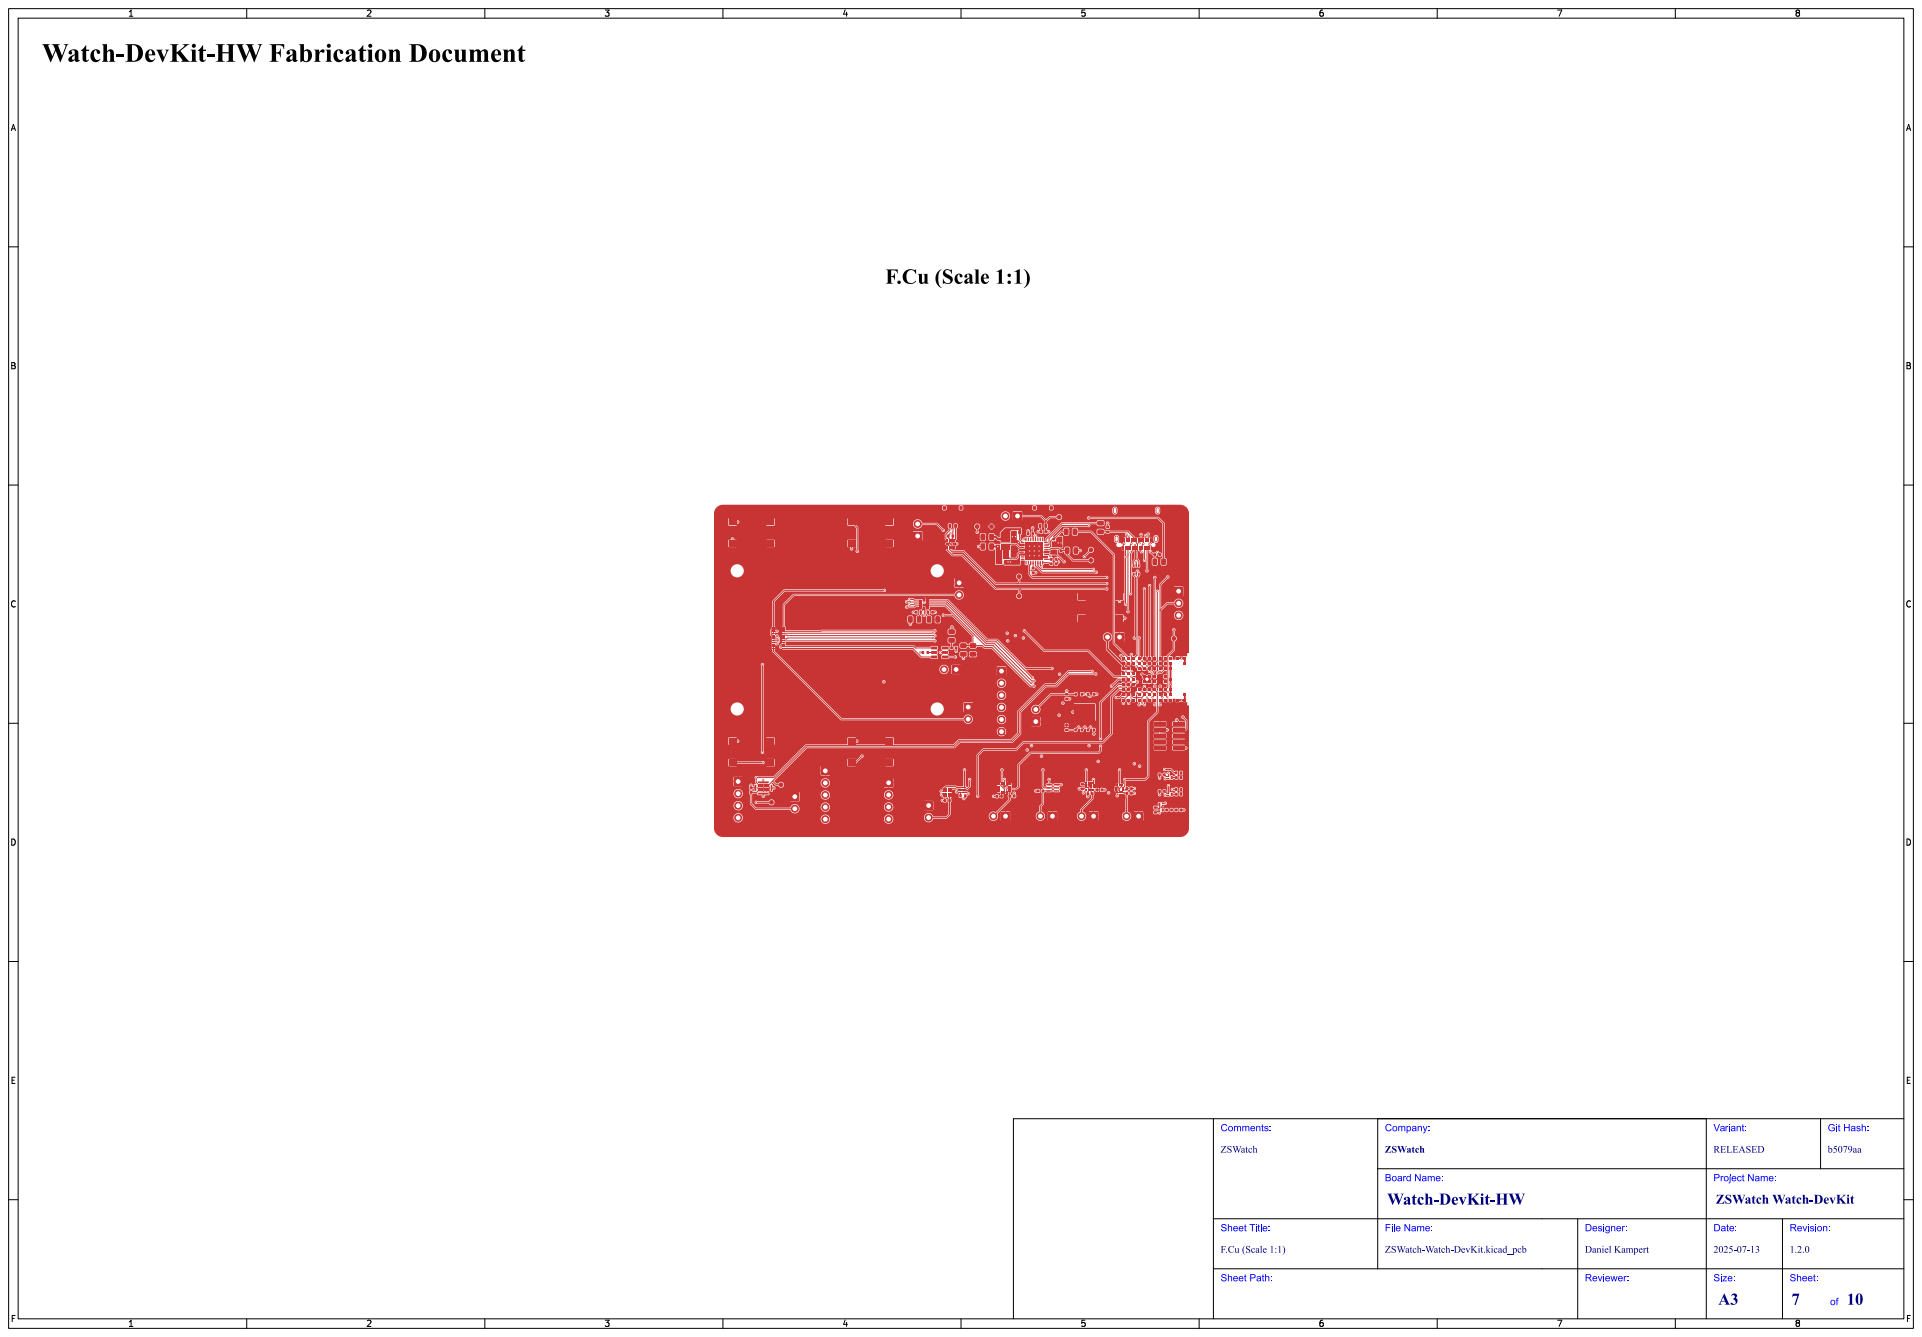
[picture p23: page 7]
Git; Hash:; ZSWatch; Comments:; F.Cu (Scale 1:1); Sheet Title:; File Name:; Watch-DevKit-HW; ZSWatch Watch-DevKit; Company:; RELEASED; Variant:; Board Name:; ZSWatch-Watch-DevKit.kicad_pcb; Daniel Kampert; Designer:; Project Name:; Date:; Revision:

# Inner1 (GND) (Scale 1:1)

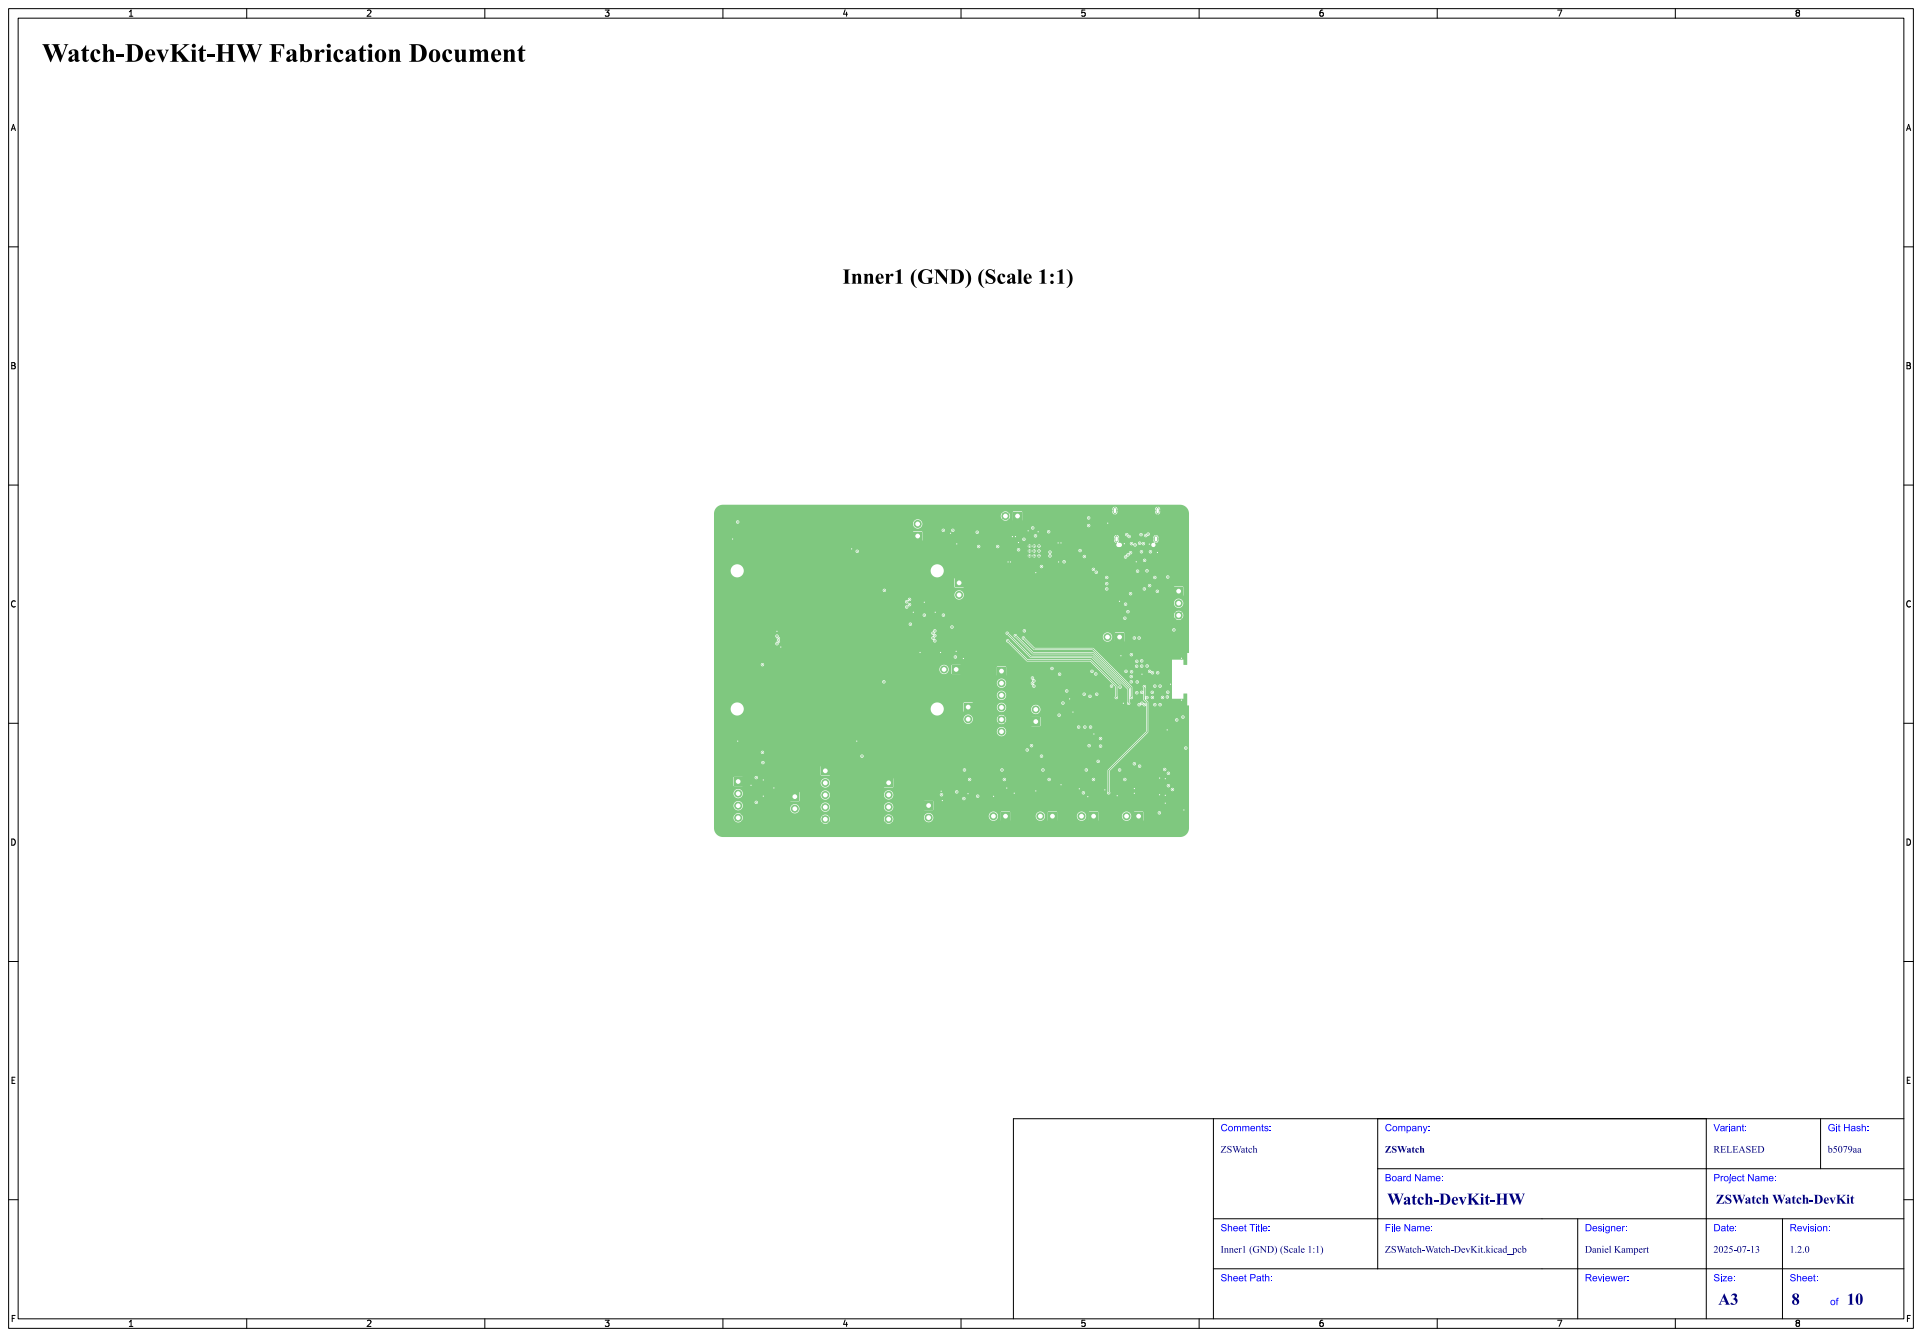
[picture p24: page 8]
Git; Hash:; ZSWatch; Comments:; Inner1 (GND) (Scale 1:1); Sheet Title:; File Name:; Watch-DevKit-HW; ZSWatch Watch-DevKit; Company:; RELEASED; Variant:; Board Name:; ZSWatch-Watch-DevKit.kicad_pcb; Daniel Kampert; Designer:; Project Name:; Date:; Revision:

# Inner2 (Scale 1:1)

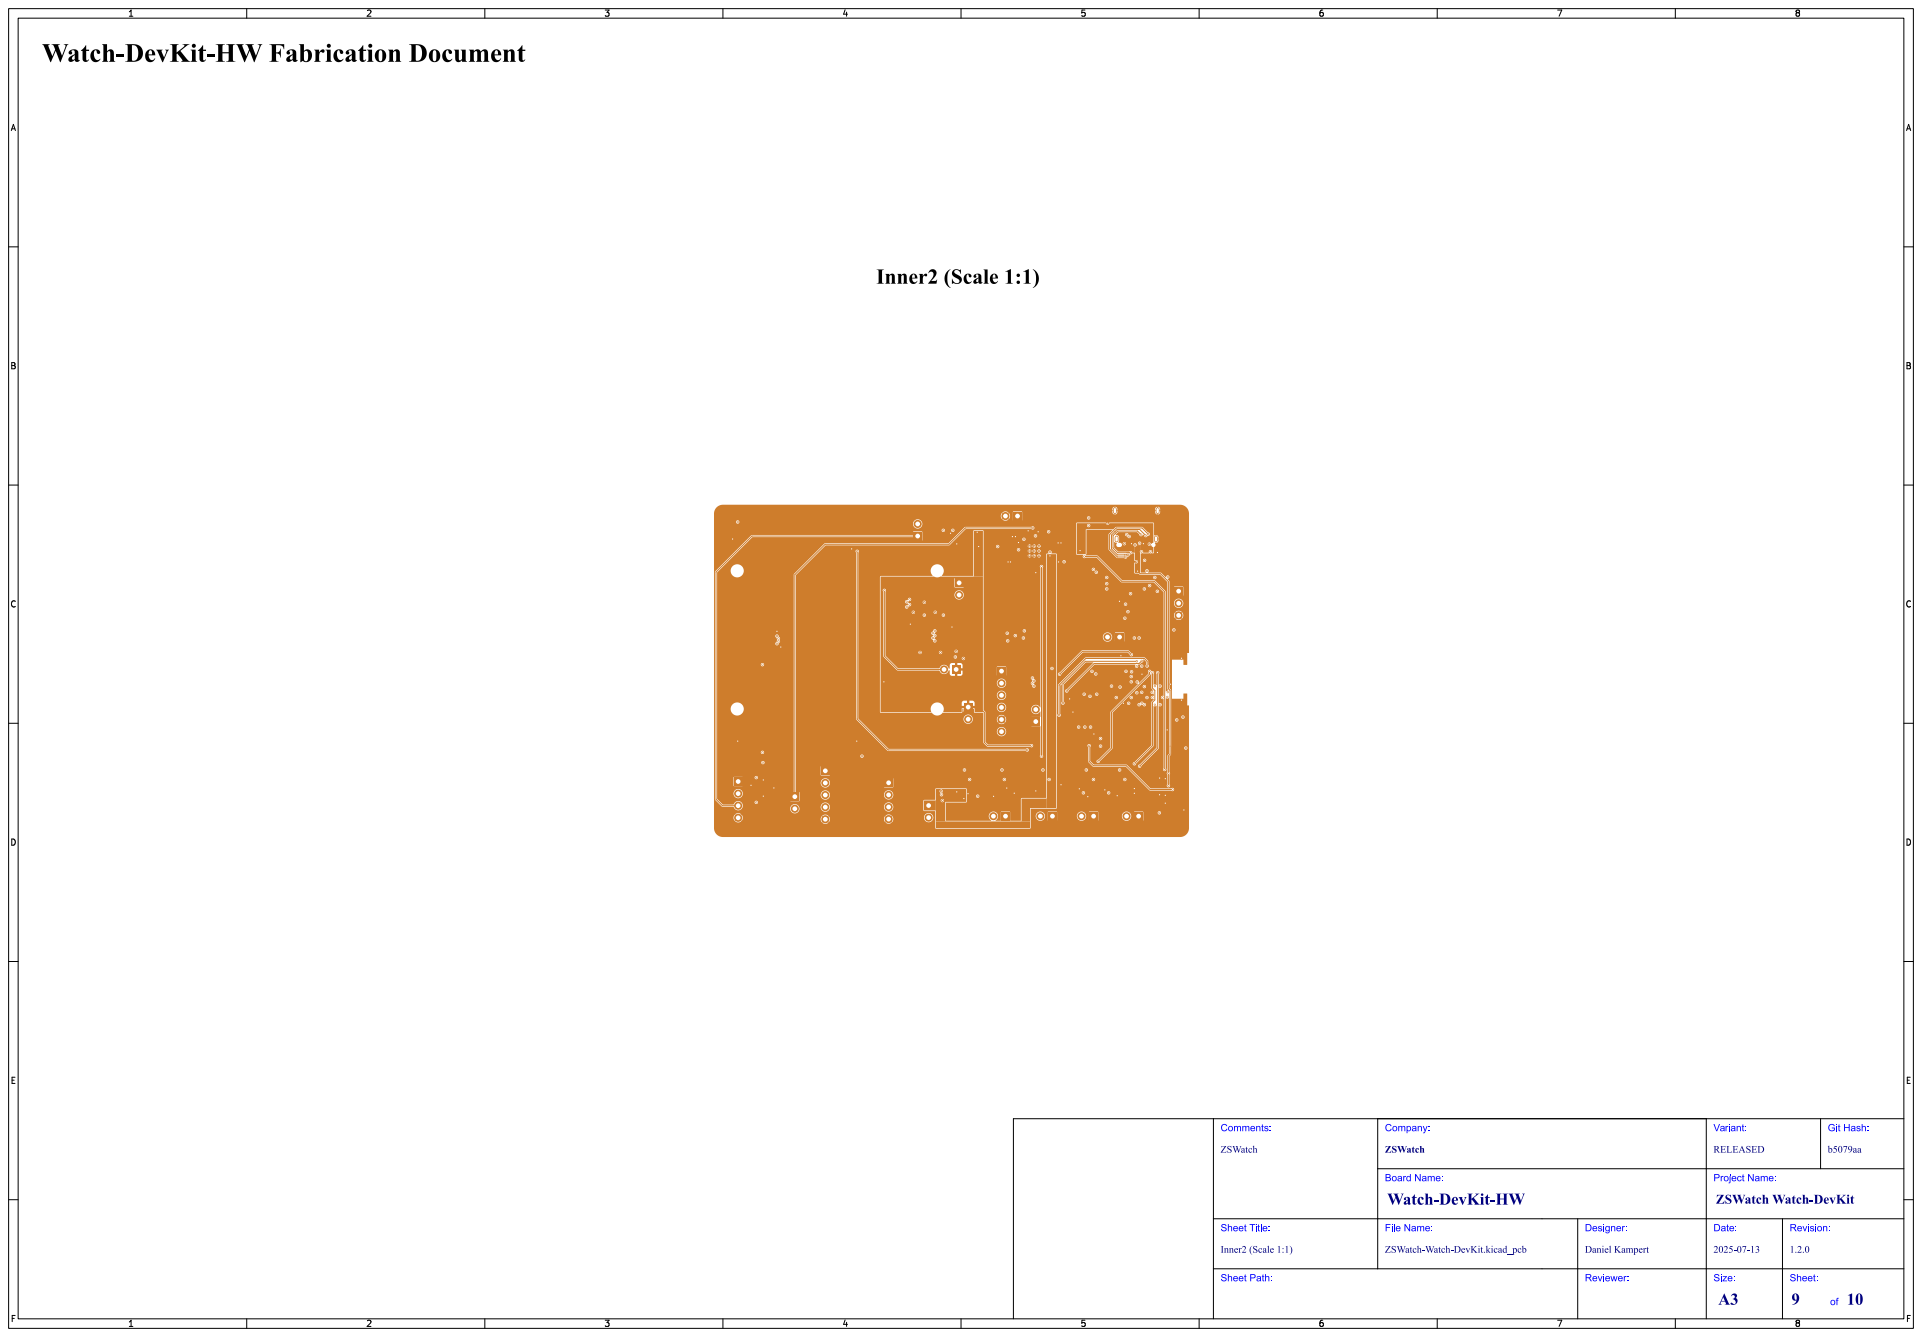
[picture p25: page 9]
Git; Hash:; ZSWatch; Comments:; Inner2 (Scale 1:1); Sheet Title:; File Name:; Watch-DevKit-HW; ZSWatch Watch-DevKit; Company:; RELEASED; Variant:; Board Name:; ZSWatch-Watch-DevKit.kicad_pcb; Daniel Kampert; Designer:; Project Name:; Date:; Revision:

# B.Cu (Scale 1:1)

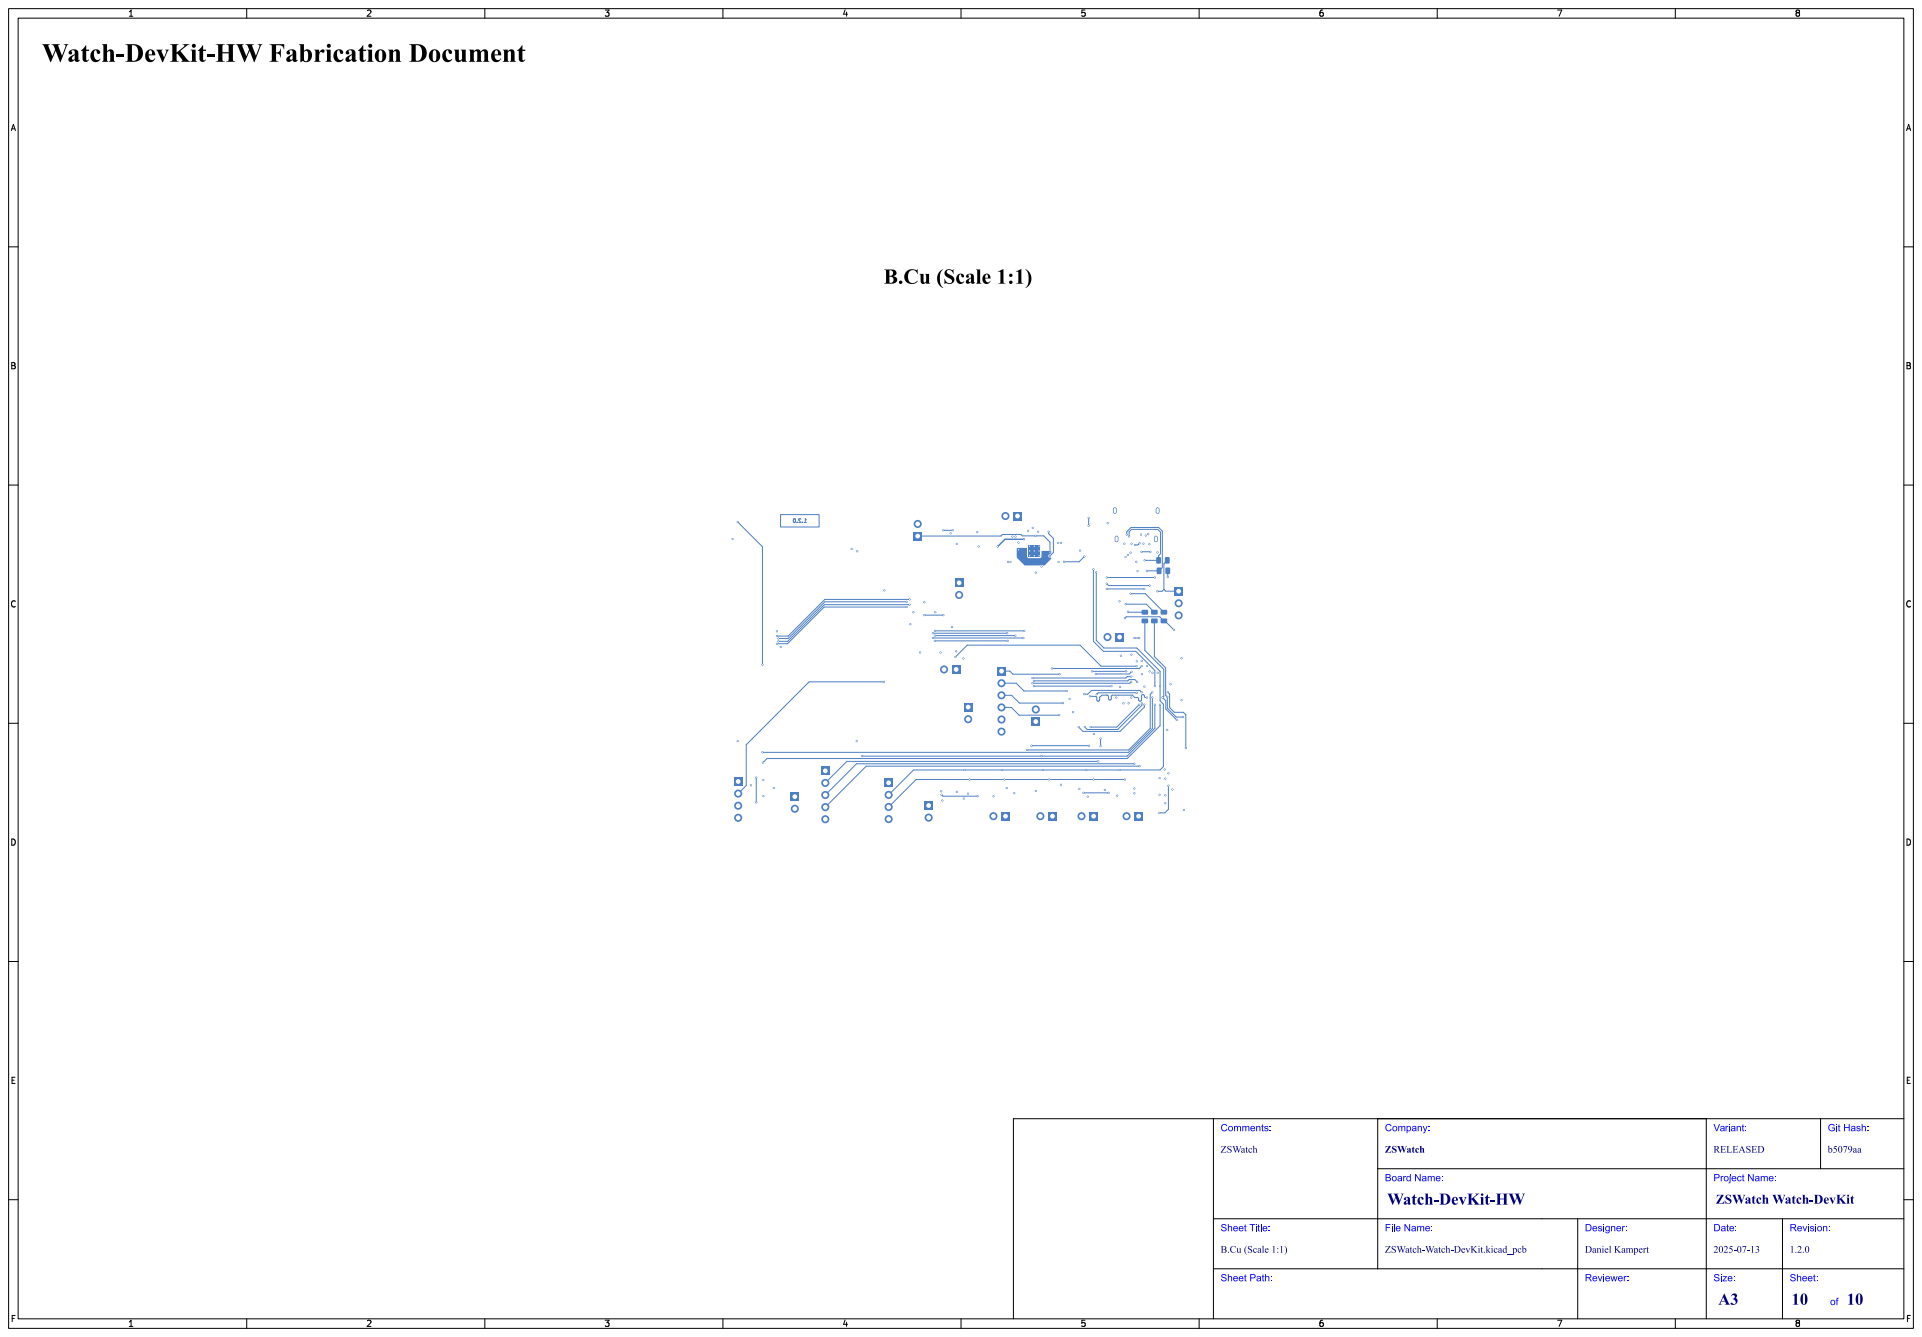
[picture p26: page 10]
Git; Hash:; ZSWatch; Comments:; B.Cu (Scale 1:1); Sheet Title:; File Name:; Watch-DevKit-HW; ZSWatch Watch-DevKit; Company:; RELEASED; Variant:; Board Name:; ZSWatch-Watch-DevKit.kicad_pcb; Daniel Kampert; Designer:; Project Name:; Date:; Revision:

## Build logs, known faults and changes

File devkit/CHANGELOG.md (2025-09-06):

# Changelog

## [Unreleased]

## [1.2.0] - 2025-09-06

### Fixed

-   Fix wrong orientation for SWD header (#117)
-   Fix missing and wrong part numbers

### Added

-   Add pull-up resistor for display enable signal. Can be disabled via GPIO. (#123)
-   Add new KiBot template (#116)
-   Add orientation marker for IMU (#124)
-   Add power LEDs (#128)
-   Add reset button (#131)
-   Add testpoints for microphone I2S (#145)

### Changed

-   Shrink down the PCB to save costs (#115)
-   Replace pin headers with THT to make them more robust (#121)
-   Rename "Power" jumpers to "Current" (#129)
-   Replace level shifter for RTC with PCA9306GF (#133)
-   Switch back to old LED driver (#134)
-   Power microphone from PMIC (#145)
-   Increase length of QSPI Clock line to avoid timing issues
-   Replace programming connector with the variant from the Dock

### Removed

-   Remove APDS-9306 interrupt (#122)
-   Remove watch casing from repository

[Unreleased]: https://github.com/Kampi/Watch-DK-HW/compare/1.2.0...HEAD

[1.2.0]: https://github.com/Kampi/Watch-DK-HW/compare/fc3844fb6a647a23e214f3085a47ce2212e0d98a...1.2.0

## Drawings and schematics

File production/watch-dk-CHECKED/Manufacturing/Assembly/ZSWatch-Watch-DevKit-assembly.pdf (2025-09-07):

# Watch-DevKit-HW Assembly Document

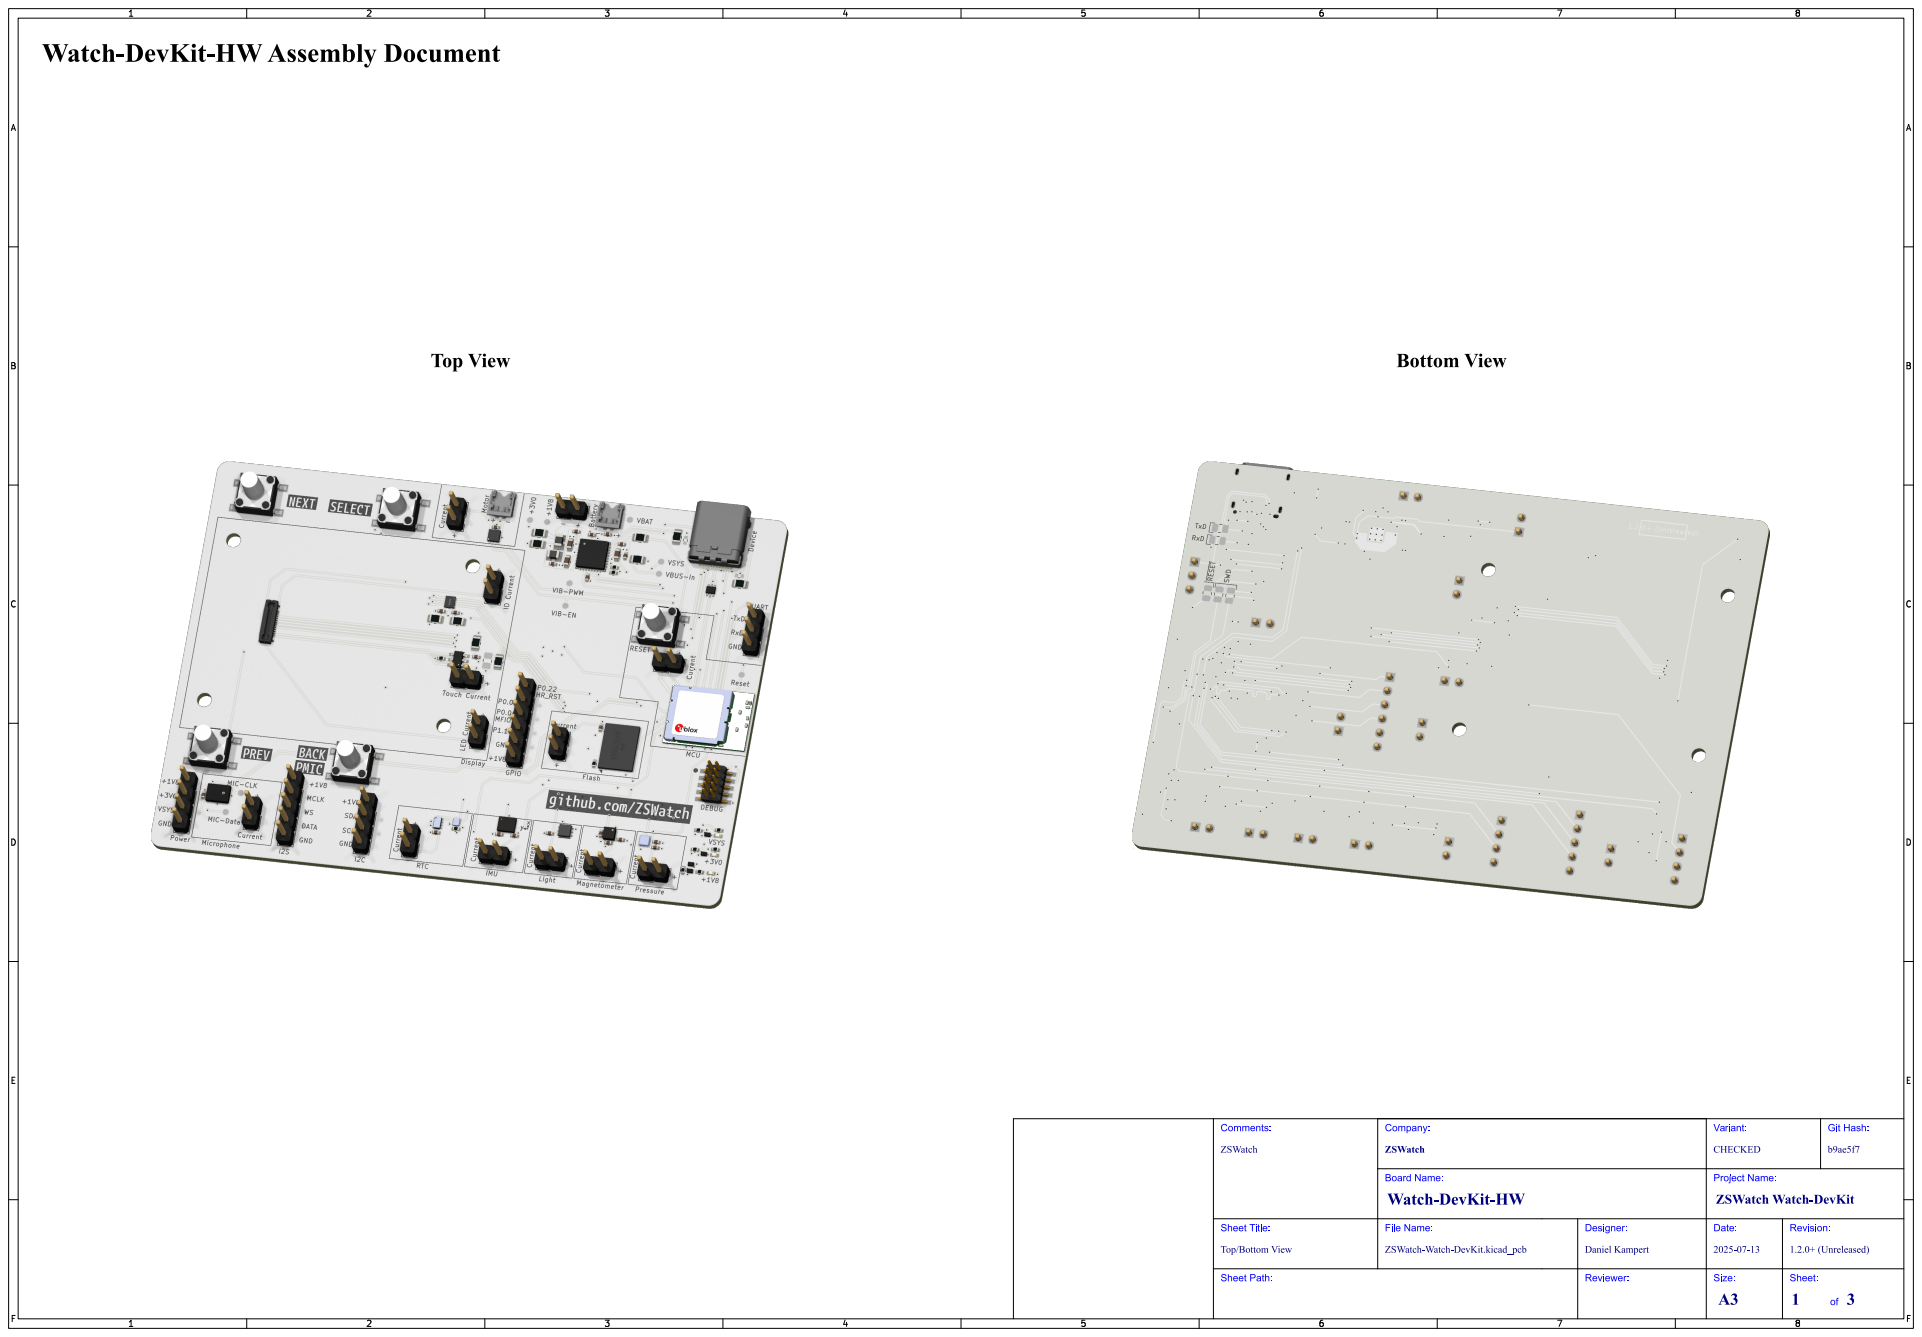
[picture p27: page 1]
Git; Hash:; ZSWatch; Comments:; Sheet Path:; Sheet Title:; File Name:; Watch-DevKit-HW; ZSWatch Watch-DevKit; Company:; CHECKED; Variant:; Board Name:; ZSWatch-Watch-DevKit.kicad_pcb; Daniel Kampert; Designer:; Reviewer:; Project Name:; Date:; 1.2.0+ (Unreleased); Revision:; Size:; Sheet:

Top/Bottom View

# Top Assembly (Scale 1:1)

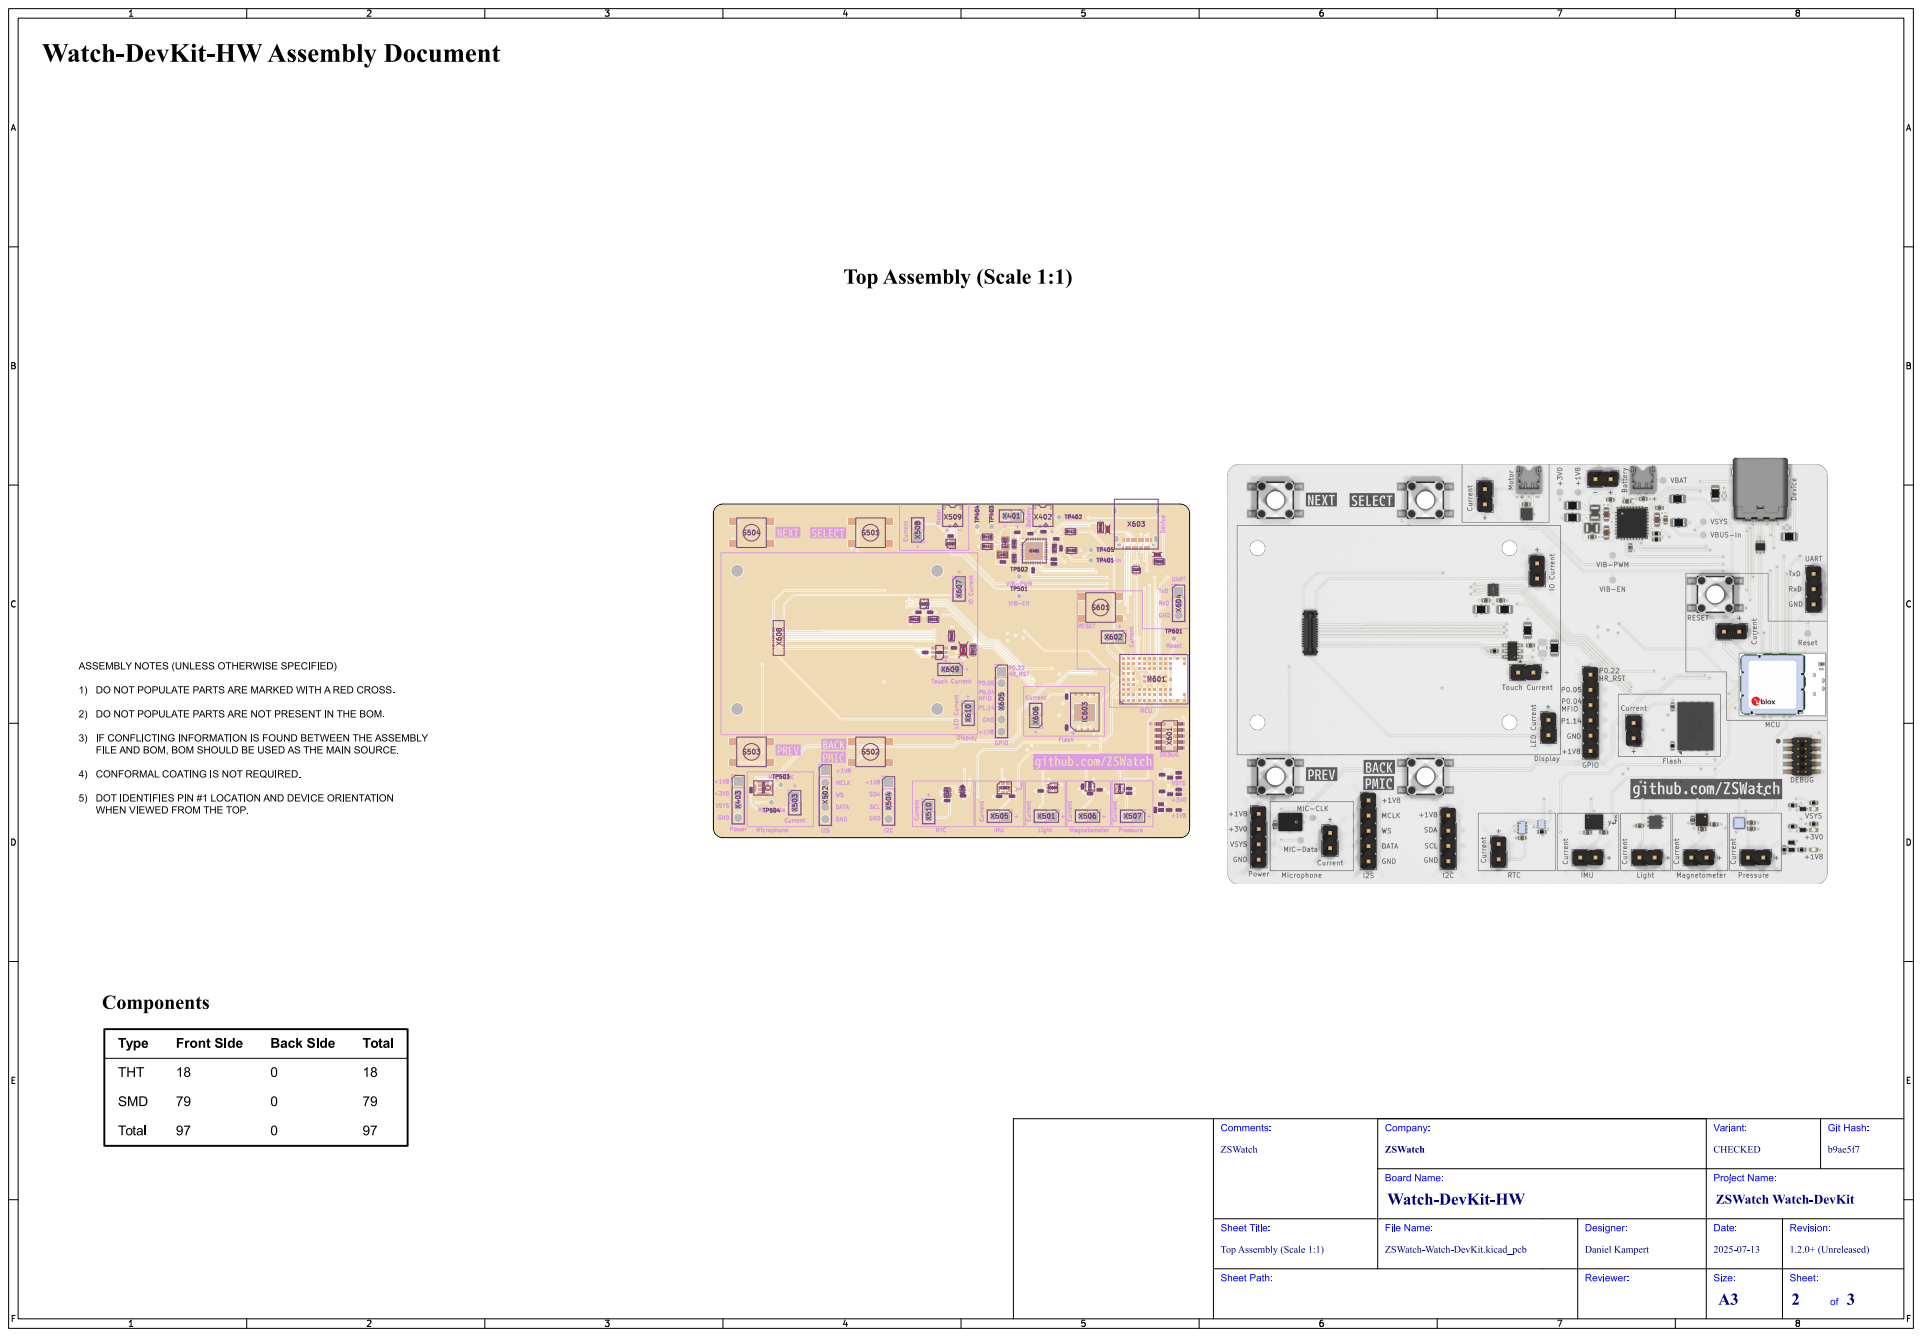
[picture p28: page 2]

# Bottom Assembly (Scale 1:1)

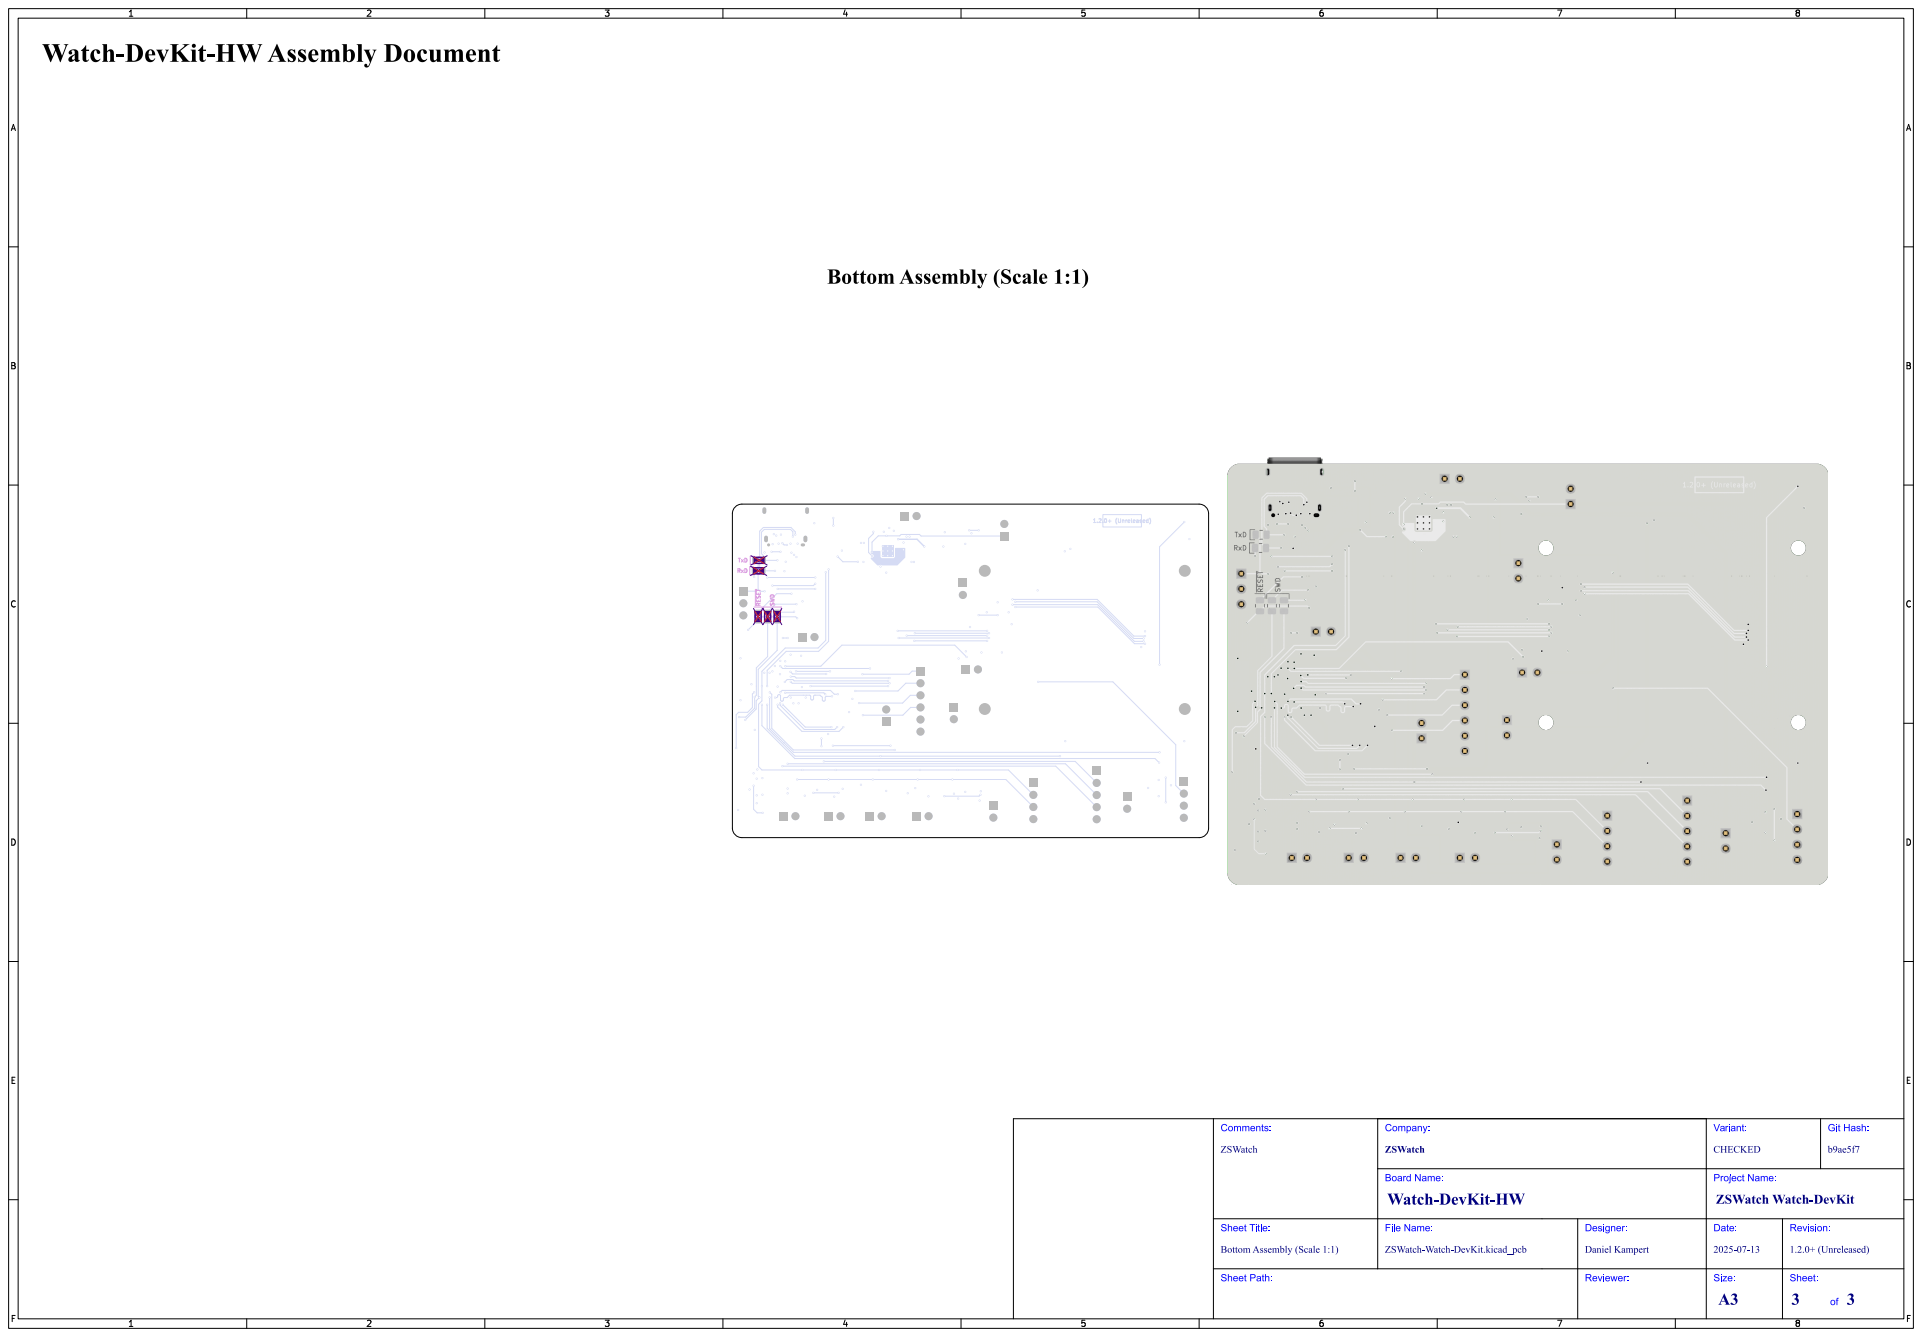
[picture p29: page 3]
Git; Hash:; ZSWatch; Comments:; Sheet Title:; File Name:; Watch-DevKit-HW; ZSWatch Watch-DevKit; Company:; CHECKED; Variant:; Board Name:; ZSWatch-Watch-DevKit.kicad_pcb; Daniel Kampert; Designer:; Project Name:; Date:; 1.2.0+ (Unreleased); Revision:; RxD; TxD; ~{RESET}; SWD

Bottom Assembly (Scale 1:1)

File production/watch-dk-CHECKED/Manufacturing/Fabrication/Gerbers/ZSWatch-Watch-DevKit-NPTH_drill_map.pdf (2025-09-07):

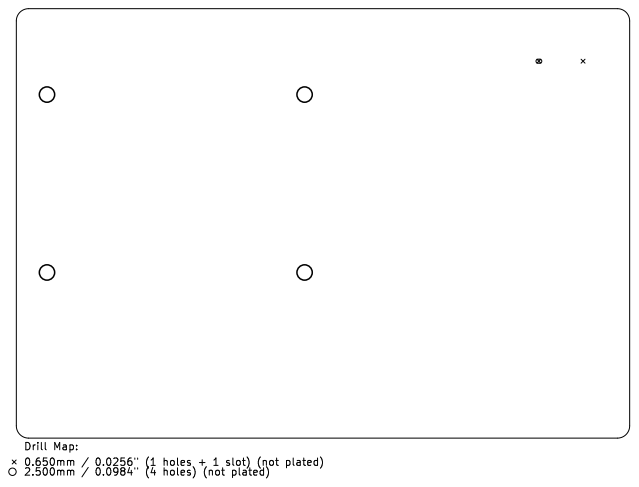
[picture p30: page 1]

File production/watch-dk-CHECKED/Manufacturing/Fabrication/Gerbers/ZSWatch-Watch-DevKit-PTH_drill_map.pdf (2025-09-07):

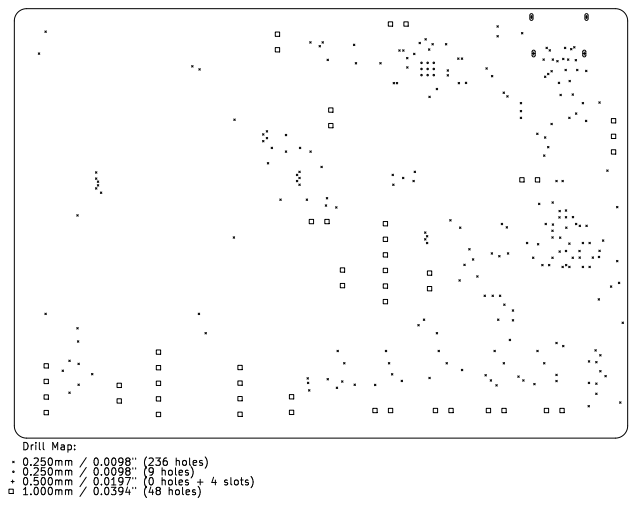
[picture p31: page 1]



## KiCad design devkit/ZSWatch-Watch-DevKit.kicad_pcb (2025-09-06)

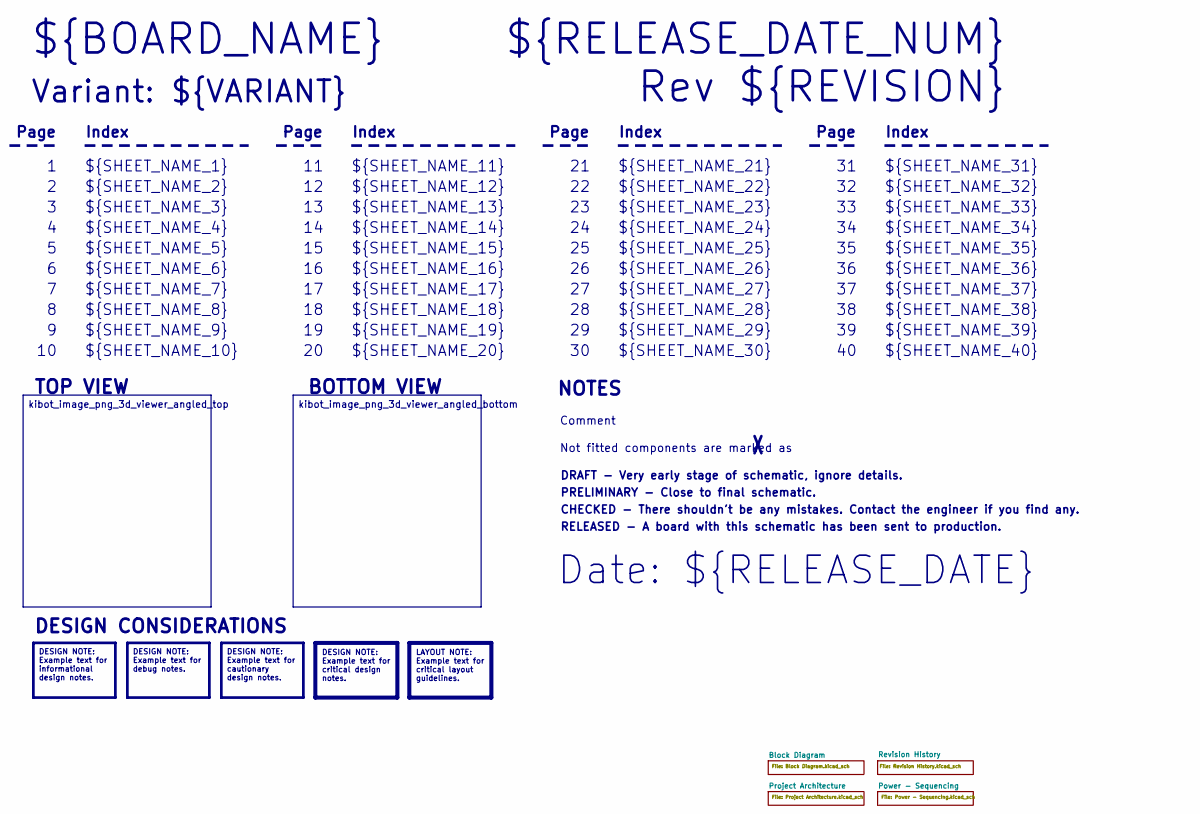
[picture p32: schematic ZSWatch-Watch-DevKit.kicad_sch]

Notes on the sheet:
Variant: ${VARIANT}
RELEASED - A board with this schematic has been sent to production.
${SHEET_NAME_24}
Index
Page
PRELIMINARY - Close to final schematic.
${SHEET_NAME_22}
DRAFT - Very early stage of schematic, ignore details.
${SHEET_NAME_12}
${SHEET_NAME_8}
${SHEET_NAME_2}
${SHEET_NAME_5}
${SHEET_NAME_20}
${SHEET_NAME_23}
${RELEASE_DATE_NUM}
${SHEET_NAME_35}
Not fitted components are marked as
${SHEET_NAME_11}
${SHEET_NAME_6}
${SHEET_NAME_37}
${SHEET_NAME_26}
${SHEET_NAME_36}
Rev ${REVISION}
${SHEET_NAME_15}
CHECKED - There shouldn't be any mistakes. Contact the engineer if you find any.
BOTTOM VIEW
${SHEET_NAME_14}
${SHEET_NAME_21}
${SHEET_NAME_17}
${SHEET_NAME_18}
Date: ${RELEASE_DATE}
${SHEET_NAME_7}
${SHEET_NAME_31}
${BOARD_NAME}
NOTES
${SHEET_NAME_40}
${SHEET_NAME_39}
${SHEET_NAME_32}
${SHEET_NAME_1}
${SHEET_NAME_9}

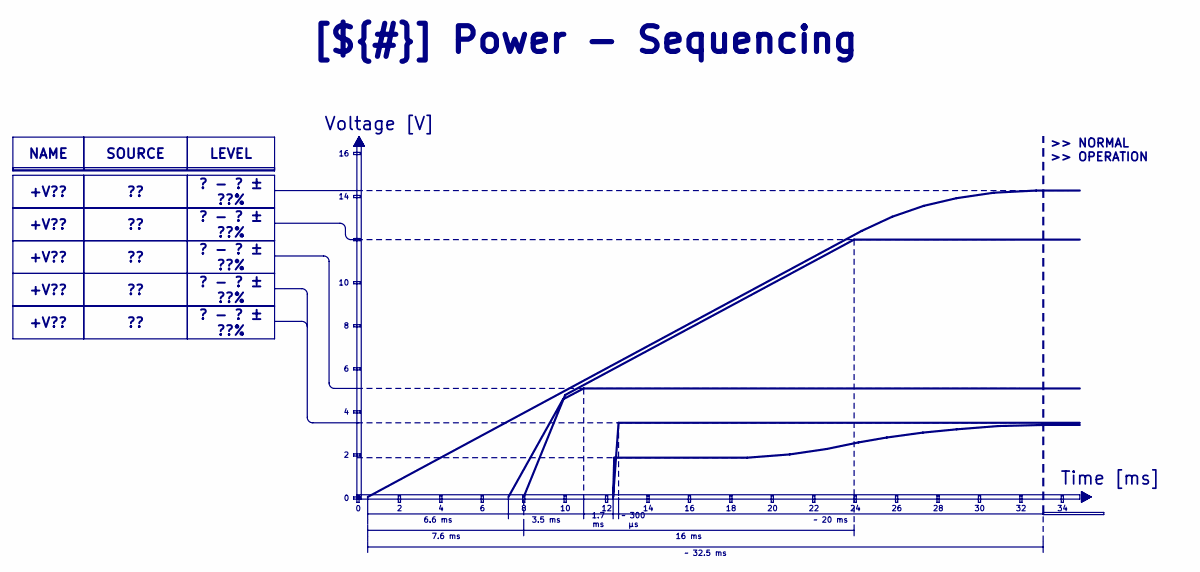
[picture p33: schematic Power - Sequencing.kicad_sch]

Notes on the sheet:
Voltage [V]
>> NORMAL >> OPERATION
Time [ms]
3.5 ms
7.6 ms
? - ? ± ??%
~ 300 μs
1.7 ms
16 ms
+V??
LEVEL
NAME
~ 20 ms
SOURCE
[${#}] ${TITLE}
6.6 ms
~ 32.5 ms

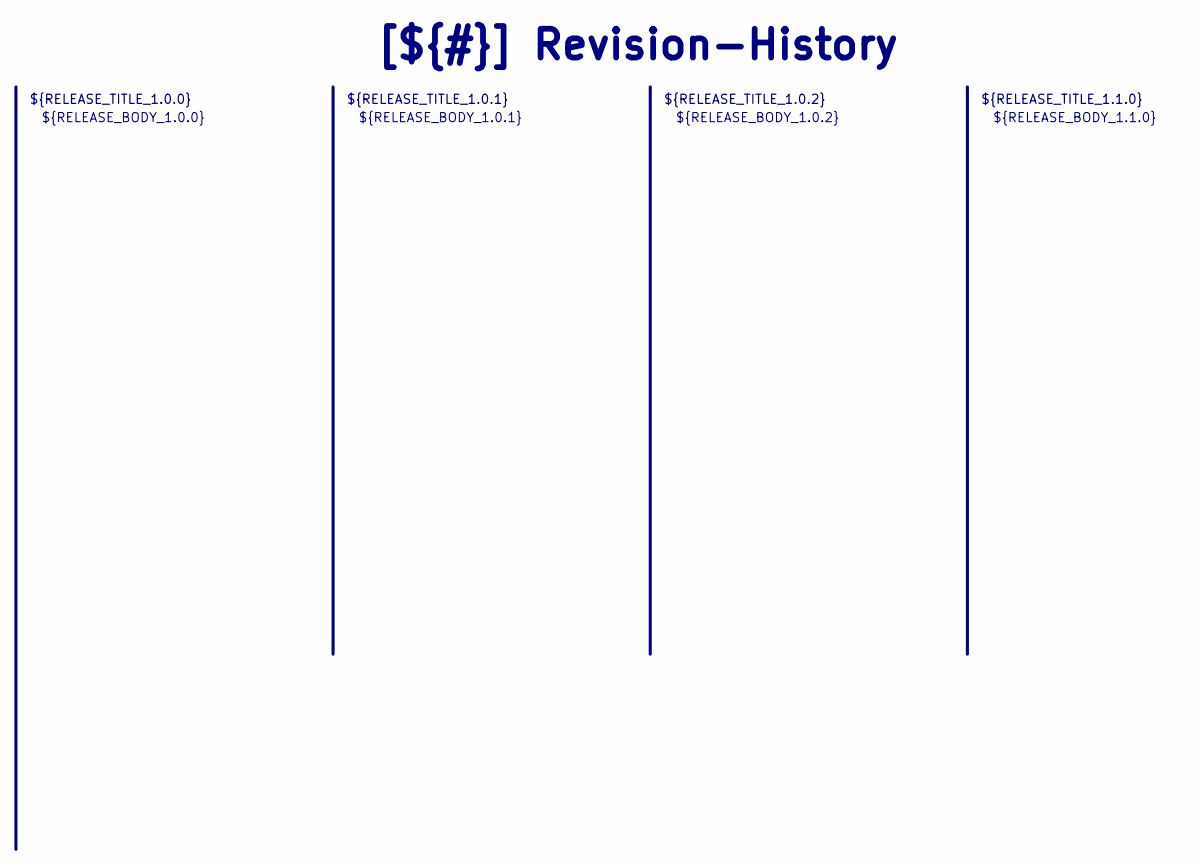
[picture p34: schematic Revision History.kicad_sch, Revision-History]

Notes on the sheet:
${RELEASE_BODY_1.1.0}
[${#}] ${TITLE}
${RELEASE_BODY_1.0.0}
${RELEASE_TITLE_1.0.2}
${RELEASE_BODY_1.0.2}
${RELEASE_BODY_1.0.1}
${RELEASE_TITLE_1.0.0}
${RELEASE_TITLE_1.0.1}
${RELEASE_TITLE_1.1.0}

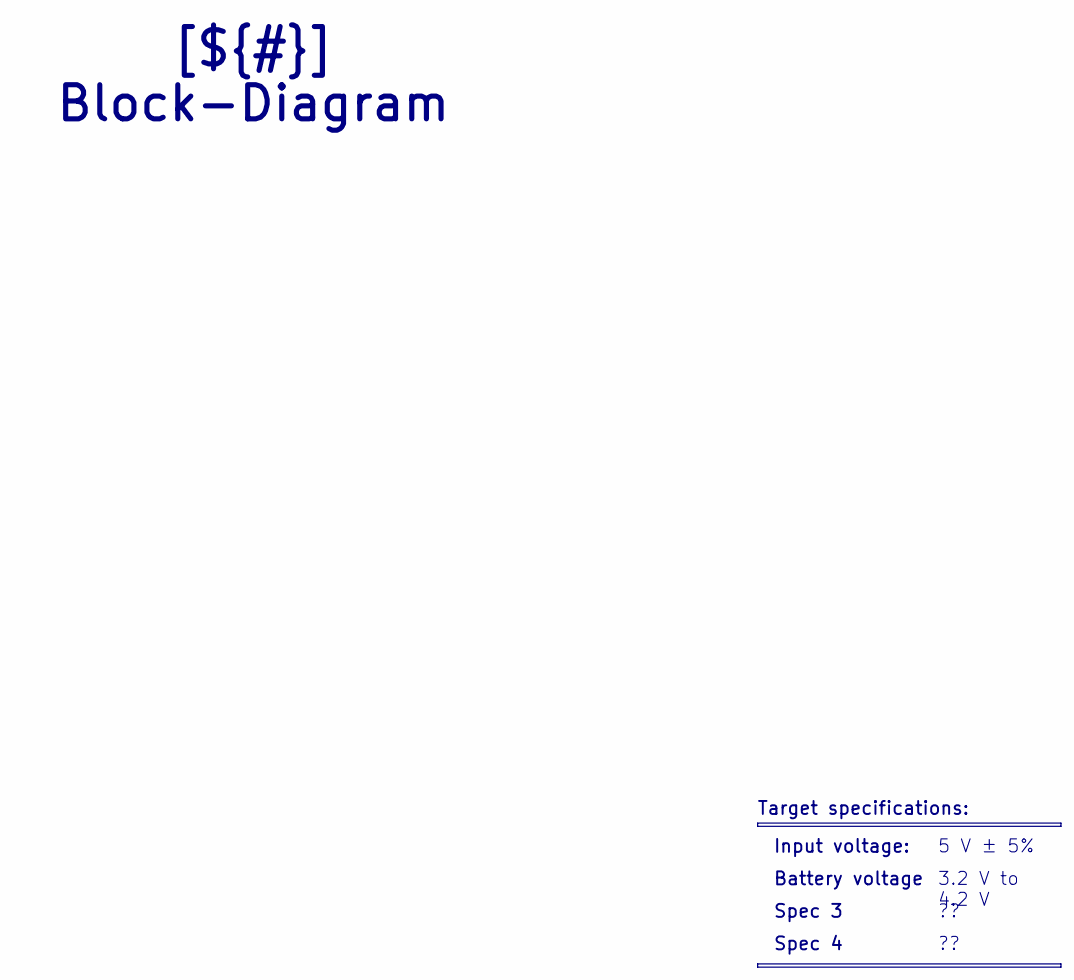
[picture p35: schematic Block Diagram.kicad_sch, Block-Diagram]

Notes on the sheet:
Spec 4
5 V ± 5%
[${#}] ${TITLE}
3.2 V to 4.2 V
Input voltage:
Target specifications:
Spec 3
Battery voltage

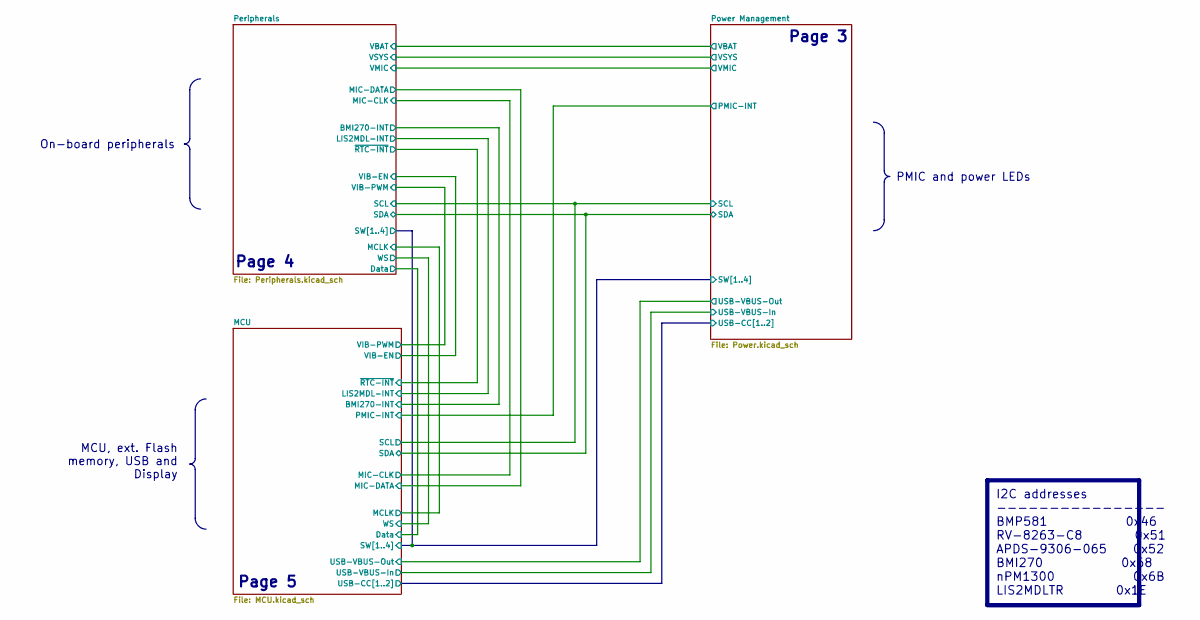
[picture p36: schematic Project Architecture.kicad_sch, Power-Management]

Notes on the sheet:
Page 5
Page 3
Page 4
MCU, ext. Flash memory, USB and Display
I2C addresses ---------------- BMP581 0x46 RV-8263-C8 0x51 APDS-9306-065 0x52 BMI270 0x68 nPM1300 0x6B LIS2MDLTR 0x1E
On-board peripherals
PMIC and power LEDs

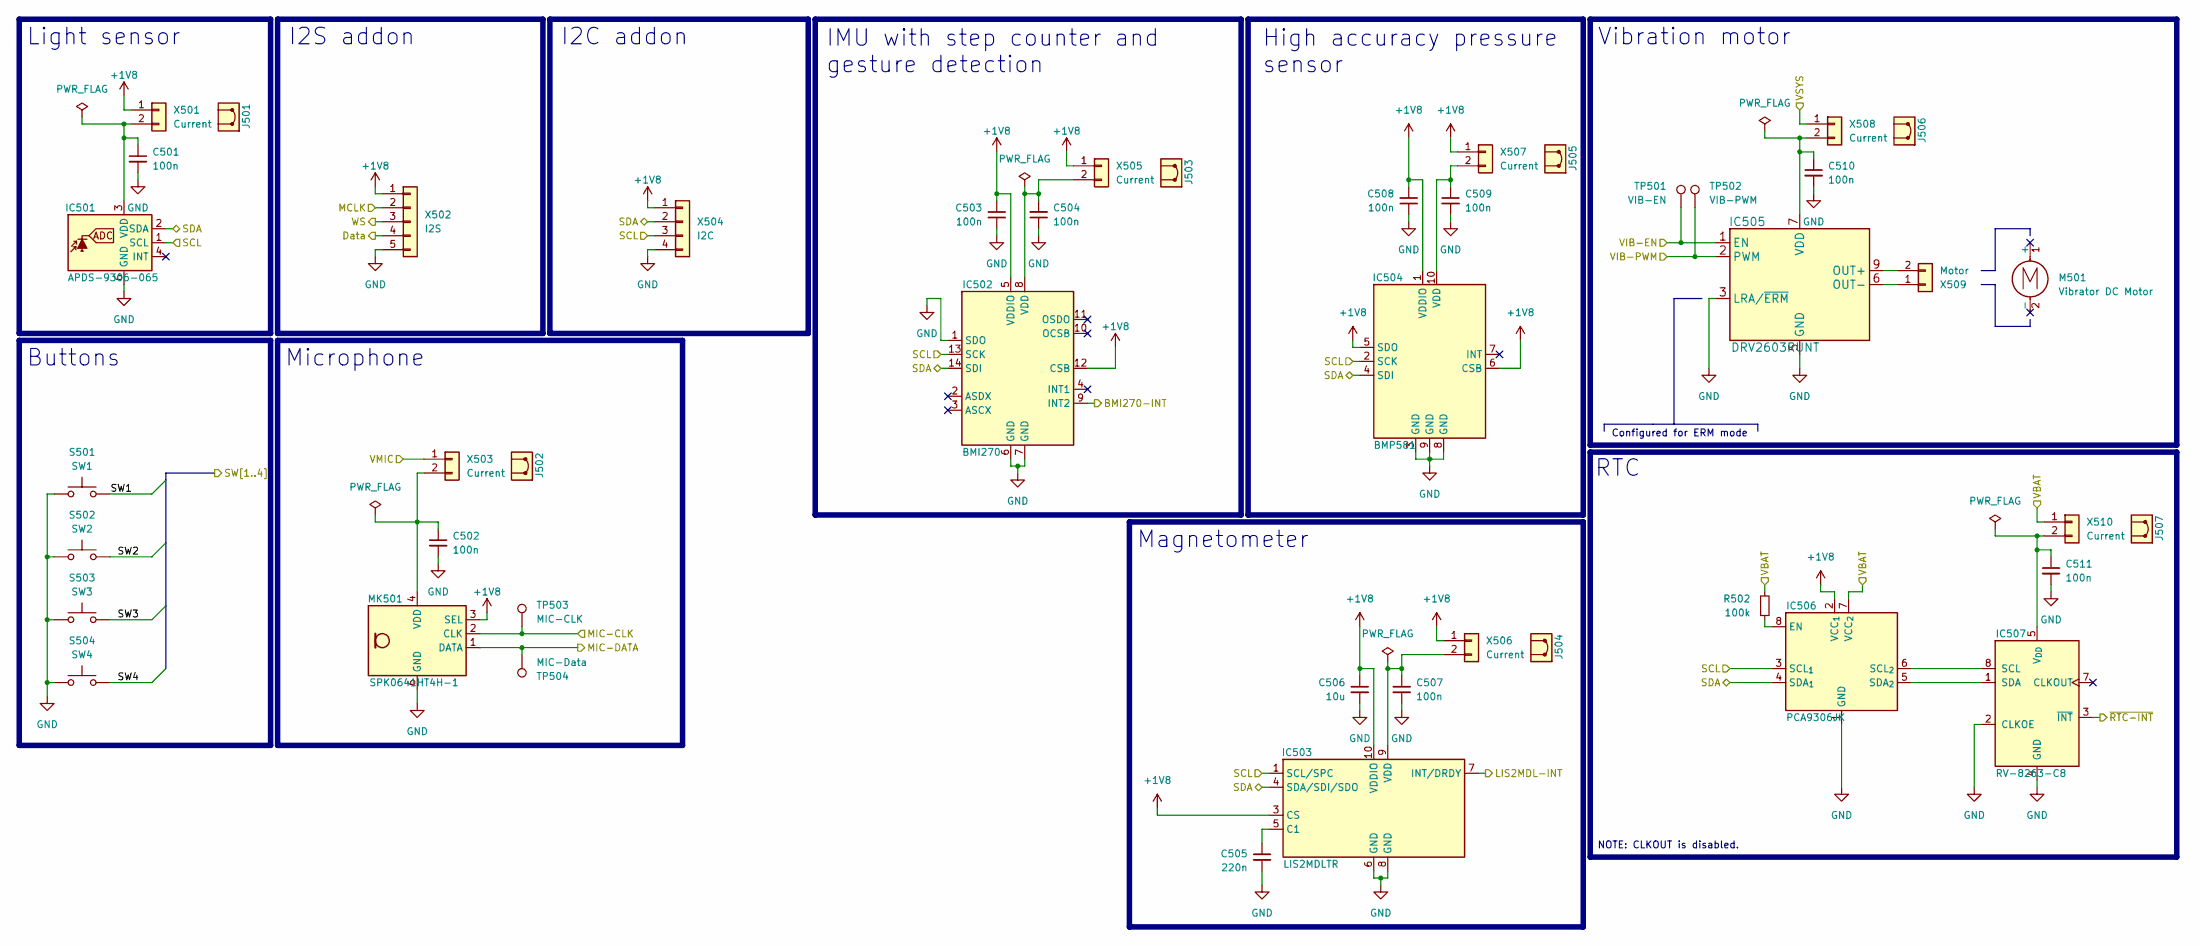
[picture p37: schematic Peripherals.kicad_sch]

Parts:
C501, C502, C503, C504, C507, C508, C509, C510, C511: 100n; C_0402_1005Metric; mouser# 581-0402ZC104KAT4A
C505: 220n; C_0402_1005Metric; mouser# 581-04023C224KAT2A
C506: 10u; C_0402_1005Metric; mouser# 81-GRJ155R60J106ME11D
IC501: APDS-9306-065; Broadcom_DFN-6_2x2mm_P0.65mm; mouser# 630-APDS-9306-065
IC502: BMI270; Bosch_LGA-14_3x2.5mm_P0.5mm_LayoutBorder3x4y; mouser# 262-BMI270
IC503: LIS2MDLTR; LGA-12_2x2mm_P0.5mm; mouser# 511-LIS2MDLTR
IC504: BMP581; Bosch_LGA-10_2x2mm_P0.5mm_ClockwisePinNumbering; mouser# 262-BMP581
IC505: DRV2603RUNT; WQFN-10_2x2mm_P0.5mm; mouser# 595-DRV2603RUNT
IC506: PCA9306JK; XSON-8_0.65x0.17mm_P0.35mm; mouser# 771-PCA9306JKZ
IC507: RV-8263-C8; mouser# 428-204291-MC01
J501, J502, J503, J504, J505, J506, J507: Jumper; mouser# 710-60900213421
M501: Vibrator DC Motor; digikey# 1670-VC1027B902F-ND
MK501: SPK0641HT4H-1; mouser# 721-SPK0641HT4H-1
R502: 100k; R_0402_1005Metric; mouser# 603-RC0404FR-07100KL
S501: SW1; WS-TASV-6x6; mouser# 710-430182050816
S502: SW2; WS-TASV-6x6; mouser# 710-430182050816
S503: SW3; WS-TASV-6x6; mouser# 710-430182050816
S504: SW4; WS-TASV-6x6; mouser# 710-430182050816
TP501: VIB-EN; TestPoint_Pad_D1.0mm
TP502: VIB-PWM; TestPoint_Pad_D1.0mm
TP503: MIC-CLK; TestPoint_Pad_D1.0mm
TP504: MIC-Data; TestPoint_Pad_D1.0mm
X501, X503, X505, X506, X507, X508, X510: Current; PinHeader_1x02_P2.54mm_Vertical; mouser# 649-77311-818-02LF
X502: I2S; PinHeader_1x05_P2.54mm_Vertical; mouser# 649-77311-818-05LF
X504: I2C; PinHeader_1x04_P2.54mm_Vertical; mouser# 649-77311-818-02LF
X509: Motor; 78171-0002; mouser# 538-78171-0002

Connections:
+1V8: C503.1, C506.1, C508.2, IC502.5 (VDDIO), IC502.12 (CSB), IC503.3 (CS), IC503.10 (VDDIO), IC504.1 (VDDIO), IC504.5 (SDO), IC504.6 (CSB), IC506.2 (VCC_{1}), MK501.3 (SEL), X501.1, X502.1, X504.1, X505.1, X506.1, X507.1; also elsewhere on the board
/Project Architecture/MCU/BMI270-INT: IC502.9 (INT2); also elsewhere on the board
/Project Architecture/MCU/Data: X502.4; also elsewhere on the board
/Project Architecture/MCU/LIS2MDL-INT: IC503.7 (INT/DRDY); also elsewhere on the board
/Project Architecture/MCU/MCLK: X502.2; also elsewhere on the board
/Project Architecture/MCU/MIC-CLK: MK501.2 (CLK), TP503.1; also elsewhere on the board
/Project Architecture/MCU/MIC-DATA: MK501.1 (DATA), TP504.1; also elsewhere on the board
/Project Architecture/MCU/SCL: IC501.1 (SCL), IC502.13 (SCK), IC503.1 (SCL/SPC), IC504.2 (SCK), IC506.3 (SCL_{1}), X504.3; also elsewhere on the board
/Project Architecture/MCU/SDA: IC501.2 (SDA), IC502.14 (SDI), IC503.4 (SDA/SDI/SDO), IC504.4 (SDI), IC506.4 (SDA_{1}), X504.2; also elsewhere on the board
/Project Architecture/MCU/SW1: S501.1; also elsewhere on the board
/Project Architecture/MCU/SW2: S502.2; also elsewhere on the board
/Project Architecture/MCU/SW3: S503.2; also elsewhere on the board
/Project Architecture/MCU/SW4: S504.1; also elsewhere on the board
/Project Architecture/MCU/VIB-EN: IC505.1 (EN), TP501.1; also elsewhere on the board
/Project Architecture/MCU/VIB-PWM: IC505.2 (PWM), TP502.1; also elsewhere on the board
/Project Architecture/MCU/WS: X502.3; also elsewhere on the board
/Project Architecture/MCU/~RTC-INT: IC507.3 (~INT); also elsewhere on the board
/Project Architecture/Peripherals/VBAT: IC506.7 (VCC_{2}), R502.2, X510.1; also elsewhere on the board
/Project Architecture/Peripherals/VMIC: X503.1; also elsewhere on the board
/Project Architecture/Power Management/VSYS: X508.1; also elsewhere on the board
GND: C501.2, C502.2, C503.2, C504.1, C505.2, C506.2, C507.2, C508.1, C509.2, C510.2, C511.2, IC501.6 (GND), IC502.1 (SDO), IC502.6 (GND), IC502.7 (GND), IC503.6 (GND), IC503.8 (GND), IC504.3 (GND), IC504.8 (GND), IC504.9 (GND), IC505.3 (LRA/~ERM), IC505.5 (GND), IC505.8 (GND), IC505.10 (GND), IC506.1 (GND), IC507.2 (CLKOE), IC507.4 (GND), MK501.5 (GND), MK501.6 (GND), MK501.7 (GND), MK501.8 (GND), S501.2, S502.1, S503.1, S504.2, X502.5, X504.4; also elsewhere on the board
unnamed: C501.1, IC501.3 (VDD), X501.2
unnamed: C504.2, IC502.8 (VDD), X505.2
unnamed: C505.1, IC503.5 (C1)
unnamed: C507.1, IC503.9 (VDD), X506.2
unnamed: C509.1, IC504.10 (VDD), X507.2
unnamed: IC505.9 (OUT+), X509.2
unnamed: IC505.6 (OUT-), X509.1
unnamed: C510.1, IC505.7 (VDD), X508.2
unnamed: IC506.8 (EN), R502.1
unnamed: IC506.6 (SCL_{2}), IC507.8 (SCL)
unnamed: IC506.5 (SDA_{2}), IC507.1 (SDA)
unnamed: C511.1, IC507.5 (V_{DD}), X510.2
unnamed: C502.1, MK501.4 (VDD), X503.2

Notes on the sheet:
Vibration motor
I2S addon
I2C addon
Magnetometer
Configured for ERM mode
High accuracy pressure sensor
Buttons
RTC
Microphone
Light sensor
IMU with step counter and gesture detection
NOTE: CLKOUT is disabled.

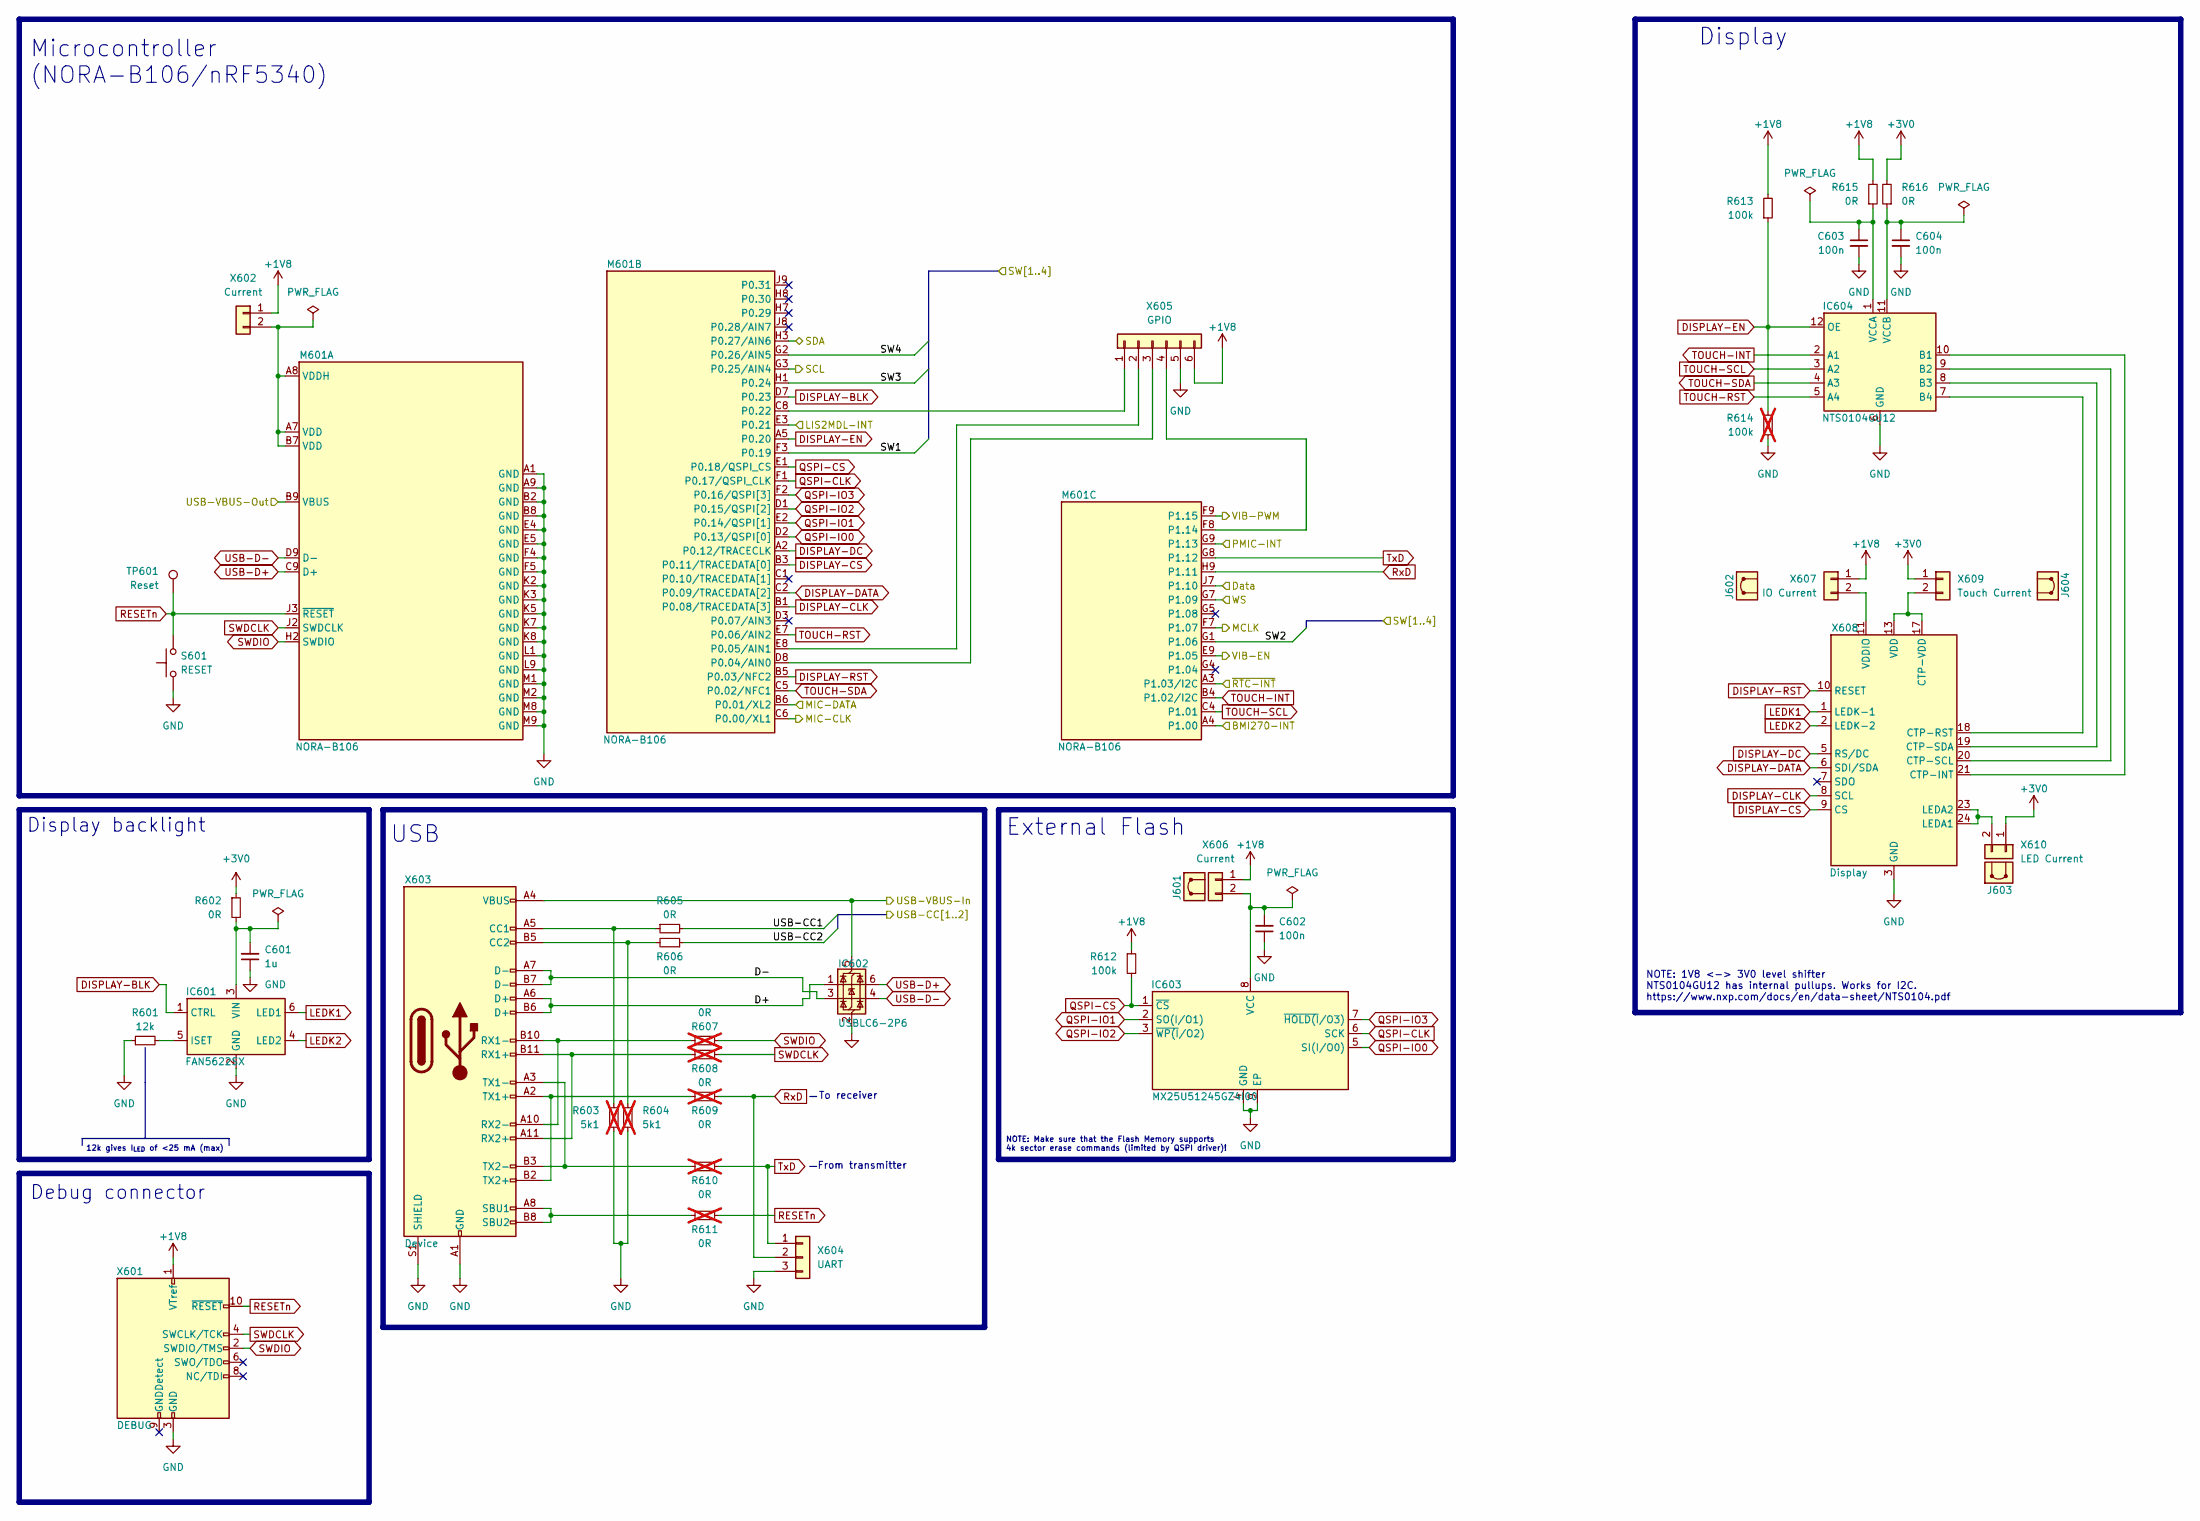
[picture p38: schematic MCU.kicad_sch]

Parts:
C601: 1u; C_0402_1005Metric; mouser# 581-04023D105KAT2A
C602, C603, C604: 100n; C_0402_1005Metric; mouser# 581-0402ZC104KAT4A
IC601: FAN5622SX; TSOT-23-6; mouser# 512-FAN5622SX
IC602: USBLC6-2P6; SOT-666; mouser# 511-USBLC6-2P6
IC603: MX25U51245GZ4I00; WSON-8-1EP_8x6mm_P1.27mm_EP3.4x4.3mm; mouser# 95-25U51245GZ4I00T
IC604: NTS0104GU12; XQFN-12-1.7x2mm_P0.4mm; mouser# 771-NTS0104GU12115
J601, J602, J603, J604: Jumper; mouser# 710-60900213421
M601: NORA-B106; mouser# 377-NORA-B106-00B
R601: 12k; R_0402_1005Metric; mouser# 603-RC0402FR-0712KL
R602, R605, R606, R615, R616: 0R; R_0805_2012Metric; mouser# 652-CR0805-J/-000ELF
R603, R604: 5k1; R_0402_1005Metric; mouser# 652-CR0402-FX-5101GLF; not fitted
R607, R608, R609, R610, R611: 0R; R_0805_2012Metric; mouser# 652-CR0805-J/-000ELF; not fitted
R612: 100k; R_0402_1005Metric; mouser# 603-RC0404FR-07100KL
R613: 100k; R_0805_2012Metric; mouser# 652-CR0805-J/-000ELF
R614: 100k; R_0805_2012Metric; mouser# 652-CR0805-JW-104ELF; not fitted
S601: RESET; WS-TASV-6x6; mouser# 710-430182050816
TP601: Reset; TestPoint_Pad_D1.0mm
X601: DEBUG; SHF-105-01-L-D-SM-TR; mouser# 710-62101021021
X602, X606: Current; PinHeader_1x02_P2.54mm_Vertical; mouser# 649-77311-818-02LF
X603: Device; USB_C_Receptacle_Amphenol_12401610E4-2A; mouser# 523-12401610E4#2A
X604: UART; PinHeader_1x03_P2.54mm_Vertical; mouser# 649-77311-818-03LF
X605: GPIO; PinHeader_1x06_P2.54mm_Vertical; mouser# 649-77311-802-06LF
X607: IO Current; PinHeader_1x02_P2.54mm_Vertical; mouser# 649-77311-818-02LF
X608: Display; ER-CON0.4-24P
X609: Touch Current; PinHeader_1x02_P2.54mm_Vertical; mouser# 649-77311-818-02LF
X610: LED Current; PinHeader_1x02_P2.54mm_Vertical; mouser# 649-77311-818-02LF

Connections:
+1V8: R612.1, R613.2, R615.2, X601.1 (VTref), X602.1, X605.6, X606.1, X607.1; also elsewhere on the board
+3V0: R602.1, R616.2, X609.1, X610.1; also elsewhere on the board
/Project Architecture/MCU/BMI270-INT: M601.A4 (P1.00); also elsewhere on the board
/Project Architecture/MCU/D+: IC602.1 (I/O1), X603.A6 (D+), X603.B6 (D+)
/Project Architecture/MCU/D-: IC602.3 (I/O2), X603.A7 (D-), X603.B7 (D-)
/Project Architecture/MCU/Data: M601.J7 (P1.10); also elsewhere on the board
/Project Architecture/MCU/LIS2MDL-INT: M601.E3 (P0.21); also elsewhere on the board
/Project Architecture/MCU/MCLK: M601.F7 (P1.07); also elsewhere on the board
/Project Architecture/MCU/MIC-CLK: M601.C6 (P0.00/XL1); also elsewhere on the board
/Project Architecture/MCU/MIC-DATA: M601.B6 (P0.01/XL2); also elsewhere on the board
/Project Architecture/MCU/PMIC-INT: M601.G9 (P1.13); also elsewhere on the board
/Project Architecture/MCU/SCL: M601.G3 (P0.25/AIN4); also elsewhere on the board
/Project Architecture/MCU/SDA: M601.H3 (P0.27/AIN6); also elsewhere on the board
/Project Architecture/MCU/SW1: M601.F3 (P0.19); also elsewhere on the board
/Project Architecture/MCU/SW2: M601.G1 (P1.06); also elsewhere on the board
/Project Architecture/MCU/SW3: M601.H1 (P0.24); also elsewhere on the board
/Project Architecture/MCU/SW4: M601.G2 (P0.26/AIN5); also elsewhere on the board
/Project Architecture/MCU/USB-CC1: R605.2; also elsewhere on the board
/Project Architecture/MCU/USB-CC2: R606.1; also elsewhere on the board
/Project Architecture/MCU/USB-VBUS-In: IC602.5 (VBUS), X603.A4 (VBUS), X603.A9 (VBUS), X603.B4 (VBUS), X603.B9 (VBUS); also elsewhere on the board
/Project Architecture/MCU/USB-VBUS-Out: M601.B9 (VBUS); also elsewhere on the board
/Project Architecture/MCU/VIB-EN: M601.E9 (P1.05); also elsewhere on the board
/Project Architecture/MCU/VIB-PWM: M601.F9 (P1.15); also elsewhere on the board
/Project Architecture/MCU/WS: M601.G7 (P1.09); also elsewhere on the board
/Project Architecture/MCU/~RTC-INT: M601.A3 (P1.03/I2C); also elsewhere on the board
DISPLAY-BLK: IC601.1 (CTRL), M601.D7 (P0.23)
DISPLAY-CLK: M601.B1 (P0.08/TRACEDATA[3]), X608.8 (SCL)
DISPLAY-CS: M601.B3 (P0.11/TRACEDATA[0]), X608.9 (CS)
DISPLAY-DATA: M601.C2 (P0.09/TRACEDATA[2]), X608.6 (SDI/SDA)
DISPLAY-DC: M601.A2 (P0.12/TRACECLK), X608.5 (RS/DC)
DISPLAY-EN: IC604.12 (OE), M601.A5 (P0.20), R613.1, R614.2
DISPLAY-RST: M601.B5 (P0.03/NFC2), X608.10 (RESET)
GND: C601.1, C602.1, C603.2, C604.2, IC601.2 (GND), IC602.2 (GND), IC603.4 (GND), IC603.9 (EP), IC604.6 (GND), M601.A1 (GND), M601.A9 (GND), M601.B2 (GND), M601.B8 (GND), M601.E4 (GND), M601.E5 (GND), M601.F4 (GND), M601.F5 (GND), M601.K2 (GND), M601.K3 (GND), M601.K5 (GND), M601.K7 (GND), M601.K8 (GND), M601.L1 (GND), M601.L9 (GND), M601.M1 (GND), M601.M2 (GND), M601.M8 (GND), M601.M9 (GND), R601.1, R603.2, R604.1, R614.1, S601.2, X601.3 (GND), X601.5 (GND), X603.A1 (GND), X603.A12 (GND), X603.B1 (GND), X603.B12 (GND), X603.S1 (SHIELD), X604.3, X605.5, X608.3 (GND), X608.4 (GND), X608.15 (GND), X608.16 (GND); also elsewhere on the board
LEDK1: IC601.6 (LED1), X608.1 (LEDK-1)
LEDK2: IC601.4 (LED2), X608.2 (LEDK-2)
unnamed: IC601.5 (ISET), R601.2
unnamed: C601.2, IC601.3 (VIN), R602.2
unnamed: C602.2, IC603.8 (VCC), X606.2
unnamed: IC604.10 (B1), X608.21 (CTP-INT)
unnamed: IC604.9 (B2), X608.20 (CTP-SCL)
unnamed: IC604.8 (B3), X608.19 (CTP-SDA)
unnamed: IC604.7 (B4), X608.18 (CTP-RST)
unnamed: C603.1, IC604.1 (VCCA), R615.1
unnamed: C604.1, IC604.11 (VCCB), R616.1
unnamed: M601.A7 (VDD), M601.A8 (VDDH), M601.B7 (VDD), X602.2
unnamed: M601.D8 (P0.04/AIN0), X605.3
unnamed: M601.E8 (P0.05/AIN1), X605.2
unnamed: M601.C8 (P0.22), X605.1
unnamed: M601.F8 (P1.14), X605.4
unnamed: R603.1, R605.1, X603.A5 (CC1)
unnamed: R604.2, R606.2, X603.B5 (CC2)
unnamed: R608.2, X603.A11 (RX2+), X603.B11 (RX1+)
unnamed: R607.2, X603.A10 (RX2-), X603.B10 (RX1-)
unnamed: R611.2, X603.A8 (SBU1), X603.B8 (SBU2)
unnamed: R609.2, X603.A2 (TX1+), X603.B2 (TX2+)
unnamed: R610.2, X603.A3 (TX1-), X603.B3 (TX2-)
unnamed: X607.2, X608.11 (VDDIO), X608.12 (VDDIO)
unnamed: X608.13 (VDD), X608.14 (VDD), X608.17 (CTP-VDD), X609.2
unnamed: X608.23 (LEDA2), X608.24 (LEDA1), X610.2
QSPI-CLK: IC603.6 (SCK), M601.F1 (P0.17/QSPI_CLK)
QSPI-CS: IC603.1 (~CS), M601.E1 (P0.18/QSPI_CS), R612.2
QSPI-IO0: IC603.5 (SI(I/O0)), M601.D2 (P0.13/QSPI[0])
QSPI-IO1: IC603.2 (SO(I/O1)), M601.E2 (P0.14/QSPI[1])
QSPI-IO2: IC603.3 (~WP(I/O2)), M601.D1 (P0.15/QSPI[2])
QSPI-IO3: IC603.7 (~HOLD(I/O3)), M601.F2 (P0.16/QSPI[3])
RESETn: M601.J3 (~RESET), R611.1, S601.1, TP601.1, X601.10 (~RESET)
RxD: M601.H9 (P1.11), R609.1, X604.2
SWDCLK: M601.J2 (SWDCLK), R608.1, X601.4 (SWCLK/TCK)
SWDIO: M601.H2 (SWDIO), R607.1, X601.2 (SWDIO/TMS)
TOUCH-INT: IC604.2 (A1), M601.B4 (P1.02/I2C)
TOUCH-RST: IC604.5 (A4), M601.E7 (P0.06/AIN2)
TOUCH-SCL: IC604.3 (A2), M601.C4 (P1.01)
TOUCH-SDA: IC604.4 (A3), M601.C5 (P0.02/NFC1)
TxD: M601.G8 (P1.12), R610.1, X604.1
USB-D+: IC602.6 (I/O1), M601.C9 (D+)
USB-D-: IC602.4 (I/O2), M601.D9 (D-)

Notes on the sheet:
From transmitter
To receiver
12k gives I_{LED} of <25 mA (max)
NOTE: Make sure that the Flash Memory supports 4k sector erase commands (limited by QSPI driver)!
Display backlight
Display
Debug connector
USB
NOTE: 1V8 <-> 3V0 level shifter NTS0104GU12 has internal pullups. Works for I2C. https://www.nxp.com/docs/en/data-sheet/NTS0104.pdf
Microcontroller (NORA-B106/nRF5340)
External Flash

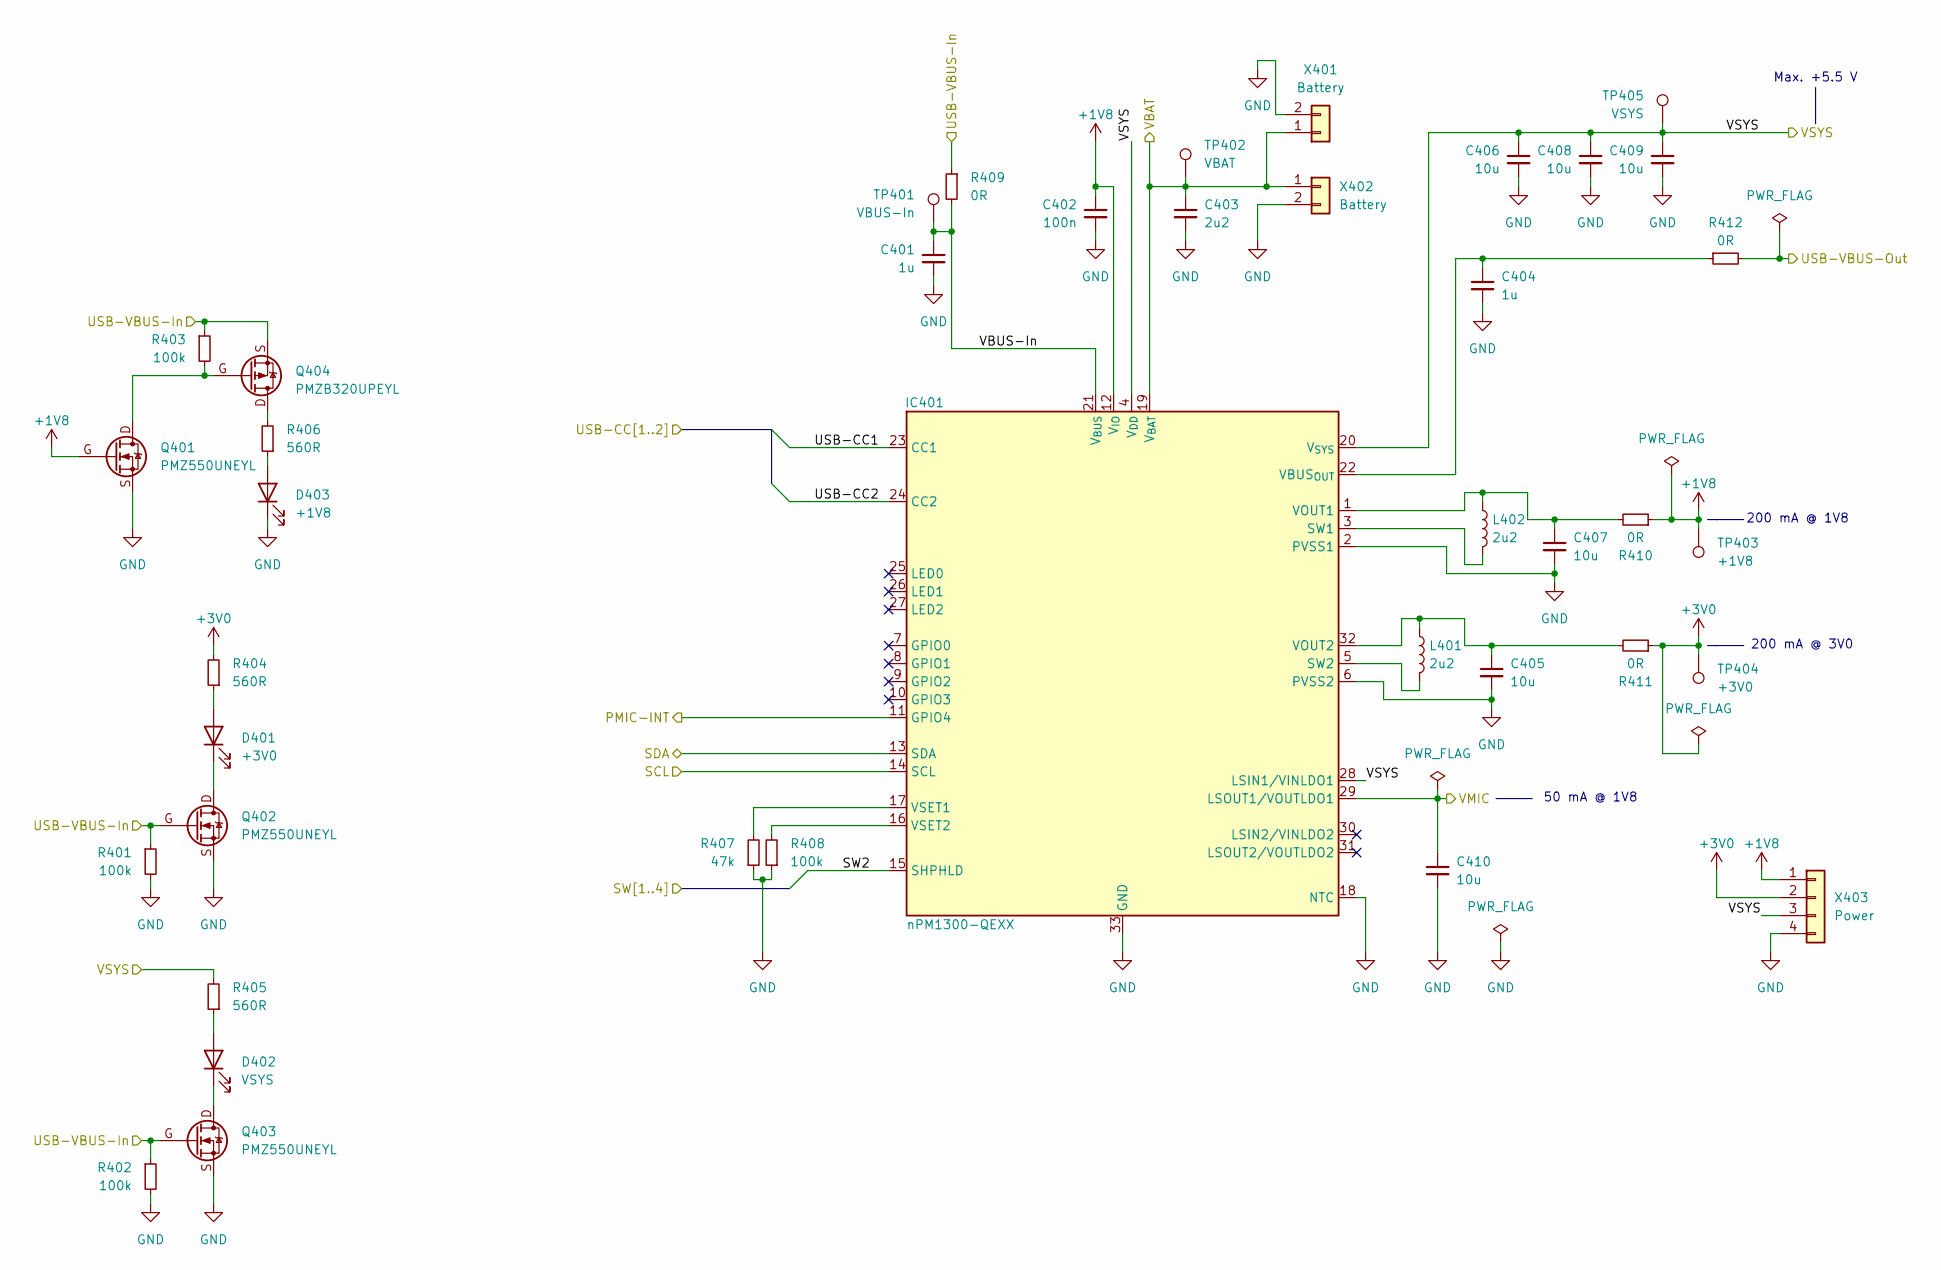
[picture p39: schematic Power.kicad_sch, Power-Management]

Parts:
C401, C404: 1u; C_0402_1005Metric; mouser# 581-04023D105KAT2A
C402: 100n; C_0402_1005Metric; mouser# 581-0402ZC104KAT4A
C403: 2u2; C_0402_1005Metric; mouser# 581-0402ZD225MAT2A
C405, C407, C410: 10u; C_0402_1005Metric; mouser# 81-GRJ155R60J106ME11D
C406, C408, C409: 10u; C_0603_1608Metric; mouser# 581-KGM15CR50J106MT
D401: +3V0; LED_0402_1005Metric; mouser# 696-SML-LX0402SUGCTR
D402: VSYS; LED_0402_1005Metric; mouser# 696-SML-LX0402SUGCTR
D403: +1V8; LED_0402_1005Metric; mouser# 696-SML-LX0402SUGCTR
IC401: nPM1300-QEXX; QFN-32-1EP_5x5mm_P0.5mm_EP3.6x3.6mm_ThermalVias; mouser# 949-NPM1300-QEAA-R7
L401, L402: 2u2; L_0806_2016; mouser# 815-ASMPH-0806-2R2M-T
Q401, Q402, Q403: PMZ550UNEYL; DFN-1006-3; mouser# 771-PMZ550UNEYL
Q404: PMZB320UPEYL; DFN-1006-3; mouser# 771-PMZB320UPEYL
R401, R402, R403, R408: 100k; R_0402_1005Metric; mouser# 603-RC0404FR-07100KL
R404, R405, R406: 560R; R_0402_1005Metric; mouser# 603-RC0402FR-07560RL
R407: 47k; R_0402_1005Metric; mouser# 603-RC0402FR-0747KL
R409, R410, R411, R412: 0R; R_0805_2012Metric; mouser# 652-CR0805-J/-000ELF
TP401: VBUS-In; TestPoint_Pad_D1.0mm
TP402: VBAT; TestPoint_Pad_D1.0mm
TP403: +1V8; TestPoint_Pad_D1.0mm
TP404: +3V0; TestPoint_Pad_D1.0mm
TP405: VSYS; TestPoint_Pad_D1.0mm
X401: Battery; PinHeader_1x02_P2.54mm_Vertical; mouser# 649-77311-818-02LF
X402: Battery; 78171-0002; mouser# 538-78171-0002
X403: Power; PinHeader_1x04_P2.54mm_Vertical; mouser# 649-77311-818-02LF

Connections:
+1V8: C402.1, IC401.12 (V_{IO}), Q401.G, R410.1, TP403.1, X403.1; also elsewhere on the board
+3V0: R404.2, R411.1, TP404.1, X403.2; also elsewhere on the board
/Project Architecture/MCU/PMIC-INT: IC401.11 (GPIO4); also elsewhere on the board
/Project Architecture/MCU/SCL: IC401.14 (SCL); also elsewhere on the board
/Project Architecture/MCU/SDA: IC401.13 (SDA); also elsewhere on the board
/Project Architecture/MCU/SW2: IC401.15 (SHPHLD); also elsewhere on the board
/Project Architecture/MCU/USB-CC1: IC401.23 (CC1); also elsewhere on the board
/Project Architecture/MCU/USB-CC2: IC401.24 (CC2); also elsewhere on the board
/Project Architecture/MCU/USB-VBUS-In: Q402.G, Q403.G, Q404.S, R401.1, R402.1, R403.1, R409.1; also elsewhere on the board
/Project Architecture/MCU/USB-VBUS-Out: R412.2; also elsewhere on the board
/Project Architecture/Peripherals/VBAT: C403.1, IC401.19 (V_{BAT}), TP402.1, X401.1, X402.1; also elsewhere on the board
/Project Architecture/Peripherals/VMIC: C410.1, IC401.29 (LSOUT1/VOUTLDO1); also elsewhere on the board
/Project Architecture/Power Management/VBUS-In: C401.1, IC401.21 (V_{BUS}), R409.2, TP401.1
/Project Architecture/Power Management/VSYS: C406.1, C408.1, C409.1, IC401.4 (V_{DD}), IC401.20 (V_{SYS}), IC401.28 (LSIN1/VINLDO1), R405.2, TP405.1, X403.3; also elsewhere on the board
GND: C401.2, C402.2, C403.2, C404.2, C405.2, C406.2, C407.2, C408.2, C409.2, C410.2, D403.1 (K), IC401.2 (PVSS1), IC401.6 (PVSS2), IC401.18 (NTC), IC401.33 (GND), Q401.S, Q402.S, Q403.S, R401.2, R402.2, R407.1, R408.1, X401.2, X402.2, X403.4; also elsewhere on the board
unnamed: D401.2 (A), R404.1
unnamed: D401.1 (K), Q402.D
unnamed: D402.2 (A), R405.1
unnamed: D402.1 (K), Q403.D
unnamed: D403.2 (A), R406.1
unnamed: IC401.3 (SW1), L402.2
unnamed: IC401.5 (SW2), L401.2
unnamed: C404.1, IC401.22 (VBUS_{OUT}), R412.1
unnamed: C407.1, IC401.1 (VOUT1), L402.1, R410.2
unnamed: C405.1, IC401.32 (VOUT2), L401.1, R411.2
unnamed: IC401.17 (VSET1), R407.2
unnamed: IC401.16 (VSET2), R408.2
unnamed: Q401.D, Q404.G, R403.2
unnamed: Q404.D, R406.2

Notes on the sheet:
50 mA @ 1V8
200 mA @ 1V8
Max. +5.5 V
200 mA @ 3V0

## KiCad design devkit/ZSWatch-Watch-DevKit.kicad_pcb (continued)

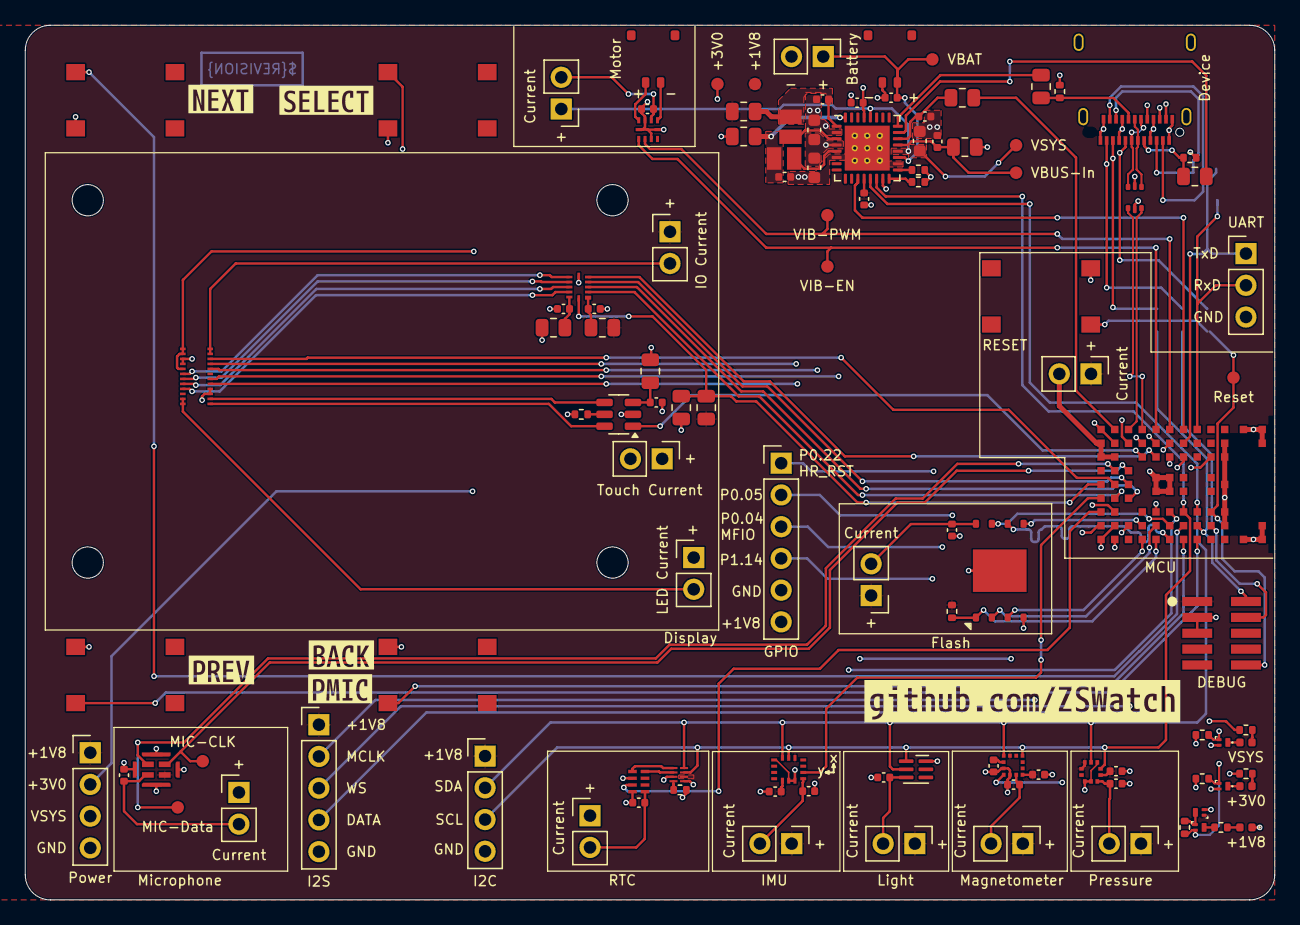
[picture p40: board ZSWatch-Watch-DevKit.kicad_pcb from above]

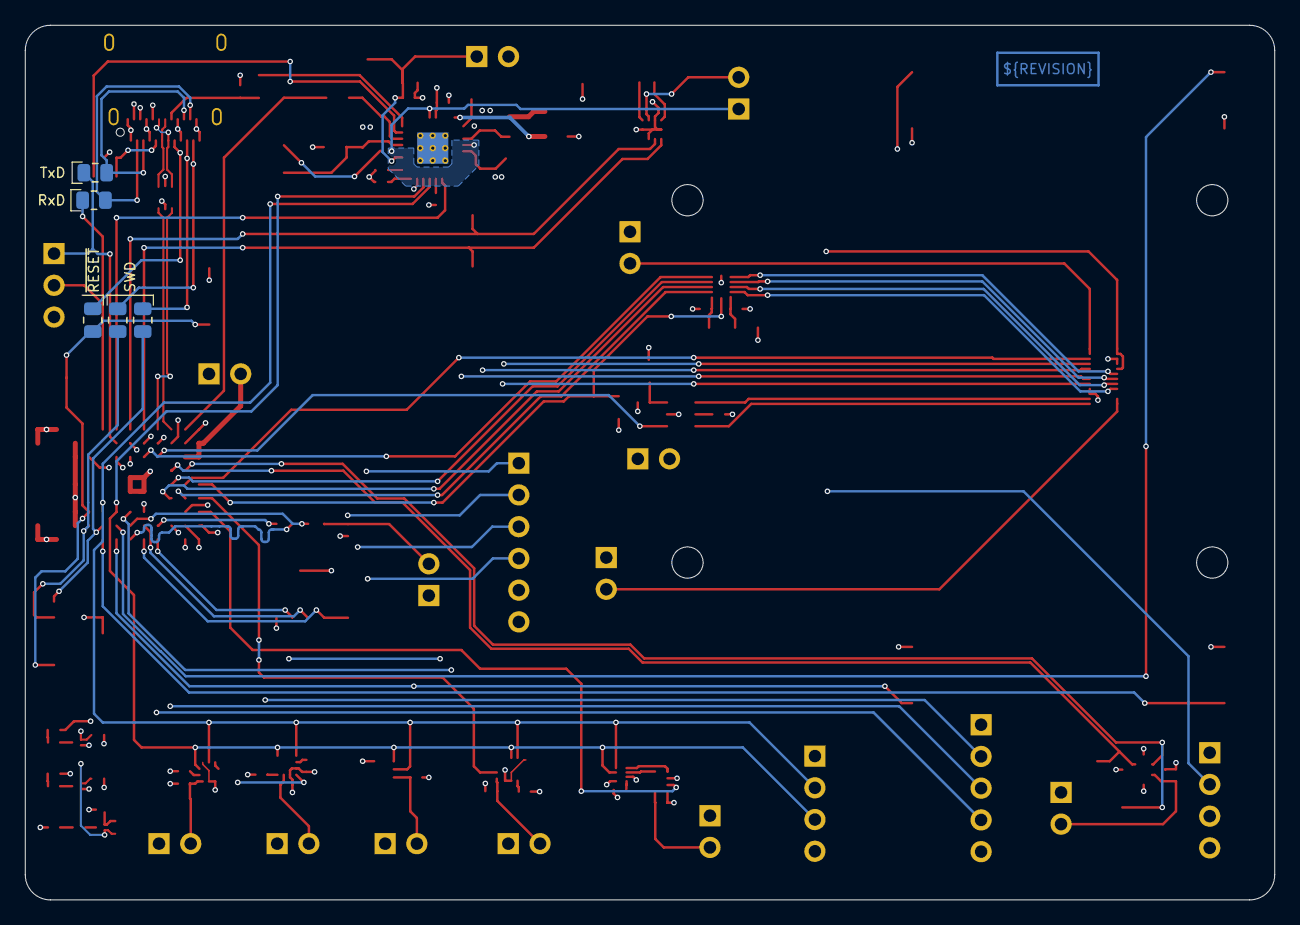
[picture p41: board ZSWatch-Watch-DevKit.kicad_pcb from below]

Board: 4 copper layers, 100.0 x 70.0 mm, 121 parts (5 on the bottom side), 107 nets.

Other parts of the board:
kibuzzard-683075F5: G***; kibuzzard-683075F5
kibuzzard-6830428E: G***; kibuzzard-6830428E
kibuzzard-68303879: G***; kibuzzard-68303879
kibuzzard-68304278: G***; kibuzzard-68304278
kibuzzard-68304289: G***; kibuzzard-68304289
kibuzzard-68304292: G***; kibuzzard-68304292

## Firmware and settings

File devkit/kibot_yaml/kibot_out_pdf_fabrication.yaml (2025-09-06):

# KiBot output for generating Fabrication Document in PDF format
# https://kibot.readthedocs.io/en/latest/configuration/outputs/pcb_print.html

kibot:
  version: 1

outputs:
- name: @NAME@
  comment: '@COMMENT@'
  type: pcb_print
  category: '@DIR@'
  dir: '@DIR@'
  options:
    colored_pads: false
    colored_vias: false
    color_theme: '@COLOR_THEME@'
    output: '%f-fabrication%I%v.%x'
    format: 'PDF'
    title: '@DOC_TITLE@ Document'
    realistic_solder_mask: false
    dpi: 1200
    dnf_filter: _kibom_dnf_Config
    frame_plot_mechanism: 'internal' 
    sheet_reference_layout: '@SHEET_WKS@'
    drill:
      unify_pth_and_npth: '@PTH_NPTH@'
      group_slots_and_round_holes: @GROUP_ROUND_SLOTS@
    include_table:
      outputs:
        - name: '@NAME_TP_TOP@'
          text_alignment: 'left'
          invert_columns_order: false
          border_width: 0.4
          header_rule_width: 0.2
          horizontal_rule_width: 0
          vertical_rule_width: 0.2
          top_rule_width: 0.2
          bottom_rule_width: 0.2
          column_spacing: 2
          force_font_width: 1.27 # mm
        - name: '@NAME_TP_BOTTOM@'
          text_alignment: 'right'
          invert_columns_order: true
          border_width: 0.4
          header_rule_width: 0.2
          horizontal_rule_width: 0
          vertical_rule_width: 0.2
          top_rule_width: 0.2
          bottom_rule_width: 0.2
          column_spacing: 2
          force_font_width: 1.27 # mm
        - name: '@NAME_IMPEDANCE_TABLE@'
          text_alignment: 'left'
          invert_columns_order: false
          border_width: 0.4
          header_rule_width: 0.2
          horizontal_rule_width: 0
          vertical_rule_width: 0.2
          top_rule_width: 0.2
          bottom_rule_width: 0.2
          row_spacing: 3
          column_spacing: 2
          row_spacing: 3
        - name: '@NAME_DRILL_TABLE@'
          text_alignment: 'left'
          invert_columns_order: false
          border_width: 0.4
          header_rule_width: 0.2
          horizontal_rule_width: 0
          vertical_rule_width: 0.2
          top_rule_width: 0.2
          bottom_rule_width: 0.2
          row_spacing: 3
          column_spacing: 2
          force_font_width: 1 # mm

    pages:
      - scaling: @SCALING@
        title: '@DOC_TITLE@'
        sheet: 'Top Fabrication (Scale @SCALING@:1)'
        layer_var: 'Top Fabrication (Scale @SCALING@:1)'
        sheet_reference_color: '#000000'
        colored_holes: true
        holes_color: "#FFFFFF"
        layers:
          - layer: Edge.Cuts
            color: '#000000'
          - layer: F.Cu
            color: '#F2F2F2'
          - layer: F.Mask
            color: '#E2E2E2'
          - layer: F.Paste
            color: '#E2E2E2'
          - layer: F.Silkscreen
            color: '#DBDBDB'
          - layer: F.Fab
            plot_footprint_refs: false
            plot_footprint_values: false
            color: '#818181'
          - layer: F.Dimensions
            color: '#000000'

      - scaling: @SCALING@
        mirror: true
        mirror_pcb_text: false
        title: '@DOC_TITLE@'
        sheet: 'Bottom Fabrication (Scale @SCALING@:1)'
        layer_var: 'Bottom Fabrication (Scale @SCALING@:1)'
        sheet_reference_color: '#000000'
        colored_holes: true
        holes_color: "#FFFFFF"
        layers:
          - layer: Edge.Cuts
            color: '#000000'
          - layer: B.Cu
            color: '#F2F2F2'
          - layer: B.Mask
            color: '#E2E2E2'
          - layer: B.Paste
            color: '#E2E2E2'
          - layer: B.Silkscreen
            color: '#DBDBDB'
          - layer: B.Fab
            plot_footprint_refs: false
            plot_footprint_values: false
            color: '#818181'
          - layer: B.Dimensions
            color: '#000000'

      - scaling: @SCALING@
        title: '@DOC_TITLE@'
        sheet: 'Drill Drawing (%lp)'
        layer_var: 'Drill Drawing %lp (Scale @SCALING@:1)'
        sheet_reference_color: '#000000'
        colored_holes: true
        holes_color: "#FFFFFF"
        repeat_for_layer: '@LAYER_DRILL_MAP@'
        repeat_layers: 'drill_pairs'
        layers:
          - layer: '@LAYER_DRILL_MAP@'
            color: '#000000'
          - layer: 'Edge.Cuts'
            color: '#000000'
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

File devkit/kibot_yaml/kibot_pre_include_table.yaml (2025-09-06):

# KiBot preflight for Include Table feature
# https://kibot.readthedocs.io/en/latest/configuration/preflights/include_table.html

kibot:
  version: 1

preflight:
  include_table:
    outputs:
      - name: '@NAME_TP_TOP@'
        text_alignment: 'left'
        invert_columns_order: false
        border_width: 0.2
        header_rule_width: 0.2
        horizontal_rule_width: 0
        vertical_rule_width: 0
        top_rule_width: 0
        bottom_rule_width: 0
        column_spacing: 1
        # force_font_width: 1.27 # mm
      - name: '@NAME_TP_BOTTOM@'
        text_alignment: 'right'
        invert_columns_order: true
        border_width: 0.2
        header_rule_width: 0.2
        horizontal_rule_width: 0
        vertical_rule_width: 0
        top_rule_width: 0
        bottom_rule_width: 0
        column_spacing: 1
        # force_font_width: 1.27 # mm
      - name: '@NAME_COMP_COUNT@'
        text_alignment: 'left'
        invert_columns_order: false
        border_width: 0.2
        header_rule_width: 0.2
        horizontal_rule_width: 0
        vertical_rule_width: 0
        top_rule_width: 0
        bottom_rule_width: 0
        row_spacing: 3
        column_spacing: 1
      - name: '@NAME_IMPEDANCE_TABLE@'
        text_alignment: 'left'
        invert_columns_order: false
        border_width: 0.2
        header_rule_width: 0.2
        vertical_rule_width: 0
        top_rule_width: 0
        bottom_rule_width: 0
        row_spacing: 3
        column_spacing: 1

...
definitions:
  NAME_TP_TOP: csv_testpoints_top
  NAME_TP_BOTTOM: csv_testpoints_bottom
  NAME_COMP_COUNT: csv_comp_count
  NAME_IMPEDANCE_TABLE: csv_impedance_table

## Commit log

2025-09-06 Release Watch-DK revision 1
    - Remove PCB prints from directory
2025-09-06 Prepare release
    - Remove old files
    - Update CI/CD pipeline
    - Fix ERC issues
    - Fix DRC issues
    - Update README
    - Add changelog for v1.2.0
    - Add missing datasheets
    - Issue #126
    [Block Diagram.kicad_sch, MCU.kicad_sch, Peripherals.kicad_sch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]
2025-09-06 Update outputs (release)
    [ZSWatch-Watch-DevKit-(L1-L4)_NPTH_drill_table.csv, ZSWatch-Watch-DevKit-(L1-L4)_drill_table.csv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]
2025-09-07 Push outputs from CI/CD (2025-09-07 19:59:51)
    [ZSWatch-Watch-DevKit-(L1-L4)_NPTH_drill_table.csv, ZSWatch-Watch-DevKit-(L1-L4)_drill_table.csv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]
